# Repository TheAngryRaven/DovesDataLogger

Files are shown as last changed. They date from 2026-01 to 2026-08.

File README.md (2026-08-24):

# BirdsEye - GPS Lap Timer & Data Logger







A high-precision GPS-based lap timer and data logger designed for motorsports and track day enthusiasts. Features 25Hz logging, sector timing, RPM monitoring via tachometer, and multiple customizable display pages.

<p align="center">
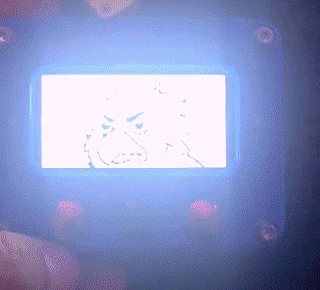
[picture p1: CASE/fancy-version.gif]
  
</p>
<p align="center">
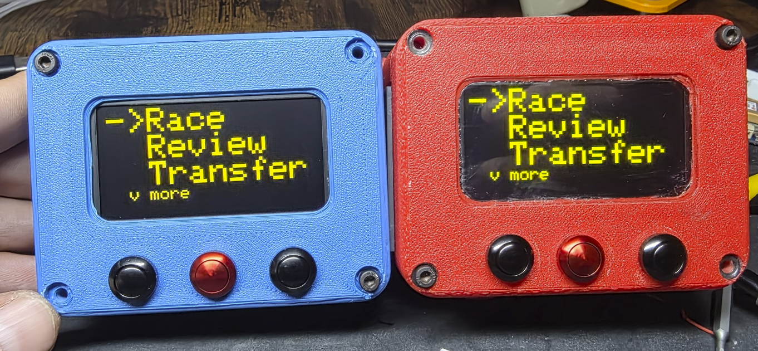
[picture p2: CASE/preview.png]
  
</p>
<p align="center">
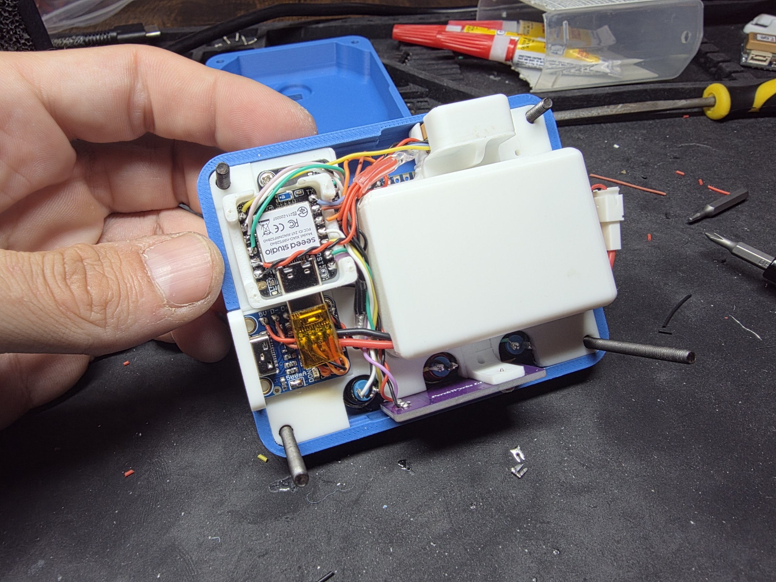
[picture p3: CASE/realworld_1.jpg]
  
</p>

## Features

### Core Functionality
- **25Hz GPS Logging** - High-frequency data capture straight to SD card
- **Accelerometer** - On-board 6-axis IMU when using Seeed XIAO nRF52840 Sense, +/-16g
- **RPM Monitoring** - Tachometer input with noise filtering for ignition systems
- **"Just Drive" Mode** - Automatic track detection, course detection, and lap timing — no manual selection needed
- **Sector Timing** - Optional 2 and 3-sector support for detailed performance analysis
- **Lap Anything** - Automatic waypoint-based lap timing when no track files match or no sectors configured
- **Lap Timing** - Current lap, best lap, last lap, and optimal lap calculation
- **Pace Comparison** - Real-time pace difference vs. best lap
- **Lap History** - Session-based lap history (up to 1000 laps)
- **Speed Display** - Large, easy-to-read speed display
- **Auto Power-Off** - Full shutdown (nRF52 System OFF, ~µA) instead of sleep — wakes on button press, engine start (tach pulse), or USB plug-in; no power switch needed
- **GPS Status Page** - Every boot shows a MyChron-style satellite view (sat count, HDOP, per-satellite signal bars) until GPS locks; any button skips it
- **DOVEX Format** - Crash-safe logging with reserved header for instant replay
- **Review Data** - Instant replay of DOVEX session headers on-device
- **Insta360 cameras pairing** - Automatically turn on, start recording, and sync GPS data directly to your camera once a session starts

#### WebApp Features (no login)
- **Bluetooth Downloads** - Can now download files directly to [LapWingData.com](https://LapWingData.com)
- **Bluetooth Firmware updates** - update from the latest stable or the experimental beta branch releases
- **Configure settings** - none of us want to fill in text with three buttons
- **Track Sync** - Update on-device track library via the webapp

#### To-Do
- **External Sensors** - Add thermocouple sensor / m8 circle connector
- **Pin Lock** - require pin to pull logs from device

### Display Pages
- GPS Status (boot page: satellites, HDOP, lock state, per-satellite signal bars)
- GPS Statistics (battery, satellites, HDOP, logging status)
- Speed (with current lap number)
- Tachometer (RPM with max RPM tracking)
- Current Lap Time
- Pace Off Best Lap (visual indicators when beating best)
- Best Lap Time
- Optimal Lap (combined best sectors with lap numbers)
- Lap History (paginated list)
- GPS Debug (distance to line, crossing status, etc.)

### Track Configuration
- Loads track layouts from JSON files on SD card
- Support for forward/reverse direction selection
- Optional sector timing lines (2 and 3 sectors)
- Easy to add new tracks - just add a JSON file

## Hardware Requirements

### Core Components
- **MCU**: Seeed XIAO nRF52840 Sense (64MHz ARM Cortex-M4 with FPU + BLE 5.0 + 6-axis IMU)
  - ~120 mA active draw with 2.45" screen; System OFF when powered down (µA-class + GPS backup draw)
  - Built-in battery charging circuit (BQ25101)
- **GPS**: u-blox SAM-M10Q (Matek SAM-M10Q recommended, found from most RC hobby shops)
  - Configured for 25Hz UBX binary (PVT) update rate
  - GPS-only constellation for maximum nav rate
  - **TODO** Update GPS tray to use bare $15 GPS module, battery backup is optional
- **Display**: 2.45" 128x64 OLED (SH110X or SSD1306 compatible)
  - I2C interface (address: 0x3C)
  - Software sleep/wake via I2C commands (~10uA when off)
- **SD Card**: Standard SD card module
  - FAT16/FAT32 formatted
  - 1 MHz SPI for EMI resistance
- **Battery**: 1500mAh 103050 LiPo
  - ~12.5 hours active; weeks-to-months powered down (System OFF)
- **Buttons**: 3x momentary pushbuttons for navigation
  - Left, Select/Enter, Right
  - RC low-pass filters recommended (10K + 100nF) for EMI rejection

### Optional Components
- **Tachometer Circuit**: Inductive pickup for RPM sensing
  - Input on pin D0
  - Noise filtering for ignition systems
  - *Circuit diagram: `tachometer-circuit.jpg` (README coming soon)*
  - diagram is missing required optocoupler and isolated dc-dc power supply

### Power Usage
- Active draw: ~120 mA with 2.45" OLED display
- Active battery life: ~12.5 hours continuous on 1500 mAh
- Powered down: nRF52 System OFF (µA-class MCU draw; GPS backup mode + board
  quiescent draw dominate) — expected weeks-to-months on 1500 mAh (bench
  measurement pending)
- Battery percentage and voltage displayed on stats page and charging screen

## Track Loading System

### How It Works

The system loads track configurations from JSON files stored on the SD card. Each track file can contain multiple layouts (e.g., "Full Course", "Short Course", "Chicane Bypass").

### SD Card Structure

```
SDCARD/
└── TRACKS/
    ├── OKC.json
    ├── BMP.json
    ├── PIQUET.json
    └── [your-track].json
```

### Track JSON Format

Two formats are supported. The device auto-detects which format is used.

**New format** (recommended, can use [LapWingData.com](https://LapWingData.com) to update tracks on the device):

```json
{
  "longName": "Orlando Kart Center",
  "shortName": "OKC",
  "defaultCourse": "Normal",
  "courses": [
    {
      "name": "Normal",
      "lengthFt": 3383,
      "start_a_lat": 28.4127081705638,
      "start_a_lng": -81.3797326641803,
      "start_b_lat": 28.4127303867932,
      "start_b_lng": -81.3795704875378,
      "sector_2_a_lat": 28.4119049886871,
      "sector_2_a_lng": -81.3790708193926,
      "sector_2_b_lat": 28.4118316342961,
      "sector_2_b_lng": -81.3791856652217,
      "sector_3_a_lat": 28.4115010664104,
      "sector_3_a_lng": -81.3799856475317,
      "sector_3_b_lat": 28.4115084390461,
      "sector_3_b_lng": -81.3798064021136
    }
  ]
}
```

**Older format** (still parsed, but the device falls back to Lap Anything because there's no `lengthFt` for course detection to rank by):

```json
[
  {
    "name": "Full Course",
    "start_a_lat": 28.41270817,
    "start_a_lng": -81.37973266,
    "start_b_lat": 28.41273039,
    "start_b_lng": -81.37957049,
    "sector_2_a_lat": 28.41190499,
    "sector_2_a_lng": -81.37907082,
    "sector_2_b_lat": 28.41183163,
    "sector_2_b_lng": -81.37918567
  }
]
```

**New format fields:**
- `longName` / `shortName`: track display names
- `defaultCourse`: which course to prefer (used by CourseDetector)
- `courses[].lengthFt`: track length in feet (enables automatic course detection ranking)

**Coordinate Requirements:**
- **Start/Finish Line**: `start_a_lat`, `start_a_lng`, `start_b_lat`, `start_b_lng` (required)
- **Sector 2 Line**: `sector_2_a_lat`, `sector_2_a_lng`, `sector_2_b_lat`, `sector_2_b_lng` (optional)
- **Sector 3 Line**: `sector_3_a_lat`, `sector_3_a_lng`, `sector_3_b_lat`, `sector_3_b_lng` (optional)

Each line is defined by two GPS coordinate points (A and B). The system detects crossing when you pass through the line segment between these points.

**Getting Coordinates:**
Use [Google Maps](https://maps.google.com) or your preferred mapping tool:
1. Right-click on a point → Copy coordinates
2. Paste into JSON (format: latitude, longitude)
3. Precision: 8 decimal places recommended for racing accuracy

### Adding a New Track

1. Create a new `.json` file in `SDCARD/TRACKS/` directory
2. Use the format shown above
3. Filename should be short (max 8 characters for FAT16 compatibility)
4. Example: `LAGUNA.json`, `COTA.json`, `BRANDS.json`

The track will automatically appear in the track selection menu on next boot.

## Device Settings

Settings are stored in `/SETTINGS.json` on the SD card. The file is created automatically on first boot with random default values. Missing keys are auto-populated on boot when firmware is updated.

```json
{
  "bluetooth_name": "DovesDataLogger-042",
  "bluetooth_pin": "7391",
  "driver_name": "Driver",
  "lap_detection_distance": "7",
  "waypoint_detection_distance": "30",
  "waypoint_speed": "30",
  "spark_mode": "wasted",
  "cylinder_count": "1",
  "display_invert": "normal"
}
```

| Setting | Description | Default |
|---|---|---|
| `bluetooth_name` | BLE device name visible during pairing | Random (e.g. `DovesDataLogger-042`) |
| `bluetooth_pin` | PIN displayed on device for webapp pairing | Random 4-digit |
| `race_mode` | Circuit-vs-sprint tiebreak when both track kinds are within detection range (`sprint` always prefers the sprint track; `circuit` yields only on an event day) | `circuit` |
| `driver_name` | Driver name logged in DOVEX session header | `Driver` |
| `lap_detection_distance` | Crossing detection threshold in meters | `7` |
| `waypoint_detection_distance` | Waypoint proximity zone in meters (Lap Anything) | `30` |
| `waypoint_speed` | Minimum speed in mph to activate lap timing | `30` |
| `spark_mode` | How often the plug on the clamped wire fires — the **only** setting that scales RPM: `wasted` = once per revolution (2-stroke, or 4-stroke wasted spark), `single` = once per two revolutions (4-stroke single-fire, i.e. a traditional distributor or magneto) | `wasted` |
| `display_invert` | Screen colours: `normal` is the white-on-black it has always been, `inverted` swaps them (black text on a lit screen) for glare | `normal` |
| `cylinder_count` | The engine's **actual** cylinder count — enter 8 for a V8. It does **not** scale RPM: the pickup is one clamp on one plug wire, so it sees one cylinder's ignition and `spark_mode` alone sets the math. ⚠️ Above 1 cylinder, crank RPM is **inferred from that one cylinder's ignition pulses** — between firings the reading is an assumption, and a cylinder that drops out reads as a stopped engine. This is normal, expected behaviour for every clamp-on inductive tach | `1` |

## Data Format

DOVEX files (`.dovex`) use a reserved **1 KB** header for session metadata, with GPS data streaming after byte 1024. This enables crash-safe logging and instant on-device replay.

**Structure:**
```
Bytes 0-1023:    Session header (written when session ends)
  Line 1:        datetime,driver,course,short_name,best_lap_ms,optimal_ms,device_name,race_mode
  Line 2:        2025-03-11 14:30:00,Driver,Normal,OKC,62345,61890,ApexTurbo,CIRCUIT
  Line 3:        laps_ms                                                     (column label)
  Line 4:        65432,63210,62345,64567,...                                 (all lap times in ms)
  Remaining:     \n padding to byte 1024

Bytes 1024+:     GPS data
  Header row:    timestamp,sats,hdop,lat,lng,speed_mph,altitude_m,heading_deg,h_acc_m,rpm,accel_x,accel_y,accel_z,Temp1,Junction1,Temp2
  Data rows:     1741128001234,12,0.8,28.41270817,-81.37973266,87.32,125.45,182.34,1.25,8450,0.123,-0.945,0.032,650.0,33.3,23.4
```

The 1 KB header fits about 100 lap times at ~8 characters per entry. If the device loses power mid-session the header is left blank but all GPS data after byte 1024 is still valid and recoverable — the metadata write is the LAST thing a clean session does, so file integrity is independent of it.

**File naming:** `20YYMMDD_HHMM.dovex` (e.g. `20240115_1430.dovex`)

### Column Reference

- **timestamp**: Unix timestamp in milliseconds (since Jan 1, 1970)
- **sats**: Number of GPS satellites
- **hdop**: Horizontal Dilution of Precision (GPS accuracy indicator)
- **lat/lng**: GPS coordinates (8 decimal places)
- **speed_mph**: Speed in miles per hour (2 decimal places)
- **altitude_m**: Altitude in meters (2 decimal places)
- **heading_deg**: Heading of motion in degrees (0-360, 2 decimal places, from UBX headMot)
- **h_acc_m**: Horizontal accuracy estimate in meters (2 decimal places, from UBX hAcc)
- **rpm**: Engine RPM from tachometer input
- **accel_x/y/z**: Accelerometer g-force from onboard LSM6DS3 IMU (3 decimal places, logs `0.000` if IMU not available)
- **Temp1/Junction1**: SensorEgg wireless EGT + cold junction in °C (1 decimal place; literal `nan` when the egg link is stale, invalid, or the POC is compiled out)
- **Temp2**: SensorEgg aux intake-air thermistor in °C (v2 eggs; `nan` on v1 eggs and everything above)

## File Structure

```
DovesDataLogger/                  # repo root
├── BirdsEye/                     # sketch (folder name must match BirdsEye.ino)
│   ├── BirdsEye.ino              # Entry point: globals, setup(), loop(), state machine
│   ├── project.h                 # Shared types, debug macros, constants
│   ├── display_config.h          # Display driver abstraction (SH110X/SSD1306)
│   ├── gps_config.h              # GPS configuration constants (baud, nav rate)
│   ├── images.h                  # PROGMEM bitmap data (splash, animations)
│   ├── accelerometer.{h,ino}     # LSM6DS3 IMU init and g-force reads
│   ├── bluetooth.{h,ino}         # BLE service (file transfer, settings, track sync)
│   ├── display_pages.{h,ino}     # All page rendering functions (displayPage_*())
│   ├── display_ui.{h,ino}        # Display init, button handling, menu navigation
│   ├── gps_functions.{h,ino}     # GPS init, PVT callback, time conversion, logging
│   ├── replay.{h,ino}            # Instant DOVEX header replay + haversine helper
│   ├── sd_functions.{h,ino}      # SD init, track JSON parsing, track manifest
│   ├── settings.{h,ino}          # Persistent JSON settings (/SETTINGS.json)
│   └── tachometer.{h,ino}        # Falling-edge ISR, Kalman-filtered RPM
│
├── .github/workflows/            # CI: compile-sketch + arduino-lint
├── CASE/                         # 3D printable enclosure files (STL + STEP)
├── SDCARD/TRACKS/                # Example track JSON files
├── TACHOMETER/                   # Tachometer circuit documentation
├── README.md                     # This file
├── CLAUDE.md                     # AI-assistant project guide
└── LICENSE                       # GPL v3
```

## Required Libraries

| Library | Purpose |
|---|---|
| Adafruit GFX | Graphics primitives |
| Adafruit SSD1306 | SSD1306 OLED driver (if using SSD1306) |
| Adafruit SH110X | SH110X OLED driver (if using SH1106) |
| SparkFun u-blox GNSS v3 | UBX binary PVT GPS interface |
| ArduinoJson 6.x | Track file and settings JSON parsing |
| SdFat | SD card (FAT16/FAT32) |
| [DovesLapTimer](https://github.com/TheAngryRaven/DovesLapTimer) | Lap/sector timing |
| [CourseManager](https://github.com/TheAngryRaven/DovesLapTimer) | Auto course detection + Lap Anything (part of DovesLapTimer) |
| Seeed Arduino LSM6DS3 | Onboard IMU accelerometer/gyro (Sense variant) |
| Bluefruit nRF52 | BLE (built into Seeed nRF52 board package) |

**Board package:** Use "Seeed nRF52 Boards" (non-mbed). The mbed variant uses ArduinoBLE instead of Bluefruit and is incompatible.

## Setup & Usage

### Initial Setup

1. **Format SD Card**
   - Format as FAT32 (or FAT16 for maximum compatibility)
   - Create folder structure: `TRACKS/` in root

2. **Add Track Files**
   - Copy or create `.json` track files in `SDCARD/TRACKS/`
   - See "Track Loading System" section above

3. **Flash Firmware**

   **Option A — prebuilt release (no toolchain needed):**
   - Download the latest `BirdsEye.uf2` from the [Releases page](https://github.com/TheAngryRaven/DovesDataLogger/releases)
   - Double-tap the XIAO's reset button to mount the `XIAO-SENSE` bootloader drive
   - Drag `BirdsEye.uf2` onto that drive — the board reboots into the new firmware automatically

   **Option B — build from source:**
   - Install "Seeed nRF52 Boards" board package (non-mbed)
   - Install required libraries (see table above)
   - Select board: "Seeed XIAO nRF52840 Sense"
   - Compile and upload `BirdsEye/BirdsEye.ino`

4. **Hardware Assembly**
   - *3D printed case assembly instructions coming soon*
   - *Tachometer circuit README coming soon*
   - STL files available in `CASE/` directory
   - Note: Requires some glue, measuring, and jeweler's screws

### Usage

**Button Controls:**
- **Left/Right Buttons**: Navigate between pages
- **Middle Button**: Select/Enter (in menus), Quick-jump to Pace/Best Lap (while racing)
- **Hold Left + Right (5s)**: Power off (from main menu)
- **Hold Select + Side (5s)**: Reboot device (from any page)

**Startup Sequence ("Just Drive" mode):**
1. Wake (button / engine start / USB) → Boot screen → **GPS Status page**
   (satellite count, HDOP, signal bars). Any button skips to the main menu;
   3 seconds after a stable GPS time lock it advances automatically —
   straight into race mode if the engine woke the device or is running
2. Start driving — device auto-enters race mode at 10+ mph or 500+ RPM
3. GPS fix acquired → DOVEX logging starts immediately
4. Track auto-detected via GPS proximity → course detection begins
5. Lap timing activates automatically (sector timing if configured, "Lap Anything" otherwise)

**Ending Session:**
- **Auto-idle**: stops automatically after 60 seconds below 2 mph
- **Manual**: navigate to "END RACE" page (only accessible when speed < 2 mph), confirm to stop
- Returns to main menu

**Power Off (System OFF):**
- Activates via 5-second left+right hold on the main menu, or automatically
  after 5 minutes idle on the main menu (or 5 minutes on the GPS status page
  with no lock and no engine)
- Everything powers down — display, GPS (µA backup mode, config/ephemeris
  retained), IMU, and the MCU itself (nRF52 System OFF) — no power switch needed
- Wakes on any button press, a tachometer pulse (engine start boots straight
  toward race mode via the GPS status page), or plugging in USB
- Waking is a fresh boot (~1-2 s); the GPS warm-starts from backup RAM in
  seconds
- **Charging**: plugging in USB wakes the device into a charging screen
  (10 s, then dark); any button fully wakes it — replay/transfer work while
  plugged in, and it returns to charging after 60 s of no buttons. Unplugging
  powers it off

## Technical Details

### GPS Configuration
- **Protocol**: UBX binary (PVT messages via SparkFun callback)
- **Update Rate**: 25Hz racing (40ms between fixes); 5Hz + NAV-SAT during the boot GPS status page
- **Mode**: Automotive dynamic model
- **Constellations**: GPS-only (max nav rate, no multi-constellation overhead)
- **Baud Rate**: 57600 (auto-configured from 9600 default on first boot; boot
  probes 57600 first and sends the backup-mode wake byte, so warm boots
  reconnect near-instantly and a misbehaving module is auto-recovered)

### SD Card Logging
- **Write Frequency**: Every PVT update (~25Hz)
- **Flush Interval**: Every 10 seconds (prevents data loss)
- **SPI Speed**: 1 MHz (reduced for EMI resistance)
- **Access Arbitration**: Mutex prevents concurrent access from logging, replay, BLE, and track parsing

### Tachometer Input
- **Input Pin**: D0
- **Detection**: Falling-edge interrupt
- **Filtering**: 3ms minimum pulse gap (supports up to ~20,000 RPM)
- **Dead Time**: Volatile flag gating prevents interrupt storms from noisy ignition pickups
- **Update Rate**: 3Hz with EMA filter (alpha 0.20)
- **Timeout**: 500ms with no pulse = engine stopped (RPM 0)
- **Configuration**: `spark_mode` sets the pulses per revolution on the clamped wire — 1 for a 2-stroke or wasted-spark plug, 0.5 for a 4-stroke single-fire (distributor/magneto) plug. The engine's cylinder count does **not** enter it: one clamp reads one cylinder, and its firing rate is the crank speed

### Display Update Rate
- **Refresh**: 3Hz (reduces power consumption)
- **Exception**: Instant refresh on button press

### Battery Monitoring
- **Update Interval**: 5 seconds
- **Voltage Divider**: 1510Ω / 510Ω ratio
- **Display**: Percentage (3.3V = 0%, 4.2V = 100%) with voltage readout

## Adding Custom Data Pages

The page system is straightforward to extend. Each page needs:

1. **Page Constant** in `BirdsEye.ino` (in the running page section):
   ```cpp
   const int MY_NEW_PAGE = 13;
   ```

2. **Display Function** in `display_pages.ino`:
   ```cpp
   void displayPage_my_new_page() {
     resetDisplay();
     display.println(F("My Custom Page"));
     // Your display code here
     safeDisplayUpdate();
   }
   ```

3. **Page Routing** in `displayLoop()` in `display_ui.ino`:
   ```cpp
   else if (currentPage == MY_NEW_PAGE) {
     displayPage_my_new_page();
   }
   ```

4. **Update Page Range** in `BirdsEye.ino`:
   ```cpp
   int runningPageEnd = MY_NEW_PAGE; // Update to new last page
   ```

Look at existing pages like `displayPage_gps_speed()` or `displayPage_tachometer()` in `display_pages.ino` as examples.

## Related Projects

- **Data Viewer**: [DovesDataViewer](https://github.com/TheAngryRaven/DovesDataViewer)
  - Web-based viewer for logged data
  - Preview at [LapWingData.com](https://LapWingData.com)

- **Core GPS Timing Library**: [DovesLapTimer](https://github.com/TheAngryRaven/DovesLapTimer)
  - Line-crossing detection
  - Sector timing
  - Optimal lap calculation

## Future Enhancements

- **Browser-based simulator (in progress)**: the old Wokwi simulator files
  (`diagram.json`, `libraries.txt`) have been removed — they described a dead
  Arduino-Mega/SSD1306 target. They're being replaced by a WASM build of the
  real firmware (behind the `SIM` compile flag, sources under `BirdsEye/sim/`)
  that runs in the browser and replays real `.dovex` sessions, embedded in
  [DovesDataViewer](https://github.com/TheAngryRaven/DovesDataViewer)
- Pin lock - require PIN to pull logs from device
- Additional sensor inputs (exhaust temp, water temp)
- WiFi automatic data transfer
- Real-time telemetry to pit crew

## Notes

- Crossing detection threshold: configurable via `lap_detection_distance` setting (default 7m)
- Maximum track locations: 1000
- Maximum layouts per track: 10
- Maximum lap history: 1000 laps per session
- GPS coordinates stored with 8 decimal places (~1.1mm precision)
- BLE disconnect triggers automatic device reboot (ensures settings changes take effect)

## Contributing

Contributions are welcome! See [CONTRIBUTING.md](CONTRIBUTING.md) for how
to build the firmware, run the host tests, and the PR workflow.
[ARCHITECTURE.md](ARCHITECTURE.md) explains how the system fits together.
Found a security issue? Please follow [SECURITY.md](SECURITY.md) and report
it privately. All participants are expected to follow our
[Code of Conduct](CODE_OF_CONDUCT.md).

## License

GPL v3 — see [LICENSE](LICENSE) for details.

## Support

For issues and questions, please use [GitHub Issues](https://github.com/TheAngryRaven/DovesDataLogger/issues)
(search existing ones first). For security reports, see [SECURITY.md](SECURITY.md).

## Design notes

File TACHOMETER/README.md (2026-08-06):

# Tachometer Circuits

### Paid Circuits

Spent well over a year on this, and well I gave up, I want to build a much better datalogger, and this damn circuit is holding me up.

This was designed by a professional RF engineer, and work drastically better than the ones I managed to hobble together.

<p align="center">
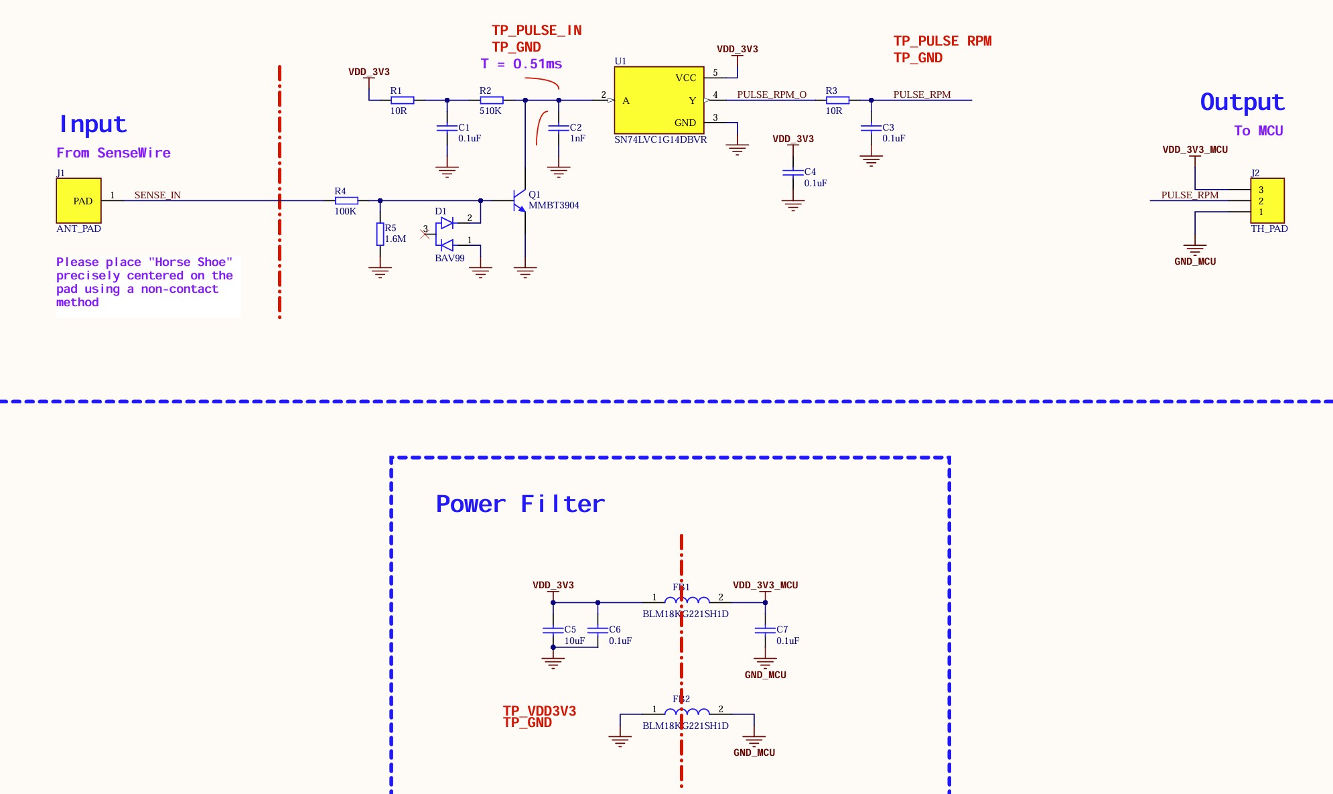
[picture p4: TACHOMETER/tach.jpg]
  
</p>

I've built and tested them and they are now available for purchase here
https://www.paypal.com/ncp/payment/D5QVSKE7W4CFQ

### My Circuits

These circuits are semi buildable at home, but really wouldnt reccoment.
If you decide to build EITHER circuit, if you do not connect an isolated dc-dc converter, you will suffer from serious issues as the powerline swings -+10v+ from the magneto driven ignition

* the first circuit, has a ~9800 RPM (4t wasted spark or 2t) limit due to it generating 5mS pulses each spark.
* the second circuit would work at drastically higher RPMs but I need to make sure the coil ringing isn't causing higher than should-be reads

This is the dc-dc converter I used, it can "convert" 3v to 3v. 

Actual Part Number: MIE1W0505BGLVH

Prototyping part: [https://www.pololu.com/product/5384](https://www.pololu.com/product/5384)

And then a schmidt trigger+optocoupler to send the signal out.
The Schmitt Trigger I used is a HEX inverter... you only need one... but the only ICS with one trigger, are super duper small. Both of these are standard cheap parts nothing fancy.

---

Example of the mess I am currently dealing with, I even had a board made for the first version and managed to get it successfully working to prove the proof of concept

<p align="center">
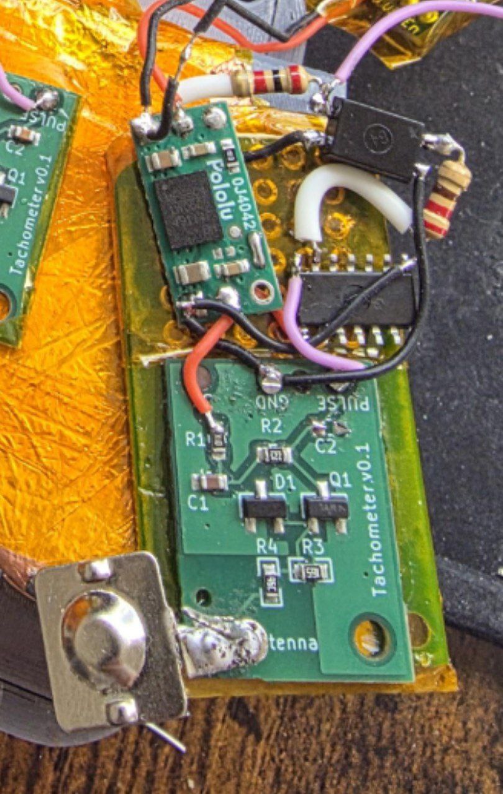
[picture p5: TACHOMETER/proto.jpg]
  
</p>

---
<p align="center">
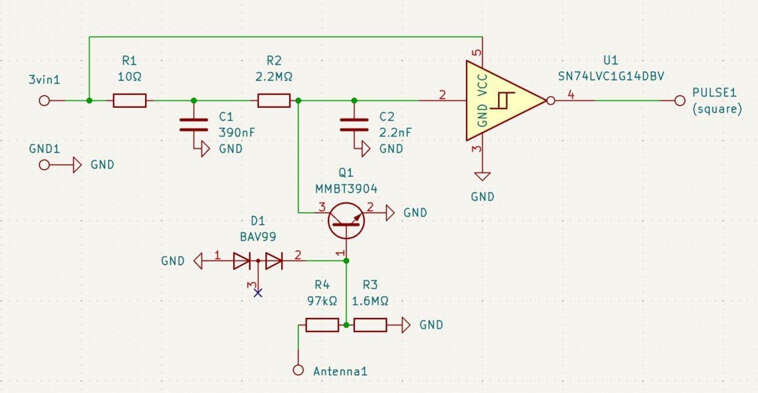
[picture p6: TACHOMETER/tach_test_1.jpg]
  
</p>
---
<p align="center">
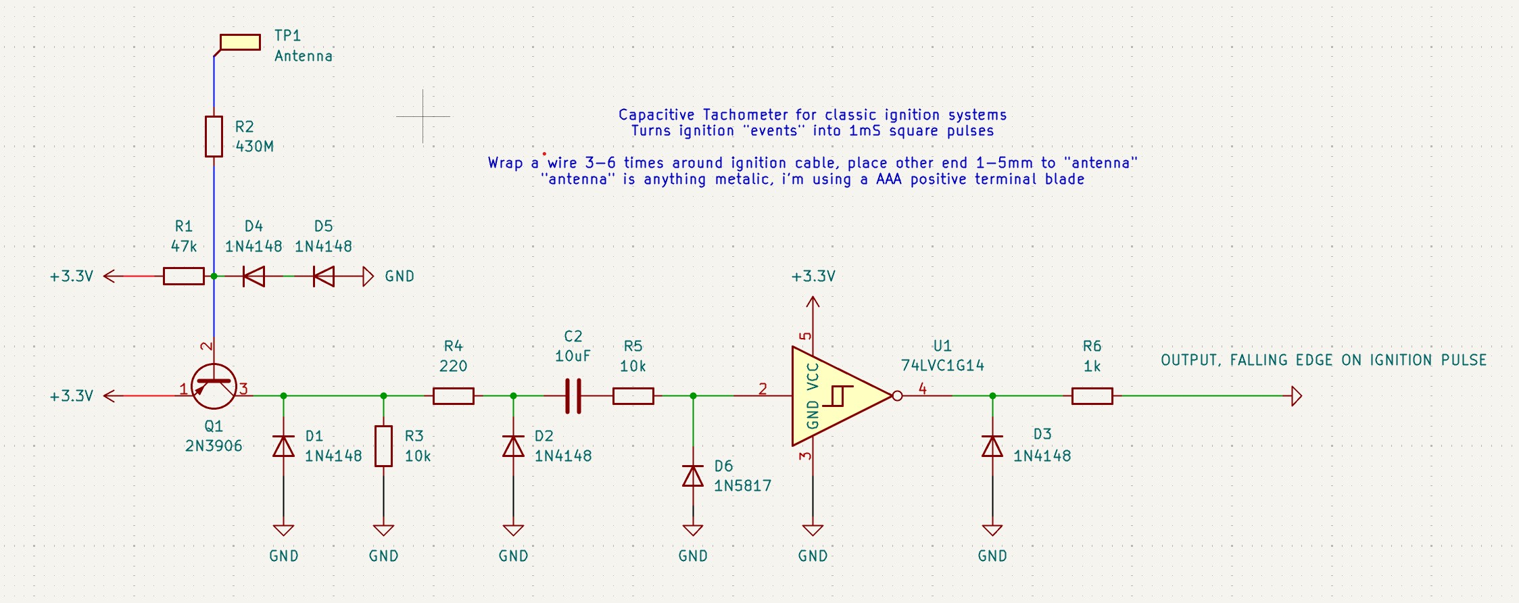
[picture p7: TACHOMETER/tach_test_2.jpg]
  
</p>

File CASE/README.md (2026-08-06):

# Datalogger case "build guide"
This is an advance level build, in a very tight case, that I designed on a computer screen where things look much bigger.
I built this, you can too, stay strong.

The build guide is still a to-do... but with a couple of pictures and a pin guide, I think yall got it.... maybe do a dry run on a bench to make sure its wired right :^)

## Preview
<p align="center">
  
</p>
<p align="center">
  
</p>
<p align="center">
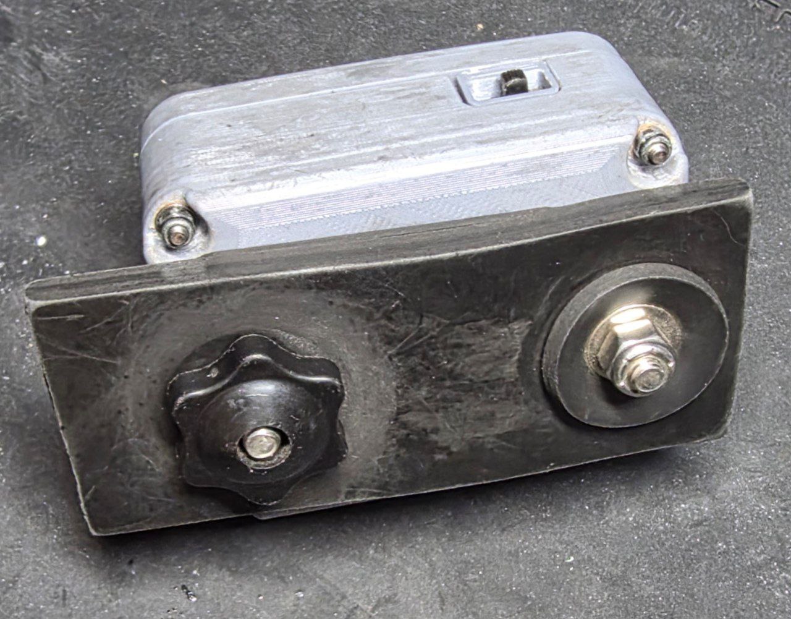
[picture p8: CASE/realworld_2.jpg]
  
</p>

## Materials List
Use these parts as a reference, you can buy most of the parts from digikey in a single order

 - Seeed XIAO NRF52840 (sense version optional)
	- https://www.amazon.com/dp/B09T9VVQG7
 - SPI Flash Module
	- https://www.adafruit.com/product/6039
 - USBC Charger Module 
	- https://www.adafruit.com/product/4410
 - MATEK SAM-m10Q GPS, super easy to solder
 	- CAN SUBSTITUTE BARE GPS MODULE
 	- https://www.digikey.com/en/products/detail/u-blox/SAM-M10Q-00B/16672678
 - 2.45" 128x64 OLED LCD (SH110X or SSD1306 compatible)
	- MODIFIED for i2c mode
	- https://www.amazon.com/dp/B0CFF1XC2T
 - 1500mAh 103050 LiPo (or smaller)
	 - https://www.amazon.com/dp/B09DPNCLQZ
 - 3X 8mm panel mount buttons
	- https://www.amazon.com/dp/B0FSZ446QM
 - JST-PH 2.0 Pigtails
	- https://www.amazon.com/dp/B07NWNPB77
 - little USBC-4 pin breakout plug
	- https://www.amazon.com/dp/B0B9N4DHTW
 - tachometer (us shipping only)
 	- https://www.paypal.com/ncp/payment/D5QVSKE7W4CFQ
 - 1mm Acrylic sheet
 - 4x m3 30mm + nylock nuts
 - 8x m3 washers
 - 10x 2mm x 4mm screws
 - 4x 1mm x 4mm screws
 - bunch of 30AWG silicone wires

## Mounting Hardware  (/case-back.3MF)
#### Parts
 - 2x 1/4 carriage bolt 1in long
 - 1x 1/4 nylon nut
 - 1x 1/8 thick 1/4 ID rubber washer
 - 1x 1/4 ID metal washer
 - 1/16th thick rubber sheet 2in wide
 - 1/4in thick rubber 2in wide

#### Assembly
 - cut thin rubber strip same width as device
 - cut thick strinp a thumbs width longer than the device to allow for easier grip
 - punch holes in straps to match the two outer bolt holes
 - bolt one cariage bolt tight with nylon nut and rubber/metal washers
 - use chunky hand turn nut on other side to allow to quick release/attachment

## Mounting Hardware  (/case-back-single.3MF)
#### Parts
 - 1x 5/16 carriage bolt 1-1/4in long
 - 1x 5/16 ID 1/8th thick nylon washer
 - 1x 5/16 nylon nut
 - 1x 5/16 metal washer
 - 1-3x 1/8th rubber washer

#### Assembly
 - nylon washer against datalogger body so it sits off a bit from the wheel
 - rubber washer between datalogger and wheel for vibration dampning
 - metal washer and nut from backside of wheel

---
### Build guide (very much todo)

- print all the parts
- line them up with the cutout
- the MCU tray should overhang towards the USBC charger
- good luck until i cut and upload the build video

#### Tips
 - DONT LET THE BATTERY WIGGLE AROUND, IT WILL CAUSE FAILURE EVENTUALLY
 - DONT LET THE GPS WIGGLE AROUND EITHER
 - bit of paper works great for both
---
#### Wiring guide

The Seeed XIAO nRF52840 (Sense) has limited pins — almost every one is used. Reference the [official XIAO nRF52840 pinout](https://wiki.seeedstudio.com/XIAO_BLE/) for the physical board layout.

| XIAO Pin | Arduino ID | Function | Connects To |
|---|---|---|---|
| D0 / A0 | 0 | Tachometer input | Tach pickup signal wire (via 1K + 100nF RC filter to GND, optional TVS diode). INPUT_PULLUP, falling-edge ISR. |
| D1 / A1 | 1 | Button 1 (Left) | Panel mount button, other leg to GND (via 10K + 100nF RC filter to GND). INPUT_PULLUP. |
| D2 / A2 | 2 | Button 2 (Select) | Panel mount button, other leg to GND (via 10K + 100nF RC filter to GND). INPUT_PULLUP. |
| D3 / A3 | 3 | Button 3 (Right) | Panel mount button, other leg to GND (via 10K + 100nF RC filter to GND). INPUT_PULLUP. |
| D4 / A4 / SDA | 4 | I2C SDA | OLED display SDA (address 0x3C). Directly wired, no external pullup needed (internal pullups). |
| D5 / A5 / SCL | 5 | I2C SCL | OLED display SCL. Directly wired, no external pullup needed. |
| D6 / TX | -- | GPS UART TX | MATEK SAM-M10Q RX pin (Serial1 TX). |
| D7 / RX | -- | GPS UART RX | MATEK SAM-M10Q TX pin (Serial1 RX). 57600 baud. |
| D8 / SCK | -- | SPI Clock | SD card slot CLK. |
| D9 / MISO | -- | SPI MISO | SD card slot DO (data out). |
| D10 / MOSI | -- | SPI MOSI | SD card slot DI (data in). |
| -- | PIN_SPI_CS | SPI Chip Select | SD card slot CS — **hardwired to GND on the PCB** (always selected, pass -1 to SdFat). |
| -- | PIN_VBAT | Battery ADC | LiPo positive via onboard 1510/510 ohm voltage divider. Only safe `analogRead()` pin. |
| -- | VBAT_ENABLE | Battery ADC enable | Directly controlled — set LOW to enable battery reads. |
| -- | PIN_CHARGING_CURRENT | Charge rate | Set HIGH for fast charging (~100mA). Directly controlled. |
| (internal) | -- | LSM6DS3 IMU | Onboard I2C on Wire1 (Sense variant only), address 0x6A. No external wiring needed. |
| BAT pads | -- | Battery | 103050 1500mAh LiPo. Use the JST connector or solder to the BAT+/BAT- pads. |
| USB-C | -- | Power / Debug | USB-C port for charging, programming, and serial debug. |

**Power wiring:**
- LiPo connects to the adafruit battery charger
- adafruit power wiring:
  - wire dead simple usb-c breakout to 5v, ground, data+/- and plug it into the xiao
  - battery and ground pads, to xiao battery pads
  - desolder JST socket on adafruit board, solder pigtail directly to adafruit board

**Signal wiring tips:**
- Keep tach wire (D0) physically separated from button wires to reduce EMI coupling
- Use shielded cable for tach if possible, ground shield at MCU end only
- RC filters on buttons and tach are strongly recommended for track/racing environments — ignition noise will cause phantom inputs without them

---

## Pricing estimates

Pricing calculations were done on 8/6/2026.
Sadly this cannot also account for shipping from various vendors, or being forced to bulk order items like screws

Since I have also needed to buy some bulk I am willing to sell a bundled parts kit + print service
https://www.paypal.com/ncp/payment/5GT3CFJCLHMTE

| Datalogger | 111.21 | Mount A | 4.82 | Mount B | 4.05 |
|---|---|---|---|---|---|
| MCU | 15.9 | carriage bolts | 0.9 | Mounting type B | 4.05 |
| GPS | 13.36 | plastic knob | 1.5 | carriage bolt | 0.98 |
| Memory | 12.5 | rubber strap | 1.69 | nylon washer | 0.9 |
| Power board | 5.95 | rubber guard | 0.2 | rubber washer x3 | 1.89 |
| usbc breakout | 1.75 | lock nut | 0.12 | lock nut | 0.26 |
| Screen | 15 | metal washer | 0.05 | metal washer | 0.02 |
| power pigtail | 0.8 | rubber washer | 0.36 | -- | -- |
| buttons | 15.2 | -- | -- | -- | -- |
| battery | 8 | -- | -- | -- | -- |
| tachometer  | 20 | -- | -- | -- | -- |
| screws | 1.5 | -- | -- | -- | -- |
| wire and such  | 1 | -- | -- | -- | -- |
| acrylic  | 0.25 | -- | -- | -- | -- |
| 3d print | 10 | -- | -- | -- | -- |
| tach wire + print | 3 | -- | -- | -- | -- |

Message support@perchwerks.com if you have any questions, or need help acquiring supplies

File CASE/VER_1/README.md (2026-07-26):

# Datalogger case "build guide"
This is an advance level build, in a very tight case, that i designed on a computer screen where things look much bigger.
I built this, you can too, stay strong.

The build guide is still a to-do... but with a couple of pictures and a pin guide, I think yall got it.... maybe do a dry run on a bench to make sure its wired right :^)

<p align="center">
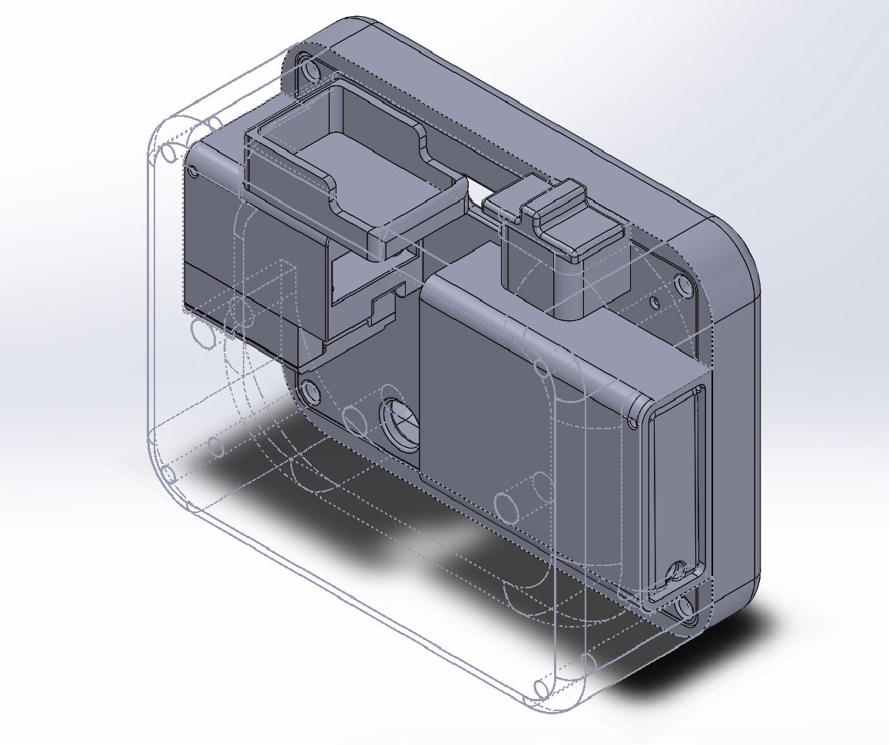
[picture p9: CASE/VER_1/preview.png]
  
</p>
<p align="center">
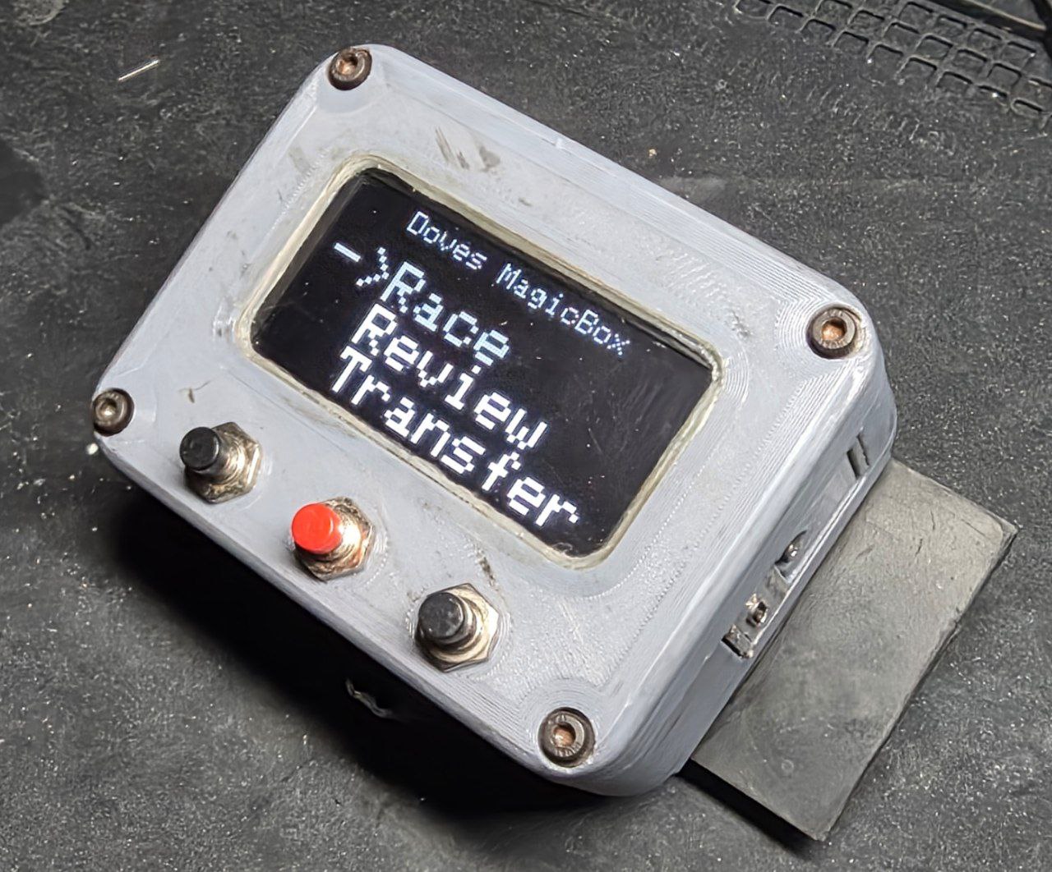
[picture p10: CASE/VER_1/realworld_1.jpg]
  
</p>
<p align="center">
  
</p>

## Materials List
 - bunch of wires
 - Seeed XIAO NRF52840 (sense optional but cooler if you did)
 - sd card slot
 - MATEK SAM-m10Q GPS, super easy to solder up and has a backup battery
 - 2.45" 128x64 OLED LCD (SH110X or SSD1306 compatible)
 - 1500mAh 103050 LiPo
 - 3X 7mm panel mount buttons
 - 1mm Acrylic sheet
 - 4x m3 40mm + nylock nuts
 - 2mm heat inserts, 4mm long
 - metal rod or such for pins on battery and sd card doors

## Mounting Options
option one
 - 1x 5/8ths carriage bolt
 - bolt to kart with washers and such

option two
 - 2x 1/4 carriage bolt
 - 1/16th thick rubber sheet 2in wide
 - 1/4in thick rubber 2in wide
 - cut thin rubber strip same width as device
 - cut thick spray a thumbs width longer
 - >punch holes in straps to match the two outer bolt holes
 - bolt one cariage bolt tight with nylon nut
 - use chunky hand turn nut on other side to allow to quick release/attachment

### Build guide (very much todo)

- print all the parts
- The GPS/SDCard/MCU trays should all be superglued together
- melt heat insert for sd card tray
- line up front/back case with the baseplate between them, mark case holes on baseplate
- glue mcu tower to baseplate with the SD door facing outwards
  - the panel to cover the MCU is screwed on with 4 tiny jewelers screws, don't glue it on unless you hate yourself
- repeat process for power switch
- SOLDER WIRES FOR SD CARD BEFORE GLUING BATTERY TRAY
- add heat insert to battery box
- setup and glue battery to baseplate
  - battery tray might stick out a smidge, sorry
- screw on/solder display
- finish soldering everything else
- be fuckin careful with the wiring 
- [tachometer coming soon, need to hand solder SMD components]

**Note:** Battery ground goes to battery ground on the XIAO, the battery positive goes to the switch, the switch then goes to the battery positive pad on the XIAO

#### Tips
 - add hot glue to GPS so it does not wiggle and ruin the sticker antenna, maybe add a piece of tissue paper to prevent this
 - DONT LET THE BATTERY WIGGLE AROUND, IT WILL CAUSE FAILURE EVENTUALLY
 - stay calm, trust me i know its rough

#### Pin guide

The Seeed XIAO nRF52840 (Sense) has limited pins — almost every one is used. Reference the [official XIAO nRF52840 pinout](https://wiki.seeedstudio.com/XIAO_BLE/) for the physical board layout.

| XIAO Pin | Arduino ID | Function | Connects To |
|---|---|---|---|
| D0 / A0 | 0 | Tachometer input | Tach pickup signal wire (via 1K + 100nF RC filter to GND, optional TVS diode). INPUT_PULLUP, falling-edge ISR. |
| D1 / A1 | 1 | Button 1 (Left) | Panel mount button, other leg to GND (via 10K + 100nF RC filter to GND). INPUT_PULLUP. |
| D2 / A2 | 2 | Button 2 (Select) | Panel mount button, other leg to GND (via 10K + 100nF RC filter to GND). INPUT_PULLUP. |
| D3 / A3 | 3 | Button 3 (Right) | Panel mount button, other leg to GND (via 10K + 100nF RC filter to GND). INPUT_PULLUP. |
| D4 / A4 / SDA | 4 | I2C SDA | OLED display SDA (address 0x3C). Directly wired, no external pullup needed (internal pullups). |
| D5 / A5 / SCL | 5 | I2C SCL | OLED display SCL. Directly wired, no external pullup needed. |
| D6 / TX | -- | GPS UART TX | MATEK SAM-M10Q RX pin (Serial1 TX). |
| D7 / RX | -- | GPS UART RX | MATEK SAM-M10Q TX pin (Serial1 RX). 57600 baud. |
| D8 / SCK | -- | SPI Clock | SD card slot CLK. |
| D9 / MISO | -- | SPI MISO | SD card slot DO (data out). |
| D10 / MOSI | -- | SPI MOSI | SD card slot DI (data in). |
| -- | PIN_SPI_CS | SPI Chip Select | SD card slot CS — **hardwired to GND on the PCB** (always selected, pass -1 to SdFat). |
| -- | PIN_VBAT | Battery ADC | LiPo positive via onboard 1510/510 ohm voltage divider. Only safe `analogRead()` pin. |
| -- | VBAT_ENABLE | Battery ADC enable | Directly controlled — set LOW to enable battery reads. |
| -- | PIN_CHARGING_CURRENT | Charge rate | Set HIGH for fast charging (~100mA). Directly controlled. |
| (internal) | -- | LSM6DS3 IMU | Onboard I2C on Wire1 (Sense variant only), address 0x6A. No external wiring needed. |
| BAT pads | -- | Battery | 103050 1500mAh LiPo. Use the JST connector or solder to the BAT+/BAT- pads. |
| USB-C | -- | Power / Debug | USB-C port for charging, programming, and serial debug. |

**CRITICAL: Do NOT call `analogRead()` on pins D0-D5 (A0-A5).** On the nRF52840, `analogRead()` permanently disables the digital input buffer on that pin for the rest of the session. Every analog-capable pin is dual-purpose (tach, buttons, I2C), so calling `analogRead()` on any of them will silently break that function. PIN_VBAT (pin 32) is the only safe analog pin — it's a dedicated battery ADC with no digital function.

**Power wiring:**
- LiPo connects to the XIAO's battery pads/JST connector (onboard BQ25100 charge IC handles charging via USB-C)
- No external voltage regulator needed — the XIAO regulates 3.3V internally

**Signal wiring tips:**
- Keep tach wire (D0) physically separated from button wires to reduce EMI coupling
- Use shielded cable for tach if possible, ground shield at MCU end only
- RC filters on buttons and tach are strongly recommended for track/racing environments — ignition noise will cause phantom inputs without them

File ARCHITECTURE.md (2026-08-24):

# Architecture

This document explains how BirdsEye is put together and the reasoning
behind the parts that aren't obvious from reading the code. For the
exhaustive file-by-file map and the full constant tables, see
[`CLAUDE.md`](CLAUDE.md); this doc is the narrative version for humans.

## Overview

BirdsEye is a GPS lap timer and data logger built on the **Seeed XIAO
nRF52840 Sense** — an ARM Cortex-M4F with 256 KB RAM, 1 MB flash, BLE 5.0,
and an onboard LSM6DS3 IMU. It runs the Adafruit-based Bluefruit nRF52
core (not mbed), which means a SoftDevice handles the BLE stack and a UF2
bootloader handles flashing.

The device drives at 25 Hz off the GPS, logs to an SD card, shows live
timing on a 128×64 OLED, reads RPM from an inductive tachometer, and
serves logged files over BLE.

## Source layout

```
BirdsEye/
  BirdsEye.ino          entry point: globals, setup(), loop(), state machine
  <subsystem>.ino + .h  one module per subsystem (see below)
  <unit>.cpp + .h       pure, Arduino-free logic (host-testable)
  sim/                  browser/WASM simulator host build (SIM flag; see below)
tests/                  doctest + CMake harness for the pure units
.github/workflows/      CI: compile, lint, unit tests, clang-tidy, release
```

Arduino concatenates the `.ino` files into one translation unit, so
cross-module globals declared in `BirdsEye.ino` are visible everywhere.
Each module's `.h` documents its public surface; the `.ino` includes its
own header first so declaration/definition drift is caught at compile
time.

The **pure units** (`haversine`, `gps_time`, `gps_validation`,
`dovex_header`, `filename_validator`, `course_creator`, `track_json`,
`local_time`, …) deliberately avoid Arduino headers.
The *same* `.cpp` is compiled into both the firmware (Arduino picks up
`.cpp` files in the sketch folder) and the host test binary (CMake). There
is no copy-paste — the tests exercise the exact code that ships.

## Main loop

`loop()` runs at roughly 250 Hz and is a flat dispatch with a few
early-return short-circuits:

```
loop()
 ├─ wdtPet()                     feed the 4 s hardware watchdog
 ├─ if BLE active -> BLUETOOTH_LOOP(); minimal UI; return
 ├─ GPS_LOOP()                   drain buffer, fire PVT callback, feed timer, log
 ├─ TACH_LOOP()                  drain pulse ring buffer, Kalman-filter RPM
 ├─ ACCEL_LOOP()                 read g-force (rate-limited to 50 Hz)
 ├─ BLUETOOTH_LOOP()             service deferred BLE work
 ├─ SENSOREGG_LOOP()             drain SensorEgg scan buffer, parse payload
 ├─ trackDetectionLoop()         haversine match -> create CourseManager
 ├─ checkForNewLapData()         append completed laps to history
 ├─ checkAutoIdle()              60 s < 2 mph -> end session
 ├─ autoRaceModeCheck()          RPM/speed on menu -> enter race
 ├─ CAMERA_LOOP()                step the Insta360 auto-record FSM
 ├─ NEOPIXEL_LOOP()              LED strip frame (30 Hz, self-throttled)
 ├─ button hold combos           shutdown / reboot; menu idle -> shutdown
 ├─ readButtons() / gpsStatusPageLoop() / displayLoop() / resetButtons()
```

On the beta channel each of those calls is bracketed by the loop
profiler (see *Subsystems* below); off beta the brackets are macros that
expand to the bare call, so the dispatch above is literally unchanged.

Each subsystem exposes `*_SETUP()` (called once from `setup()`) and
`*_LOOP()` (called each iteration). ISRs stay trivially short and hand off
to the matching `*_LOOP()`.

## Subsystems

- **GPS** (`gps_functions`) — SparkFun u-blox GNSS v3, UBX-PVT binary at
  25 Hz. A registered callback fills a cached `gpsData` struct. Validated
  rows stream to the DOVEX log.
- **Tachometer** (`tachometer`) — falling-edge ISR timestamps pulses into a
  ring buffer; the loop computes mean inter-pulse period and runs it
  through a 1-D Kalman filter (`tach_filter`). The filter sees one number
  per pulse, so its defining feature is an **outlier gate**: a single
  ignition ring or missed spark is a several-thousand-RPM measurement and
  must be coasted past, not averaged in. Three consecutive rejections
  mean the estimate is the wrong one and the measurement is adopted. Both
  noise models scale with engine speed, because RPM = K/period makes a
  fixed timing error worth quadratically more RPM the faster the engine
  turns. The `tach_filter` setting switches between this, the pre-0009
  filter, and no filter at all, so the pickup can be characterised at the
  track (plan 0009).
- **Accelerometer** (`accelerometer`) — onboard LSM6DS3, ±16 g, raw
  g-force. Degrades gracefully if absent (non-Sense board).
- **SD + tracks** (`sd_functions`) — SdFat (FAT16/32), track JSON parsing
  (two formats, auto-detected), and an in-RAM track manifest for proximity
  detection. Built for a soldered-in module: a missing `/TRACKS` folder is
  created automatically, and a card that responds without a mountable FAT
  volume boots into a hold-to-confirm on-device format page
  (`sd_format_page` pure unit) rather than a dead-end fault screen.
- **Display/UI** (`display_ui`, `display_pages`) — OLED driver abstraction,
  multi-sample debounced buttons, page routing.
- **Bluetooth** (`bluetooth` + the `ble_stream` pure unit) — BLE service for
  file transfer, settings, and track sync, plus buttonless Secure DFU
  (`BLEDfu`) for OTA firmware updates and a Device Information Service
  (`BLEDis`) that reports `FIRMWARE_VERSION` for the update check.
  Download throughput is treated as something to *verify*, not request:
  the connect callback asks for MTU 247, 2M PHY and Data Length Extension,
  and `bleTuneLink()` then reads back what actually negotiated and corrects
  it — re-asking for DLE if the request was lost to a busy link-layer, and
  making a second Apple-compliant connection-interval request only when the
  link is slower than 15 ms. Chunks stream from a compacting 4 KB read-ahead
  so an SD read never sits in the radio's critical path. Plan 0008 has the
  reasoning; the transfer page reports live KB/s so the next regression is
  visible on the device.
- **Camera** (`camera_ble` + the `camera_fsm` / `insta360_protocol` pure
  units) — hands-free Insta360 X4 auto-record: the device emulates the
  Insta360 GPS Remote as a pure BLE peripheral, wakes the paired camera on
  engine start, and starts/stops/powers it off automatically via ce82
  remote-button notifications.
- **SensorEgg** (`sensoregg` + the `sensoregg_protocol` pure unit) —
  wireless EGT proof of concept: a passive BLE observer receives the
  DovesSensorEgg pod's `PW-ADV` advertising broadcasts, v1 (14-byte:
  EGT + cold junction as int16 deci-degC, fault flags, sequence counter)
  and v2 (16-byte: + aux intake-air thermistor, real battery percent),
  and feeds the `Temp1`/`Junction1`/`Temp2` DOVEX columns and the
  Temp1/Temp2 race pages. Observer + peripheral coexist natively on
  S140; passive scanning never transmits, so the camera link is
  untouched. Readings older than 1 s go NaN — never held across a
  dropout. Gated on the `BIRDSEYE_ENABLE_SENSOREGG` build flag: on in
  the beta channel, off in master/release, where the scanner and temp
  pages are compiled out, BLE returns to lazy init, and the DOVEX
  `Temp1`/`Junction1`/`Temp2` columns are written as `nan` so the log
  format stays identical across channels.
- **NeoPixel strip** (`neopixel` + the `led_frame` / `led_modes` /
  `led_status` / `led_animations` / `sector_purple` pure units) — 11
  WS2812 pixels on the NFC pads (converted to GPIO by a one-time,
  one-way UICR write on first flag-on boot): two status LEDs flanking a
  9-px strip. The strip shows a scale until pace is meaningful and then
  a pace pip (slower = left of center in red, faster = right in green);
  the scale is RPM on a session with a tachometer and target *speed* on
  one without, because an RPM bar on a tach-less car is nine dark
  pixels until the first lap lands. The two status LEDs are **assigned
  by the user** from the companion app — target RPM, target speed, GPS
  lock, camera sync, last lap, last sector, EGT, or off — with the GPS
  and camera modes staying lit on the main menu, since "am I ready to
  drive" is a paddock question. The lap and sector indicators compare
  against the *previous* lap or sector rather than the session best; a
  best-based one only ever answers purple or red. There is also a boot
  animation, and a two-stage purple celebration for a session-best
  sector or lap (both detected race-free against the lap timer's
  lap-line best-update by snapshotting bests at sector and lap open).
  One rule everything obeys: a
  global brightness cap applied at a single choke point — no LED channel
  ever exceeds it. Which cap is in force is a local-time decision:
  `led_brightness` by day, `led_brightness_night` after dark (see
  *Local time* below). The strip's 5 V boost
  converter has its EN pin driven low in sleep, so System OFF really
  powers the LEDs down. `BIRDSEYE_ENABLE_NEOPIXEL` is on in **every**
  channel as of 4.1.0, which is what makes the strip a core feature — at
  the price of a one-way, fleet-wide UICR NFC→GPIO conversion on the
  first boot after updating.
- **Course creator** (`course_creator` + `track_json` pure units, glued
  into the menu/pages/SD modules) — authors a track course on the device
  by walking to each cone and holding for a 3 s GPS average. Autocross
  venues re-lay their course every event, so the alternative was a laptop
  in a paddock. No text is ever entered on-device: names come from the GPS
  clock and are renamed later in the web app. This is also the firmware's
  only track-JSON *writer* — everywhere else the format is read-only.
- **Local time** (`local_time` pure unit) — UTC plus a fixed signed
  minute offset (`utc_offset_min`), giving the device a local wall clock.
  Its only consumer is the LED day/night brightness swap, which needs
  "7am" to mean the driver's 7am. No DST, and **nothing logged goes
  through it** — see *Local time is presentation-only* below.
- **Loop profiling** (`profiling` + the `loop_profile` pure unit,
  beta channel only) — times every subsystem call in `loop()`, rolls the
  result up once a second onto a LOOP PROFILE race page, and drives
  pin 30 as a scope-readable profiling output. Built to answer two board
  questions with measurement instead of argument: nRF52840 or nRF5340,
  and is the Arduino core costing enough to be worth leaving. It takes
  pin 30 from the NeoPixel boost EN line to do it — see *Profiling costs
  the 5 V rail* below.
- **Replay** (`replay`) — instant DOVEX header replay.
- **Settings** (`settings`) — JSON key/value store on the SD card.
- **CourseManager** (external library) — owns course detection, sector
  timing, and the Lap Anything fallback once a track is matched.

## Design decisions worth knowing

These are the parts that look over-engineered until you've watched them
fail the simple way.

### GPS serial ring buffer (TIMER3 ISR) — two buffers, two failure modes
At 25 Hz PVT the GPS emits ~2.5 KB/s. An SD-card garbage-collection pause
can block the main loop for 100 ms – 2 s — long enough to overflow the
UART buffering and lose fixes. A TIMER3 ISR drains Serial1 into a 4 KB
RAM ring buffer every 5 ms, independent of the main loop, and the GPS
library reads from that buffer. This is why **TIMER3 is reserved**
project-wide.

That ring only covers *downstream* stalls. Upstream of it sits the
core's Serial1 RX ring, and the TIMER3 handler runs at NVIC priority 3 —
below the SoftDevice's radio interrupts (priority 0–2, unmaskable by the
app). Radio airtime (the SensorEgg scan window, camera connection
events) defers the drain, and only the core ring absorbs bytes in the
meantime; its stock 64 bytes gave ~1 ms of slack at 57600 baud, which is
exactly where a ~0.9% 25 Hz PVT drop rate came from once BLE was always
on. The core ring is therefore grown to 256 bytes via a required
`-DSERIAL_BUFFER_SIZE=256` build flag (asserted in `project.h`), and the
pipeline carries permanent counters — dropped PVT frames, worst TIMER3
deferral (hardware timer capture), drain-burst high-water, and overflow
events for both rings — surfaced on the GPS debug page so radio-induced
loss, SD-stall loss, and checksum corruption can be told apart on
hardware. The window math lives in the host-tested `gps_stats` unit.

### SD access arbitration
The BLE callbacks run in a **separate FreeRTOS task** from `loop()`, and
SdFat is not thread-safe. Every SD user (logging, replay, BLE transfer,
track parsing) must take a single mutex via `acquireSDAccess(mode)` /
`releaseSDAccess(mode)`. Two layers make this sound:

1. **Atomic transitions.** `acquireSDAccess()` evaluates the grant rules
   and commits the new owner inside a FreeRTOS critical section
   (`taskENTER_CRITICAL`, BASEPRI-masked so the SoftDevice's radio
   interrupts are untouched) — a plain check-then-set on the shared flag
   would be a TOCTOU between the two tasks. The grant/deny decision table
   itself (same-mode re-acquire is idempotent; the brief `TRACK_PARSE`
   mode is preemptible as leak recovery) is the host-tested
   `sd_access_policy` pure unit.
2. **Single-task SdFat.** *Every* BLE command that touches the card —
   `LIST`/`GET`/`DELETE`, `TLIST`/`TGET`/`TPUT`/`TDEL`, settings, firmware
   OTA — is parsed in the callback (filenames validated there, RAM only)
   and executed by `BLUETOOTH_LOOP()` on the main loop. Nothing calls
   SdFat from the Bluefruit callback task, so the filesystem only ever
   has one task in it; directory listings hold the lock for the whole
   walk, and `DELETE` refuses while a transfer is streaming.

### DOVEX crash safety
A `.dovex` file reserves the first 1 KB for session metadata (driver,
course, lap times) but the device **writes that header last**, when the
session ends cleanly. On creation the region is pre-filled with newline
padding and the GPS rows stream in after byte 1024. If the device loses
power mid-session the header is blank but every logged GPS row is still
intact and recoverable. Header layout/parsing lives in the tested
`dovex_header` unit.

### EMI hardening
The device lives next to an ignition system. Defenses: multi-sample
button reads with a refire lockout, a Kalman-filtered tach that absorbs
ISR jitter, a reduced 2 MHz SD SPI clock, an I2C bus-recovery routine that
bit-bangs the display bus free if it hangs, and a 4 s hardware watchdog as
the last resort.

### Shutdown is System OFF, wake is a reboot
There is no power switch (deliberately — the next hardware revision drops
it), so "off" is nRF52 **System OFF** at ~µA with GPIO SENSE armed on the
tach pin and the three buttons, plus VBUS. The tach's SENSE polarity is
not hardcoded: the pickup circuit's output stage idles high or low
depending on the build, so shutdown samples the parked line and arms
SENSE for the opposite level (majority vote in the host-tested
`wake_cause` unit) — arming toward the idle level satisfied DETECT
immediately and battery sleep reboot-looped. Waking is a full chip reset:
`setup()` runs fresh, and the very first thing it does is read (then
clear) the sticky `RESETREAS` + GPIO `LATCH` registers to decode *why* it
booted (the host-tested `wake_cause` unit). An engine-start (tach) wake
routes the GPS status page's exit straight into race mode with logging —
the old software sleep loop's RPM wake, rebuilt on hardware. GPREGRET is
never touched; register 0 belongs to the OTA/bootloader handoff. The one
soft exception is VBUS: while a cable is present the device parks in a
live charging loop instead of System OFF, wakes fully on any button, and
powers off when unplugged. Two reasons — the fast-charge (HICHG) pin is
software-held when onboard charging is compiled in, and, regardless of
that, VBUS is an always-armed System OFF wake source, so powering down
with the cable in risks an immediate wake-reset loop.

Onboard charging itself is a build flag,
`BIRDSEYE_ENABLE_ONBOARD_CHARGING`, **off in every shipped build** since
3.0.1: the hardware now carries an external charging circuit (the XIAO's
BQ25100 tops out around 100 mA even with HICHG held). With the flag off
the firmware never drives HICHG, and USB is treated as a host connection
rather than a charge session — a VBUS wake boots normally instead of
shortcutting to the charge screen, and the main menu is no longer pulled
down after `USB_MENU_CHARGE_IDLE_MS` just because a cable is plugged in.
Setting the flag to 1 restores the pre-3.0.1 behavior wholesale.

### GPS boot recovery
The SAM-M10Q keeps its config in volatile RAM (backed by V_BCKP), and
with shutdown being a real power-down the module can be in **any** state
at boot: software backup mode holding a 57600 config (the normal wake),
already configured and running (an MCU-only reset), or factory 9600 NMEA
(true cold power / brownout). Boot therefore sends the u-blox backup-wake
byte first (harmless if awake), probes 57600 before 9600 so warm boots
connect near-instantly, and pays a cold-boot delay only when nothing
answers. A `begin()` ping proves the module answers — not that data
flows — so boot also arms a 5 s PVT-arrival watchdog; if no fix data
arrives, `GPS_BAUD_RECOVERY()` renegotiates the baud rate and
reconfigures. A GPS that never appears is re-probed a bounded number of
times from the status page and surfaced as "CHECK WIRING".

### GPS status boot page
Every boot lands on a MyChron-style satellite status page: sat counts,
HDOP, lock state, and per-satellite CNO signal bars (UBX-NAV-SAT). The
GPS runs a 5 Hz status config while the page is up and switches to the
25 Hz PVT-only race config on exit. The page holds until a stable lock
(fix + fully-resolved time held 3 s) then auto-advances; any button skips
it immediately; a tach-wake boot or a running engine turns the exit into
race-mode entry. Its hold/auto-close/destination logic is the host-tested
`gps_status_page` unit, and the bar selection/geometry is `sat_bars`.

### OTA firmware updates
The board has no internet radio — only BLE — so it cannot pull a release
itself. OTA is a two-hop flow: the companion (DovesDataViewer, over Web
Bluetooth) downloads the firmware `.zip` from a GitHub release, writes the
buttonless-DFU command to reboot the board into the Adafruit/Nordic Secure
DFU bootloader, then force-feeds the image over GATT. The bootloader is a
passive receiver: it validates the package's signed init packet (device
type, SoftDevice requirement, CRC) before writing, so a corrupt or wrong
image is rejected rather than bricking the board. The companion picks
*which* image (version, Sense vs non-Sense) by reading the installed
`FIRMWARE_VERSION` and DIS model (`BirdsEye-sense` / `BirdsEye-nonsense`)
over the Device Information Service and comparing against a `manifest.json`
the release workflow publishes to the `gh-pages` branch (GitHub Pages
serves it with permissive CORS, so the browser can fetch both the manifest
and the `.zip` — raw release-asset URLs can't be relied on for that). Sense
and non-Sense are the same MCU + SoftDevice, so a mismatched image still
boots — it just skips IMU init.

### Insta360 camera auto-record
An Insta360 X4 has no wired trigger, but it *does* trust its own BLE
accessory: the "GPS Remote". So the device **is** the remote — a pure BLE
**peripheral**. It hosts the remote's GATT (service `0xCE80`: `ce81`
write camera→us, `ce82` notify us→camera, `ce83` read), advertises the
remote's manufacturer-data payload (carrying the camera's serial) to wake
a powered-off camera, and the camera connects back to *us* as central and
subscribes to `ce82`. **All** control is a `ce82` button notification,
byte-for-byte the physical remote's frames: recording toggles with the
shutter button, and power-off streams the remote's 3-second power-hold.
We never act as central — no scanning, no connecting to the camera's own
`0xBE80` service. (That central path was an earlier design; it let us
send explicit start/stop-video and a 1 Hz GPS-overlay frame, but power-off
only exists as a remote `ce82` hold, and one BLE link can hold only one
role — you cannot be central to the camera and have the camera be central
to you at once. The role conflict is what made power-off impossible, so
the device commits fully to the remote role. The in-camera GPS overlay
rides that same remote channel: a capture of the genuine link showed the
remote streams GPS on `ce82` at 10 Hz as a non-standard NMEA-RMC frame,
which the firmware now emits continuously while connected — doubling as
the remote's liveness heartbeat. GPS still logs to SD independently.)

The single peripheral slot is shared with the file-transfer service via
an explicit `bleOwner` (NONE/TRANSFER/CAMERA); the owner model keeps a
camera link from ever triggering the transfer path's
auto-reboot-on-disconnect, and opening the transfer page force-releases
the camera first. The link is Just-Works bonded (the genuine remote link
is encrypted), and BLE comes up lazily on the first camera action, so an
unpaired device pays nothing.

The lifecycle is a **pure FSM** (`camera_fsm`), deliberately RPM-driven and
simple: wake on engine start, connect+subscribe, record once RPM has held a
few seconds, stop after the engine has been off a while, then WATCH. It
consumes a telemetry snapshot each loop tick and returns at most one action
for the glue to execute. **Recording starts** from the WATCHING hub once RPM
has held above the ON threshold for ~5 s — there is **no GPS-lock gate**
(GPS still streams to the camera continuously). Because the shutter is a
*toggle*, a wrong record belief flips the camera the wrong way — so the FSM
does not merely believe: it **confirms** record state from the camera's own
`0x10` status frame (a live `.HH:MM:SS` timer while recording; the `0x02`
word is unreliable) and reconciles `recordingActive` against it. On a
mid-session BLE drop it preserves the belief and on reconnect adopts the
camera's real state instead of blind-toggling; if the camera reports idle
while we think we're recording, it re-asserts the shutter once. **Recording
stops** after ~30 s of engine-off (RPM only — a stationary but running grid
idle keeps recording), returning to WATCHING. WATCHING keeps the camera on
and connected so a brief on-track stall recovers straight back into
recording when RPM returns; the camera powers off **only** when the device
shuts down (there is no post-record cooldown/power-off timeout). All temporal
behavior lives inside the FSM, host-tested with a fake clock, and it is the
board-portable core intended to move unchanged to the nRF54 ("Falcon")
target.

One deliberate coupling bounds the feature: the camera's 30 s-engine-off
auto-stop also **ends the race log session** (the glue latches it and the
main sketch calls `endRaceSession()` + returns to the menu), and while the
camera is recording `checkAutoIdle()` yields so the speed-based log idle
can't cut the log out from under it. So with a camera paired+recording the
log ends on engine-off, not on 60 s-stationary; without a camera, logging is
unchanged (a tach-less setup reads RPM≈0, which is why the RPM-idle can't be
made universal). The protocol bytes live in the host-tested
`insta360_protocol` unit with golden-byte tests: the wake advert + scan
response, the ce82 button frames, the ce82 GPS/RMC frame, and the `0x10`
record-timer parse are all captured from a genuine remote (the wake advert
was even replayed to wake a sleeping X4).

### Local time is presentation-only

The GPS delivers UTC and that is what the device *logs*. DOVEX row
timestamps are Unix epoch milliseconds, and the header `datetime`, the log
filenames and the generated course names are all UTC too. The
`utc_offset_min` setting (a fixed signed minute offset — `local_time`) buys
the device a local wall clock for exactly one purpose: deciding when to
swap the LED strip to its night brightness, where "7am" has to mean the
driver's 7am. A US Central driver at 07:30 local is at 12:30 UTC, which a
naive UTC gate calls the middle of the night.

Nothing in the logging pipeline may call into `local_time`. A log is
routinely *viewed* somewhere other than where it was recorded, so timezone
presentation belongs to the app doing the viewing, which knows the reader's
preference; baking a recording-side offset into the data would just move
the guess earlier and make it unrecoverable.

There is deliberately **no DST**. A fixed offset walks the boundary an hour
twice a year, which is beneath the resolution of a dim-after-dark gate,
whereas rule tables are a standing correctness liability (legislatures keep
moving the dates) and tzdata is ~100 KB shipped to a sealed device.
`local_time` is where rules would go if that ever changes — which is why its
`DateTime` carries a 4-digit year even though the sketch's `gpsData.year`
is 2-digit.

### The settings file has a hard size ceiling

Every settings read path caps at `sizeof(settingsFileBuffer) - 1`. A file
larger than that parses as `IncompleteInput`, so *every* key read fails —
which `SETTINGS_SETUP()` correctly interprets as corruption, quarantines to
`SETTINGS.json.bad`, and regenerates (losing the BLE name, PIN and
pairing), whereupon `ensureDefaultSettings()` grows the file back over the
cap and it happens again on the next boot. A settings key is therefore not
free: an innocuous four-key addition in plan 0010 took an 18-key, 436-byte
file to 543 bytes and would have shipped that loop.

Both the file buffer and the `StaticJsonDocument` are 1024 bytes (raised
from 512) and **must stay equal** — the invariant is that the buffer can
always hold what the document serializes. `setSettingInner()` also refuses
any write whose document `overflowed()` or whose `measureJson()` exceeds
the buffer, so the failure mode is one loudly refused write with the
previous file intact, rather than a silent unreadable one.

### Profiling costs the 5 V rail

A profiling build (`BIRDSEYE_ENABLE_PROFILING`, beta only) drives pin 30
HIGH for the span being profiled and LOW outside it, so a scope reads the
loop period off the rising edges with no software in the measurement
path. Pin 30 is also the NeoPixel boost converter's EN line, and it
cannot be both.

The profiler takes it. A profiling build therefore never drives EN — not
at setup, not at sleep, not on the charging-loop resume — and the
regulator sits at its hardware default (EN pulled up = rail on). That is
what makes the trade work at all: the rail does not need firmware
control, it needs to be *switchable*, and switching it is a requirement
of **use**, not of **testing**.

Two consequences, both deliberate:

- The rail stays up through System OFF. GPIO levels are retained there
  and the driven LOW was the only thing holding it down (same retention
  as the "blue conn LED stays on after sleep" report above). A profiling
  unit left asleep on a battery with a strip wired to it goes flat.
- If the EN jumper is still physically connected on the rig, the
  toggling chops the rail at loop rate. Pull it or tie EN high before
  profiling.

Master and release are untouched: the flag defaults to 0, the section
brackets are macros that expand to the bare call, and pin 30 goes on
being EN.

### The profiler reports the shape of an iteration — and measures idle rather than assuming it

`loop()` runs back to back with nothing rate-limiting it, so the first
version of this subsystem asserted there was no idle time and that a
duty cycle would be meaningless. That was an assumption, it was baked
into the measurement, and it produced a wrong first reading — see *Two
clocks* below. The profiler now **measures** how much wall time the CPU
spends executing `loop()` and reports the balance as `SLP` (scheduler
dispatch, other FreeRTOS tasks, sleep). If that number is large, the
loop rate is not what limits this firmware.

Alongside it, the **shape of an iteration**: how long one takes (mean
*and* worst case — an SD garbage-collection stall of 100 ms–2 s is
invisible in a mean), how that time divides between subsystems, and how
much of it no subsystem accounts for. `OTH` — loop time no section
bracketed — is reported rather than hidden, because it is the honesty
check on the instrumentation. Every slot is a share of the same
wall-clock second, so all fourteen sum to ~100%.

### Two clocks, and why mixing them was a real bug

Durations are measured with the Cortex-M4 DWT cycle counter (64 ticks/µs):
most sections are well under a microsecond and `micros()` would quantise
half of them to zero. DWT is *verified* to be counting at setup rather
than assumed — a debug probe can hold TRCENA off — and the page marks
the `micros()` fallback with a leading `*`.

But DWT counts **cycles, not time**. It stops whenever the core halts.
The first implementation also used it to close the one-second rollup
window, which meant the window was one second of *CPU-awake* time: the
loop rate came out multiplied by the sleep factor, and every share was a
fraction of awake time wearing a wall-time label. The window is now
closed on `millis()` and all shares are computed against wall time. The
pure unit still accumulates ticks and is handed `ticksPerUs` at rollup,
so per-call resolution is preserved; its accumulators saturate rather
than wrap, since a uint32 of DWT ticks is only ~67 s and a pegged window
reads as pegged where a wrapped one would read as near-idle.

## Data formats

- **`.dovex`** — 1 KB reserved header (metadata + lap times) then streaming
  CSV GPS rows after byte 1024. Default and only logging format. Every
  timestamp in it is UTC and stays that way (see *Local time* above).
- **Track JSON** (`/TRACKS/*.json`) — new object format with `courses[]`
  and `lengthFt`, or an older bare-array format (parsed, but falls back to
  Lap Anything since it has no length to rank courses by).
- **Settings JSON** (`/SETTINGS.json`) — string key/value store.

See [`CLAUDE.md`](CLAUDE.md) and the README for field-level detail.

## Simulator (`BirdsEye/sim/`)

A demo tool, not an emulator: the REAL firmware sources — the same
unmodified `.ino` files that ship — compiled for a desktop (and, later,
WASM/browser) target under the `SIM` flag. `sim_main.cpp` replicates
Arduino's concatenation into one translation unit (`sim_prototypes.h`
stands in for the IDE's auto-generated prototypes), against:

- `arduino_shim/` — Arduino core + nRF52 register surface. Time is a
  **virtual clock** the host advances (`delay()` consumes virtual time;
  no wall clock anywhere, which is what makes runs deterministic).
- `sdfat_shim/` — an in-memory VFS preloaded with fixed
  `assets/SETTINGS.json` (deterministic boot) and an example track.
  Logs written during a run evaporate with it; persistence is out of
  scope.
- `stubs/` — no-op implementations of the deliberately-excluded modules
  (`bluetooth`, `camera_ble`, `usb_msc`, `firmware_ota`) and of the
  SparkFun GNSS driver (real header for the UBX types; PVT is injected
  by the host straight into `onPVTReceived()`, never parsed from bytes).
- Real **DovesLapTimer/CourseManager** sources — lap timing fidelity is
  the point.
- The REAL **Adafruit display stack** (GFX → GrayOLED → SH1106G, pinned
  versions): the hardware boundary is two BusIO device pointers, shimmed
  in `busio_shim/` to succeed-and-discard, so every framebuffer pixel
  comes from the real `drawPixel()` — pixel-perfect by construction. The
  1024-byte buffer is exposed zero-copy plus an FNV-1a frame hash.

Inputs are injected at the same boundaries the hardware uses: GPS as a
real `UBX_NAV_PVT_data_t` handed straight to `onPVTReceived()` (the
SparkFun parser is never involved), the tach as synthesized pulses
through the real falling-edge ISR at exact virtual microseconds (the
debounce/ring-buffer/Kalman path is all real firmware), buttons as pin
levels through the real multi-sample debounce, and accel via the IMU
shim. A **lap-timing oracle** test drives a synthetic constant-speed
lap trace around the OKC start line — whose lap period is exact by
construction — through the whole pipeline (boot page → auto race entry
→ haversine track detection → CourseDetector → DovesLapTimer) and
requires every recorded lap to match within one GPS frame (40 ms); the
same driver's `--dovex` mode replays a hardware-recorded log against
the lap list in its own header.

The `sim-build` workflow builds it and runs a 60 s boot soak, a
two-runs-byte-identical determinism check, **golden display
fixtures** — a scripted walk of the real menus capturing the frame hash
(and expected page id) at fixed virtual times for 8 pages, committed in
`sim/golden/` — and the lap oracles, on every PR. The sim compiling is
itself a CI gate, which is what keeps `SIM` from rotting the way the
old `WOKWI` flag did.

The same sources also build to a **browser module** (Emscripten;
`sim/wasm/`): `birdseye-sim.mjs` wraps the emitted core and exposes the
contract in `sim/API.md` (framebuffer + frame hash, JSON PVT injection,
RPM, state/version JSON, VFS reads; `reset()` re-instantiates the
module for a true fresh boot). CI builds it, smoke-tests it under node
(including cross-instance determinism), and uploads the dist folder;
the artifacts are vendored into `DovesDataViewer/public/sim/` so the
viewer only ever runs a deliberately-committed build. The wasm module
renders byte-identically to the native golden fixtures.

## Testing & CI

The pure units are unit-tested with doctest on a host toolchain; the
firmware itself is compile-checked for the XIAO in CI, linted with
arduino-lint, statically analyzed with clang-tidy, and gated on flash
size. The `sim-build` workflow additionally compiles the whole firmware
TU natively under `SIM` and boots it (see *Simulator* above). Releases
are built and published (`.hex` + `.uf2`) by the `release` workflow on a
version tag. Hardware behavior still needs manual verification on a real
device — CI proves it builds and that the logic units are correct, not
that a lap was timed right on track.

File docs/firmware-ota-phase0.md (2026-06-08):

# Firmware SD-staged OTA — Phase 0 findings & apply-strategy decision

This document records the Phase 0 investigation that gates the self-flash
("apply") mechanism for the SD-staged firmware OTA feature, and the design
decisions that flow from it. The protocol, SD staging, and CRC verification
are implemented and host-tested independently of these findings (see
`BirdsEye/firmware_ota.{h,ino}`, `BirdsEye/crc32.{h,cpp}`, and
`tests/crc32_test.cpp`).

> **Status of these findings.** The spikes below require the physical sealed
> hardware (XIAO nRF52840, Adafruit bootloader, S140 7.3.0) and a BLE host.
> They could not be run in the CI/build environment. Each item states the
> best-evidence answer from the platform documentation and core source, and
> exactly what must be confirmed on a bench unit before the **apply** path is
> enabled in a field release. The receive/verify pipeline (everything up to,
> but not including, the destructive app-region swap) is safe to ship and
> exercise on its own — nothing it does can brick a unit.

## Why we self-flash at all (settled, do not re-litigate)

- Chrome's Web Bluetooth blocklist bans the Nordic **legacy** DFU service
  (`00001530-…-785feabcd123`) that Adafruit `BLEDfu` exposes, so the
  buttonless BLE-DFU path is unreachable from a browser.
- A web-allowed Secure-DFU bootloader needs SWD pins to install; our units
  are sealed (no button, no pins). We therefore do **not** change the
  bootloader for the field flow.
- Instead the app streams the image to SD over the existing custom `0x1820`
  service (not blocklisted), CRC-verifies it, and installs it itself.

## Memory map assumed by the implementation

| Region | Address | Notes |
|---|---|---|
| MBR + SoftDevice S140 7.3.0 | `0x00000000`–`0x00026FFF` | |
| **Application** (`FW_APP_BASE`) | `0x00027000` | `CODE_REGION_1_START` |
| … running app … | | current image ≪ 512 KB |
| **Staging region** (`FW_STAGE_BASE`) | `0x000A4000` | 320 KB, `= 0xF4000 − 320 KB` |
| **Bootloader** (`FW_BOOTLOADER_ADDR`) | `0x000F4000` | Adafruit nRF52840 |
| MBR param page | `0x000FE000` | |
| Bootloader settings | `0x000FF000` | |

The split leaves `[0x27000, 0xA4000)` = **512 KB** for the running app and
`[0xA4000, 0xF4000)` = **320 KB** for the staged image. `FWBEGIN`/`FWPUT`
reject any image larger than `FW_MAX_IMAGE_SIZE` (320 KB) with `FWERR:SIZE`.

## Phase 0 spikes

### 1. Recovery net — invalid app ⇒ re-flashable over BLE with no pins
**Why it matters:** this is what makes self-flashing acceptable on sealed
units. If the swap is interrupted, the unit must still be recoverable.

**Best-evidence answer:** the Adafruit nRF52 bootloader enters DFU mode when
the application is invalid (bad/missing vector table at `FW_APP_BASE`), and it
advertises BLE DFU in that state. nRF Connect (a *native* app, not subject to
the web blocklist) can then push a fresh image. The implementation also writes
`GPREGRET = DFU_MAGIC_OTA_RESET (0xA8)` *before* the destructive swap so DFU is
forced even if a half-written vector table looks plausibly valid.

**Confirm on hardware:** corrupt the app's first page on a bench unit (e.g.
erase one page at `0x27000`), power-cycle, and verify the bootloader
advertises and is re-flashable over BLE via nRF Connect with **no** button /
USB / SWD interaction. This is the make-or-break safety gate.

### 2. App can erase+write the upper free-flash region (SoftDevice flash API)
**Best-evidence answer:** with the SoftDevice enabled, page erase / word write
go through `sd_flash_page_erase` / `sd_flash_write`, which complete
asynchronously via a SoftDevice flash event. The implementation uses the
Adafruit core's `flash_nrf5x_{erase,write,flush}` HAL (the same one
`InternalFileSystem` uses), which wraps that handshake — so we don't hand-roll
event handling. Page size is 4096 B; writes must be word-aligned (the staging
copy pads the final block to a word with `0xFF`).

**Confirm on hardware:** erase + write a known pattern across
`[0xA4000, 0xF4000)` while BLE is connected, read it back, and confirm timing
(≈85 ms/page erase) doesn't starve the BLE connection. Confirm the
`flash/flash_nrf5x.h` include path resolves for a sketch build on the pinned
core version.

### 3. RAM flasher — erase app region + copy staged image, then boot it
**Best-evidence answer:** the app-region swap erases the very flash the app
runs from, so it must execute from RAM with the SoftDevice disabled and IRQs
off, touching only the raw NVMC. `fwRamFlasher()` is marked
`__attribute__((section(".data")))` (startup copies `.data` to RAM, and RAM is
executable on Cortex-M with no MPU configured) and is fully self-contained
(`NVIC_SystemReset` is an inlined CMSIS intrinsic; no libc/SoftDevice calls).

**Confirm on hardware (highest risk):** inspect the `.map` to confirm
`fwRamFlasher` is linked into RAM (`0x20000000…`); single-step or scope the
NVMC `READY` waits; verify a full erase+copy+reset cycle boots the new image.
This is the spike that decides whether to ship the RAM flasher or fall back to
the dual-bank alternative (#4).

### 4. Fallback — dual-bank Adafruit bootloader via nRF Connect (no pins)
**If the RAM flasher proves shaky:** a one-time, over-the-air move to a
dual-bank Adafruit bootloader makes the swap bootloader-managed. The
bootloader update itself is pushed via nRF Connect (native app → buttonless
trigger works) with no pins. Evaluate only if #3 fails validation.

### 5. GPREGRET behavior across soft-reset vs power-loss
**Best-evidence answer:** `GPREGRET` is a RETAINED register in the always-on
power domain; it survives a soft reset (`NVIC_SystemReset`) but **not** a full
power loss / brownout. So GPREGRET is the recovery path for the *soft-reset*
case (our normal flow), while the *power-loss* case relies on spike #1
(invalid-app ⇒ DFU). Both paths must hold for the net to be complete.

**Confirm on hardware:** set GPREGRET, soft-reset, confirm the bootloader sees
it; then repeat with a power-cycle and confirm it's cleared (forcing reliance
on the invalid-app fallback).

## Decision

**Leading plan adopted:** SD → upper-flash staging via `flash_nrf5x`, in-flash
CRC re-verify, GPREGRET recovery flag, then a RAM-resident flasher for the
app-region swap (spikes #1–#3, #5). The dual-bank migration (#4) is the
documented fallback if spike #3 fails on hardware.

**Safety invariants enforced in code:**
- The app region is **never** erased until the staged copy is CRC-verified
  *in flash* (`fwStageToFlash()` returns false on mismatch → `FWERR:FLASH`,
  app untouched).
- `FWAPPLY` is refused below `FW_MIN_APPLY_VOLTAGE` (3.6 V) → `FWERR:BATTERY`.
- A variant mismatch is refused at the `FWBEGIN` handshake, before any upload
  → `FWERR:VARIANT` (the web app declares the target variant, derived from the
  device's DIS Model Number, and the firmware compares it to its compile-time
  `FIRMWARE_VARIANT`). Every image still embeds `kFwImageDescriptor` for
  forensics.
- The GPREGRET recovery flag is armed *before* the destructive swap.
- Every step before the RAM flasher is abortable; the running firmware stays
  intact until the flasher actually runs.

## Fleet migration

The first firmware carrying this `FW*` protocol is pushed to already-sealed
units **once** via nRF Connect (native app, buttonless trigger works on the
existing single-bank bootloader — no bootloader swap). After that single push,
all future updates go through the web app. New production ships this firmware
from the factory.

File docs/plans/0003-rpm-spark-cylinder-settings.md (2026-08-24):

# RPM Accuracy — Spark Type & Cylinder Count Settings

> **SUPERSEDED IN PART by [0014](0014-tach-rpm-single-pickup.md).**
> The `pulses_per_rev = cylinder_count × sparkFactor` geometry below is
> WRONG for this hardware: there is one sense wire and one clamp, on one
> plug wire, so the pickup never sees more than one cylinder and the
> cylinder term divided RPM (a V8 read an eighth of its crank speed).
> `spark_mode` and everything else here still stand; `cylinder_count`
> remains a setting but no longer reaches the math.

> Status: **SHIPPED.** Split out of plan 0002 (sprint mode); independent of
> it. Prompted by the same autocross-kart user group: unknown engine, "kart
> kart or some wacky 2cyl monster", so the logger can no longer assume one
> ignition pulse per revolution.
>
> Settings key is **`cylinder_count`** as drafted. The webapp's `enum` control
> landed alongside it (DovesDataViewer), so `spark_mode` is a real dropdown
> rather than the free-text stopgap this plan allowed for.

## Goal / problem

The tachometer counts **ignition pulses** from the inductive pickup and
currently treats one pulse as one revolution. That's only true for a 1-cyl
2-stroke or a 1-cyl wasted-spark 4-stroke — the common kart cases, which is
why it's been fine so far. Other engines skew RPM by a fixed factor:

| Engine | Pulses per revolution |
|---|---|
| 2-stroke, per cylinder | 1 × cylinders |
| 4-stroke wasted spark, per cylinder | 1 × cylinders |
| 4-stroke single-fire (no wasted spark), per cylinder | 0.5 × cylinders |

The logger should reflect **true RPM** in both the display and the DOVEX
`rpm` column, based on two new device settings.

## New settings (2)

| Key | Default | Meaning |
|---|---|---|
| `spark_mode` | `wasted` | `wasted` = one spark per rev (2T, or 4T wasted spark); `single` = one spark per two revs (4T single-fire) |
| `cylinder_count` | `1` | Cylinders visible to the pickup |

`pulses_per_rev = cylinder_count × (spark_mode == wasted ? 1.0 : 0.5)`
`true RPM = pulse RPM ÷ pulses_per_rev`

**Defaults exactly reproduce today's behavior** (divisor 1.0), so existing
devices are unaffected by `ensureDefaultSettings()` auto-populating the keys.

## Approach

- Settings rows in `ensureDefaultSettings()` (`settings.ino:102-108`),
  loaded into globals in the settings block (`BirdsEye.ino:765-795`),
  applied on boot like every other setting (webapp `SSET` + auto-reboot).
- **Single source of truth (decided)**: true RPM is computed **once** — at
  the period→RPM conversion in `TACH_LOOP()`, *before* the Kalman filter —
  and published as the one canonical value (`tachLastReported`). **No
  consumer ever re-applies or re-derives the correction**: display (3 Hz),
  DOVEX rows (25 Hz), camera FSM inputs, and the auto-race check all read
  the same already-corrected number. Any future consumer must read it too,
  never the raw pulse rate. While implementing, audit that nothing else
  computes RPM from pulse periods independently.
- **Kalman note**: the correction must sit *before* the filter because the
  filter's tuning is in true-RPM units — Q = 800 RPM² models kart engine
  inertia and R_BASE = 2500 RPM² models measurement noise
  (`tach_filter.h`). Feeding pulse-RPM and dividing afterward would make a
  2-cyl engine's process/measurement noise effectively half-scale, i.e.
  differently-filtered behavior per engine type. Correct-then-filter keeps
  one tuning valid for everyone.
- The divisor math itself belongs in the host-tested `tach_filter` pure unit
  (or a tiny sibling) with tests per the repo convention.

## Ripple effects (mostly good)

- **RPM thresholds become engine-independent**: auto-race entry (>500),
  camera wake/record/stop (500 / 1500 / 300) currently assume 1 pulse/rev;
  on a 2-cyl they'd fire at half the true RPM. With correction, thresholds
  mean what they say on every engine.
- **Pulse-rate ceiling** (resolved): the min gap now derives from
  `pulses_per_rev` — 3 ms ÷ ppr — in `tach_filter::minPulseGapUs()`.
  **The floor is 750 µs, not the 1.5 ms sketched here**: 1.5 ms still put a
  3-cylinder at ~13 300 true RPM, below the old ceiling. 750 µs holds the
  full ~20 000 through four cylinders; past that the floor binds (10 000 at
  eight), which is far clear of anything this logger targets.
  ISR headroom was never the constraint — the body is <1 µs, so the floor's
  worst case (~1300 int/s) is negligible. Ringing was, and the margin holds
  from both ends: the tach input is RC-filtered (~100 µs) and the documented
  pickup circuits emit pulses **milliseconds** wide — `TACHOMETER/README.md`
  records circuit 1's 5 ms pulse as itself the ~9800 RPM limit on that
  hardware, i.e. the pulse width, not the debounce, is what binds there.
- **Pickup placement nuance (document for users)**: `cylinder_count` is
  "cylinders the pickup *sees*". A pickup clamped around ONE plug wire of a
  2-cyl sees one cylinder → leave `cylinder_count = 1`. Only a pickup on a
  shared coil/all-cylinder harness sees them all.

## Touch points

`settings.ino` (defaults), `BirdsEye.ino` (globals + load), `tachometer.ino`
+ `tach_filter.{h,cpp}` + `tests/tach_filter_test.cpp` (divisor + tests),
README.md + CLAUDE.md settings tables. Webapp: keys auto-appear via the
generic settings list; a proper `enum` control type in
`deviceSettingsSchema.ts` is wanted for `spark_mode` (shared need with
nothing else right now — plain string works until then).

## Status

**Shipped.** No dependency on plan 0002. Landed before any camera/auto-race
tuning for multi-cylinder engines, as intended — those thresholds now mean
what they say on every engine.

### What actually landed

- `tach_filter::revsPerPulse()` / `minPulseGapUs()` — the geometry, in the
  host-tested pure unit, sharing one private `pulsesPerRev()` so the RPM
  scale and the debounce can never disagree.
- `tachRevsPerPulse` / `tachMinPulseGapUs` became boot-set globals; the
  correction point in `TACH_LOOP()` was already there and already ahead of
  the Kalman filter, so no restructuring was needed.
- Settings default in `ensureDefaultSettings()`; loaded in `setup()`.
  Anything other than an explicit `"single"` degrades to `wasted`, so a
  blank or future value reads as today rather than doubling every RPM.
- The audit the plan asked for came back clean: nothing else derives RPM
  from pulse periods. The only other `60e6` in the tree is the simulator's
  pulse *generator*, which is the inverse and matches the default.

### Verified

Unit tests cover the geometry, the clamps (a corrupt `cylinder_count` can
never divide by zero) and the ceiling property. End-to-end in the simulator:
6000 pulses/min reports 6000 RPM at the defaults and 3000 with
`revsPerPulse` forced to a twin — so the wiring is proven, not just the
math. Golden fixtures and the lap oracle are unchanged, which is the
evidence that existing devices are unaffected.

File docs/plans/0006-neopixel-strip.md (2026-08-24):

# 0006 — NeoPixel strip subsystem (2 status LEDs + 9-px strip)

## The hardware

An 11-pixel WS2812 (NeoPixel) strip was added to the device, powered by an
Adafruit 5 V boost converter with an ENABLE pin. The two nRF52840 NFC pads
are converted to plain GPIO to drive it:

| Pin | P-number | Role |
|---|---|---|
| Arduino 30 (`PIN_NFC1`) | P0.09 | Boost converter EN — HIGH = 5 V rail on, LOW = off |
| Arduino 31 (`PIN_NFC2`) | P0.10 | NeoPixel data (GRB, 800 kHz) |

Both pads are mapped in the Seeed XIAO variant (`g_ADigitalPinMap[30] = 9`,
`[31] = 10`), so `pinMode`/`digitalWrite`/Adafruit_NeoPixel work on them
directly once NFC protection is off. The assignment between the two pads is
arbitrary — `neopixel.h` holds both as single-point `#define`s so they can be
swapped to match the actual wiring.

Pixel layout: **pixel 0 and pixel 10 are status indicators**; **pixels 1–9
are the strip**, with pixel 5 the centerline. The chain is wired with
data-in on the physical RIGHT end (chain pixel 0 = rightmost LED), so
the whole chain is mirrored relative to how the driver reads it:
renderers author in logical left-to-right space and
`led_frame::physicalIndex()` (`kChainReversed = true`) maps
logical→wire once, at push time.

## NFC → GPIO: runtime UICR write, not a core build flag

The nRF52840 ships with the NFC pads dedicated to NFCT; converting them to
GPIO means programming `UICR->NFCPINS` bit 0 to 0, which latches only at
reset. **This is one-way in practice** (undoing it needs a full chip erase =
bootloader reflash) — accepted for this project; NFC is never used.

Two ways to do it, and we deliberately chose the second:

1. `-DCONFIG_NFCT_PINS_AS_GPIOS`: consumed by the *core's*
   `system_nrf52840.c` — a `.c` file, which the repo's established
   `compiler.cpp.extra_flags` mechanism does not reach. It would need a
   second `compiler.c.extra_flags` build property in every workflow AND
   local IDE configuration nobody will remember.
2. **Runtime write in `NEOPIXEL_SETUP()`** (what we do): if
   `NRF_UICR->NFCPINS` bit 0 is still set, unlock NVMC, write
   `0xFFFFFFFE` (a 1→0-only word write — no erase needed), relock, and
   `NVIC_SystemReset()`. One reset per device lifetime; every later boot
   skips the branch entirely. Works identically for CI, IDE, and OTA
   builds.

Constraints that dictate the placement of `NEOPIXEL_SETUP()` in `setup()`:

- **Before the SoftDevice comes up.** Direct NVMC access is illegal once the
  SoftDevice is enabled; on the beta channel `SENSOREGG_SETUP()` calls
  `bleCoreEnsureInit()` at boot, so the neopixel setup must run earlier.
  It sits right after the settings block, before `CAMERA_SETUP()`.
- **Before `wdtSetup()`** (armed last in `setup()`), so the one-time reset
  can't race the watchdog.
- After `SETTINGS_SETUP()`, so `led_brightness` is readable (brightness 0 =
  LEDs disabled entirely — the boost is never even enabled).

The reset lands in `captureBootWakeCause()` as a plain soft reset — a normal
boot, no special handling.

**The flag-off build must never touch UICR or drive pins 30/31.** The entire
module body is inside `#if BIRDSEYE_ENABLE_NEOPIXEL`; the `#else` stubs do
nothing (sensoregg.ino pattern).

## The global brightness cap — the core requirement

One rule: **once set, no LED may ever exceed the cap.** Enforced in one
place — `led_frame::applyCap()`, called exactly once per frame in the push
path. Every mode and animation authors colors in full 0–255 and never
worries about brightness; the cap is a post-condition tested by sweeping
caps × saturated frames in the host tests. We deliberately do NOT use
`Adafruit_NeoPixel::setBrightness()` (it rewrites the pixel buffer lossily
and would spread the invariant across call sites).

Default `led_brightness` = 64 (~25 %). 11 px full-white at 255 is ~660 mA
on the 5 V rail; at 64 it's ~165 mA — inside the boost's budget and sane on
battery, still clearly visible in daylight peripheral vision.

## Architecture

Pure logic (host-tested, Arduino-free) does everything except talk to pins:

| Unit | Owns |
|---|---|
| `led_frame.{h,cpp}` | Pixel layout constants, `Rgb`/`Frame` PODs, integer color scaling, **`applyCap()`** |
| `led_modes.{h,cpp}` | Pace pip math, generic `ScaleSpec` fill (RPM now, temps later), the `StatusAction` table + `evalStatus()` hysteresis/flash |
| `led_animations.{h,cpp}` | Boot + purple-sector animations as pure functions of `(tMs, seed)` |
| `sector_purple.{h,cpp}` | Session-best ("purple") sector detection, poll-and-diff |

The glue (`neopixel.{h,ino}`) snapshots inputs each frame, composes by
priority, applies the cap, and pushes to the strip:

```
NEOPIXEL_LOOP()  (30 Hz self-throttle)
 ├─ inputs: tachLastReported, activeTimerPaceDifference() + validity,
 │          sensoreggEgtC() (isNanF-guarded), raceActive, parked flags
 ├─ sector_purple::update() → nonzero: restart purple animation
 ├─ compose (first match wins):
 │    1. boot animation running
 │    2. purple animation running
 │    3. parked (BLE/USB) ‖ !raceActive ‖ brightness==0 → all off
 │    4. strip: pace valid ? pace pip : RPM scale
 │       status px0/px10: evalStatus(action table)
 ├─ led_frame::applyCap(frame, settingLedBrightness)
 └─ strip.setPixelColor()×11, strip.show()
```

### Strip mode policy

Off outside a race session — the strip is a driving aid, menu glow burns
battery. In race: **RPM scale** until pace is valid, then the **pace pip**.
Pace validity mirrors the OLED pace page:
`activeTimerRaceStarted() && activeTimerLaps() >= 1` and not
sprint-between-runs. Sprint between runs falls back to the RPM scale.

### Pace pip

`activeTimerPaceDifference()` is **ms per meter**, positive = slower than
best. Full deflection at ±1.0 ms/m (`kPaceFullScaleMsPerM`) — on a ~1.2 km
kart lap that's ~1.2 s/lap, a pin-the-needle delta; 0.25 ms/m per pixel
step. Deadband ±0.125 (half a step) shows the dim-white center pixel =
"on pace". Slower = pip LEFT of center in red, faster = RIGHT in green.

### Scale mode (RPM, later temps)

Generic `ScaleSpec {min, max, redFrac, lowColor, highColor}` — fill from
the left, lit pixels at/past `redFrac` of the fill render the high color.
RPM uses `{0, rev_limit, 0.5, green, red}` — red past halfway, per spec.
The same renderer will serve EGT/temp scales when phase 2 makes the mode
selectable.

### Status LED actions — the phase-2 assignability hook

Each status LED is driven by a `StatusAction` POD:
`{source, threshold, clearBelow, color, flashHalfPeriodMs}` evaluated
against per-frame values with a hysteresis latch. Hardcoded defaults now:

- **px 0**: rev-limit flasher — red, fires ≥ `rev_limit`, clears < 97 %,
  100 ms half-period.
- **px 10**: EGT flasher — orange, fires ≥ 650 °C (`kEgtAlertC`), clears
  < 630 °C, 250 ms half-period. NaN/stale EGT (isNanF!) → LED off AND
  latch released — never latch stale data (house rule).

Phase 2 ("user controls these settings") parses settings into the same
POD table — the evaluation code doesn't change, only where the table comes
from. `Source` is an enum (`kNone/kRpm/kEgtC`) that grows entries as new
sources appear.

### Animations — deterministic by construction

No `rand()`, no `millis()` inside the units: a frame is a pure function of
`(tMs since start, seed)`. Sparkle positions come from an xorshift-style
hash of `(seed, timeSlot, pixel)`, so host tests golden-lock exact frames.
The glue supplies `millis()` deltas and a `micros()`-derived seed (house
entropy rule — never `analogRead`).

- **Boot** (2600 ms): hue comet circling all 11 px as a ring (2
  revolutions with trailing fade, 0–1500 ms), global fade-out
  (1500–2200 ms), white sparkle glints overlapping (900–2600 ms).
  Non-blocking — plays over the GPS status page.
- **Purple sector** (1600 ms): purple wave expanding from the center px
  outward across strip + status (0–400 ms), solid purple with sparkles
  (400–1200 ms), fade out (1200–1600 ms). Overrides strip AND status;
  normal mode resumes automatically; a new purple mid-animation restarts
  it.

### Purple detection — and the sector-3 / lap-line race

The library (DovesLapTimer / SprintTimer) exposes `getCurrentSector()`,
`getCurrentLapSector{1,2,3}Time()`, `getBestSector{1,2,3}Time()` — but
`updateBestSectors()` runs **at the start/finish crossing**, not at each
sector line. So at the exact moment sector 3 closes, the library may have
already folded this lap into the "best" values and rolled the current-lap
times to the new lap. `sector_purple` defeats this by never comparing
against live state at a close edge:

- **Best times are snapshotted when each sector OPENS** (`bestAtOpen[3]`).
- S1/S2 close on `getCurrentSector()` transitions (1→2, 2→3): compare the
  just-closed `getCurrentLapSectorNTime()` against `bestAtOpen[n]`, then
  snapshot the next sector's best.
- **S3 closes on the lap edge** (`laps` increment), and its time is
  *derived*: `s3 = lastLapTime − s1 − s2` (guarded on both being present
  and the difference positive) — both inputs immune to the library's
  lap-line side effects. Compare vs `bestAtOpen[2]`, re-arm for the new
  lap.
- Purple fires only when the beaten best was **nonzero** — no purple
  anywhere on lap 1 (flashing every first-lap sector is noise).
- `sectorsConfigured == false` (Lap Anything / WaypointLapTimer has no
  sectors) or race not started → full reset, never fires.

Three new sprint-first wrappers join the `activeTimer*()` family:
`activeTimerCurrentSector()`, `activeTimerLapSectorTime(n)`,
`activeTimerBestSectorTime(n)` (WLT/null → 0).

## Sleep / wake

GPIO state is **retained in System OFF** (the "blue LED stays on after
sleep" field report). `NEOPIXEL_SLEEP()` — slotted in `enterShutdown()`
with the IMU rail-off, before the charging branch so the strip is dark
while charging too — therefore unconditionally:

1. blanks the strip and `show()`s while 5 V is still up,
2. drives the data pin LOW (never leave data high into an unpowered strip
   — it back-powers the pixels through the data diode),
3. drives boost EN LOW — the 5 V rail is truly off, retained through
   System OFF.

`NEOPIXEL_WAKE()` (charging-loop soft resume, beside `SENSOREGG_WAKE()`):
EN HIGH, ~5 ms boost settle, blank frame; composition resumes next loop.

## Parked loop branches

The BLE-transfer and USB-MSC branches early-return before the main frame.
`NEOPIXEL_LOOP()` is called inside both so composition sees "parked" and
blanks the strip — a frozen mid-pattern strip would look crashed.

## Settings

| Key | Default | Meaning |
|---|---|---|
| `led_brightness` | `"64"` | Global cap 0–255; 0 = LEDs disabled (boost never enabled) |
| `rev_limit` | `"15000"` | True RPM for the scale ceiling + rev flasher; clamp 1000–20000 |

Both rows added unconditionally to `ensureDefaultSettings()` (uniform
SETTINGS.json across channels — the SensorEgg DOVEX-column precedent).
Phase 2 adds mode/action assignment keys.

## Feature flag / channels

`BIRDSEYE_ENABLE_NEOPIXEL` (`project.h`, `#ifndef` default 0, tested with
`#if`): **on** in beta (`beta.yml` + `compile-sketch.yml` for
BETA-targeted PRs), **off** in master/release. The `Adafruit NeoPixel`
library is installed in all three workflows either way (harmless when
unused; keeps the lists uniform).

## Radio / timing safety

Adafruit_NeoPixel's nRF52 backend claims a *free* PWM instance
(`ENABLE == 0`) per `show()`, drives it via EasyDMA and busy-waits SEQEND
with **interrupts on** (~0.4 ms for 11 px ≈ 1 % CPU at 30 Hz). This sketch
uses no `tone()`/`analogWrite()`/HwPWM, so PWM0–2 are always free; TIMER3's
GPS drain and the tach ISR are unaffected. Two things future maintainers
must not "fix":

- If ever all PWMs are occupied, the library falls back to a
  cycle-counted bit-bang **with interrupts disabled** for ~0.4 ms. Still
  inside the 256 B serial ring's ~44 ms slack, but don't create that path.
- `show()` mallocs/frees a ~560 B PWM pattern buffer every call. Same-size
  alloc/free is fragmentation-benign on this allocator — it is not a leak.

## Sim

`neopixel.ino` is excluded from the sim TU (BLE-module precedent) and its
surface no-op'd in `module_stubs.cpp`. The four pure units join
`SIM_CORE_SOURCES`. The three sector wrappers get sim_prototypes entries.

## Hardware-only verification (open items)

- One-time UICR write + single self-reset on first flag-on boot.
- Boost EN polarity (assumed HIGH = on, Adafruit precedent) + settle time.
- GRB color order and strip orientation (`kChainReversed` if mounted
  data-end-right).
- Real current draw at cap 64; sleep current with EN low.
- 3.3 V data into 5 V pixels — user bench-proven on another nRF board.
- Cold power-on EN float: before `setup()` the EN pin floats; if the boost
  board pulls EN up, the strip powers briefly with idle data — harmless
  (pixels stay dark), noted for completeness.

## Phase 2 (deliberately out of scope here)

Settings-driven assignment: strip mode selection, per-status-LED action
source/threshold/color, temp scales via `ScaleSpec`, C/F preference,
brightness UI. The POD tables above are the interface that phase fills in.

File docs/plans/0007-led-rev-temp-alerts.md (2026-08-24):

# 0007 — LED rev/overrev + temp alerts, GPS-search pip, engine-stopped gate

First track-shakedown follow-up to the NeoPixel subsystem (plan 0006). Four
changes, all driven by real use on a kart with a 7600 RPM hard limiter.

## Two rev thresholds, two meanings

- **`rev_limit`** (existing setting, semantics sharpened): the WARNING
  limit — where the driver wants to know the engine is at the ceiling
  (7550 on the reference engine, just under its 7600 limiter — a carb
  tuning indicator). Drives the left status LED's red flasher and the
  RPM-scale ceiling, exactly as before — and nothing else: the warning
  deliberately does NOT touch the OLED.
- **`overrev_limit`** (new, default `0` = disabled): the PROBLEM limit —
  if the engine ever spins here (8500 reference), something is
  mechanically wrong. While latched, the **whole 11-px chain flashes
  red**, overriding everything except the boot animation (an engine
  problem outranks the purple celebration), and the OLED tach page
  shows `*OVER REV*` — that header is tied to this SAME limit, only
  when enabled (>0) and tripped, never at the warning limit (it had
  been hardcoded at a meaningless `> 9999`). The latch releases below
  `rev_limit × 0.97` — the same clear fraction the warning flasher uses,
  so a brief spike leaves an unambiguous flash rather than a flicker.
  Implemented with the existing `StatusAction`/`evalStatus` machinery
  (its `StatusState.active` latch drives a whole-frame fill in the
  glue) — no new evaluation code, and phase 2 can expose it like any
  other action.

## Temp alert on the right status LED — tri-state

New setting **`temp1_alert_c`** (default `650` °C ≈ 1200 °F, the value
that was previously a constexpr). The right LED becomes:

- **flashing red** at/above the threshold (was orange; red per driver
  preference), clearing 20 °C below it (the existing 650/630 hysteresis
  generalized);
- **off** when the reading is good and below the limit;
- **solid blue** when there is *no probe signal* — Temp1 is NaN/stale
  (egg dropout, hung egg, no egg). `StatusAction` grew an
  `invalidColor` field for this; the rev flasher sets it to off, so
  nothing else changes. A logger with no egg paired shows blue all
  race — accepted for now; phase 2's assignability makes it
  configurable.

## GPS-search pip

Race mode with no GPS lock used to show the RPM scale — nothing told
the driver why laps weren't timing. Now the strip shows a single green
pixel bouncing end-to-end (triangle wave, 1.6 s round trip,
`led_modes::renderSearchPip` — a pure function of elapsed time, host
tested) until `gpsData.fix && gpsData.timeValid` — the same condition
that allows log-file creation and releases the WAITING-GPS-LOCK page
pin. Then RPM scale, then pace once the first lap is in (unchanged).

## Engine-stopped gate

If a session's engine has proven itself (`raceEntryCause ==
RACE_ENTRY_TACH` — which manual/speed sessions promote to at >500 RPM,
so no-tach devices are untouched) and the tach reads 0, the session is
in a stall/DNF posture, not a lap:

- the 9-px bar goes dark (a pace pip counting away next to a dead
  engine reads as a glitch);
- the **status LEDs stay live** — the temp alert while a hot engine
  cools is exactly when it matters;
- the OLED pace page shows **STOPPED** instead of a still-counting pace
  number (and suppresses the notably-faster flash animation).

A restart clears it automatically — the tach reports nonzero within one
loop of the first pulse burst.

Shared condition: `raceEngineStopped()` in the sketch, used by both the
LED glue and the pace page.

## Strip composition after this plan

```
boot animation
 > overrev whole-chain red flash          (race only, latched)
  > purple sector celebration
   > parked / not racing / brightness 0 -> off
    > race strip:
        engine stopped        -> bar off (status LEDs live)
        no fix+timeValid      -> green search pip bouncing
        pace valid            -> pace pip
        else                  -> RPM scale
      status px0: rev-limit flasher (red, >= rev_limit, clear 97%)
      status px10: temp tri-state (blue = no signal / off / red flash)
```

## Settings summary

| Key | Default | Notes |
|---|---|---|
| `rev_limit` | `15000` | unchanged — LED warning flasher + scale ceiling only |
| `overrev_limit` | `0` | 0 = disabled; clamp 1000–20000; whole-chain red flash |
| `temp1_alert_c` | `650` | °C; clamp 50–1200; clear = alert − 20 °C |

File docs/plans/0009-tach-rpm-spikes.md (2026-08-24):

# RPM Spikes — Outlier Gate, RPM-Aware Noise, and a Track-Side A/B Switch

> Status: **IMPLEMENTED**, awaiting track validation. Prompted by a field
> report: a single-cylinder kart with a digital-chip magneto, whose plotted
> DOVEX `rpm` column is full of spikes that the engine plainly did not do.
>
> The reporter's hypothesis was that the filter was *over*-compensating.
> It was the opposite — see below. The `tach_filter` setting exists so that
> question gets answered with a session at the track rather than an argument
> about a graph.

## The complaint

> "I understand it's a small single cyl engine, but our magnetos do have
> digital chips in them, RPM in my opinion should appear more stable than it
> is. Are we compensating too much with the interpolation?"

## What was actually happening

There is no interpolation in the RPM path — there never was. The pipeline is:
ISR timestamps each falling edge → `TACH_LOOP()` computes the mean of the
inter-pulse periods that arrived since the last call → that mean becomes one
RPM number → a 1-D Kalman filter folds it in. The 25 Hz DOVEX row is a point
sample of whatever the filter last published.

Three defects in that chain, none of them "too much smoothing":

### 1. One bad edge went straight to the output

The estimator's steady-state gain was ~0.43 (Q = 800, R = 2500), so **43% of
every single measurement landed in the published value** — and a measurement
is one period. At 3000 RPM (a 20 ms period), an ignition ring that clears the
3 ms debounce by arriving 4 ms after a real edge reads as 15 000 RPM. The
filter had no way to tell that from the engine, so it moved ~5000 RPM. One
bad microsecond reading, one spike on the graph. A *missed* spark is the
mirror image: the period doubles, the measurement halves, the trace dives.

The 3 ms debounce is a fixed ceiling guard (~20 000 pulses/min), not a
running-speed guard. At 3000 RPM it leaves 17 ms of every period wide open to
a spurious edge.

### 2. The noise model was RPM-blind, and RPM error is quadratic in RPM

RPM = K / period, so `dRPM/dT = RPM² / K`: a **fixed** timing error is worth
**quadratically more RPM** the faster the engine turns. 80 µs of ISR latency
(the tach handler is deferred by SoftDevice radio ISRs like everything else
at app priority) costs 6 RPM at 3000 and 143 RPM at 14 000. A flat
R = 2500 RPM² (50 RPM σ) was about right at 4000 RPM and far too confident
above 8000 — so the filter trusted its noisiest measurements the most,
which is why the trace got worse the harder the engine was working.

### 3. Process noise was charged per update, not per second

Updates arrive at the *pulse* rate. A fixed Q = 800 per update means the
filter's time constant is constant in pulses and therefore **four times
looser at 12 000 RPM than at 3000** — and looser again whenever an SD GC
stall batched several pulses into one update. The amount of smoothing
silently depended on engine speed and on SD card mood.

## The fix (all in the `tach_filter` pure unit)

1. **Outlier gate.** A measurement more than `kGateSigmas` (5) from the
   estimate, measured against the combined estimate + process + measurement
   uncertainty, is not folded in — the estimate coasts. 5σ is deliberately
   loose: the gate is there for the half-period and double-period signatures
   of a spurious/missed spark, which are tens of sigma out, not to trim
   honest noise. A 5500 RPM/s pull moves the crank ~25 RPM between pulses,
   so real acceleration cannot trip it (asserted in the tests).
2. **Escape hatch.** Three *consecutive* rejections is not three coincident
   bad edges — it is a real step change (clutch dump, spin, a batch lost to
   a stall) and the estimate is the thing that is wrong. The third
   measurement is **adopted outright** rather than filtered toward, which is
   what makes an instant 11 000 → 4000 drop settle in 80 ms (faster than the
   old filter's 120 ms). Rejections must be consecutive, or a pickup emitting
   one bad edge every few seconds would eventually adopt one of them.
3. **`measurementNoise()` knows the RPM** — the quadratic timing-jitter term
   plus a linear term for genuine crank speed variation between firings
   (a single-cylinder engine really does speed up and slow down within a
   revolution; that is not measurement error, but nobody wants it plotted).
   It also knows `revsPerPulse`, so a twin's shorter periods are correctly
   treated as noisier at the same RPM.
4. **`processNoise()` is a rate** (RPM²/s) times the engine time the batch
   spans. `TACH_LOOP()` passes the sum of the periods it just consumed, not
   wall clock — at 1500 RPM those differ by 40x, and charging process noise
   for time the crank did not turn is the same mistake in a new place.
   The rate is set so the filter behaves exactly like the old one at
   6000 RPM, and unlike it, keeps behaving that way everywhere else.
5. **First measurement after a reset is adopted.** With no prior, filtering
   toward it through an RPM-aware R takes several pulses to arrive anywhere
   true — and the gate would arm partway up that climb and start rejecting
   the engine's real speed.

## Modelled result

Whole-pipeline simulation (ISR debounce → ring batching with 30 ms loop
stalls → filter → 25 Hz sampling), constant engine speed, 1% crank
variation, 150 µs ISR latency jitter, 0.5% spurious edges and 0.5% missed
sparks. Error against the true RPM, in RPM:

| Engine | legacy σ | legacy worst | **smooth σ** | **smooth worst** | raw σ |
|---|---|---|---|---|---|
| 1 500  | 501 | 6 352 | **16** | **163** | 943 |
| 3 000  | 292 | 5 657 | **19** | **286** | 446 |
| 6 000  | 420 | 5 031 | **22** |  **80** | 677 |
| 10 000 | 220 | 2 809 | **22** |  **75** | 448 |
| 14 000 | 254 | 2 977 | **22** |  **73** | 482 |

Cost, on a clean signal: a 5500 RPM/s pull lags 489 RPM instead of 267
(~90 ms). An instant 11 000 → 4000 step settles *faster*, 80 ms vs 120 ms.

Note the `raw` column. It is worse than legacy at every engine speed —
because it is the pickup, unfiltered. That is the number that answers the
original question: the filter was not manufacturing the spikes, it was
passing them through.

## The `tach_filter` setting

| Value | Behaviour |
|---|---|
| `smooth` (default) | Everything above. |
| `legacy` | The pre-0009 filter, bit for bit — fixed Q/R, no gate. Comparable against existing logs. |
| `raw` | No estimator at all: the DOVEX `rpm` column is exactly what the periods say. |

Anything unrecognised reads as `smooth`, the house idiom. The mode is read
once at boot and applied before the filter, so it affects display, DOVEX
rows, the camera FSM and the LEDs identically — there is still exactly one
RPM number in the firmware (plan 0003's rule).

**Why a setting and not just the fix.** The spikes are either the pickup or
the estimator, and no amount of reading the code settles which. `raw` for one
session shows the signal with nothing in the way; `legacy` reproduces the
logs already collected; `smooth` is what ships. Three sessions at one track
day and the question is closed.

**Deliberately not a DOVEX column.** Logging raw and filtered side by side
would A/B in a single session, but it forks the log format for a debug
feature and needs a viewer change. The setting switches what goes into the
existing `rpm` column, so nothing downstream has to know.

## Pickup-health diagnostic

With `debug_pages` = `show`, the tachometer page's subtext line becomes
`max:NNNNN S rj:NN` — the estimator in force and the number of periods the
gate has thrown away this power-cycle. It is the direct measurement of
signal quality: single digits over a session means a clean pickup; a count
that climbs with RPM is ignition ringing or missed sparks reaching the ISR.
The count deliberately survives the engine-stop reset, or it would zero at
every corner.

## Not done, on purpose

- **Adaptive (RPM-scaled) blanking in the ISR.** Modelled first, and it made
  things *worse*: blanking off the last accepted period means one spurious
  edge blanks the next real one, which manufactures a doubled period and a
  downward spike. It would have to blank off the filtered estimate, which
  puts filter state in the ISR. The gate solves the same case downstream
  with none of that.
- **Re-tuning the debounce floor.** It is a ceiling guard and correct as is
  (plan 0003). Ringing that clears it is the gate's problem now.
- **Time-window averaging of the logged column.** The estimator is now
  quiet enough (σ ≈ 20 RPM) that resampling would only add lag.

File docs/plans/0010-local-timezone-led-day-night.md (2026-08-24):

# Local Timezone (fixed offset) + LED Day/Night Brightness

> Status: **IMPLEMENTED**. Scope was deliberately cut twice during design —
> once to drop DST, once to keep local time out of the logging pipeline
> entirely. Both cuts are load-bearing; read *Non-goals* before widening this.

## The ask

> "I want to toggle the lights between daylight and night time, but sunrise/
> sunset isn't warranted — 7am needs to be local 7am."

The NeoPixel strip (plan 0006) runs at one brightness cap around the clock.
At a night event that cap is either blinding or, if turned down for the dark,
useless in daylight. The fix is a second cap and a clock to switch on.

## Why the device had no clock to switch on

The GPS delivers UTC and nothing in the firmware had ever needed anything
else. `gpsData.hour` is raw UTC out of the PVT callback
(`gps_functions.ino`), and every consumer — filenames, the DOVEX header
`datetime`, generated course names — wants UTC anyway. So there was no
timezone concept to fix; there was one to add.

The failure mode without it is not subtle. A US Central driver at 07:30
local is at 12:30 UTC: a naive UTC gate calls that the middle of the night
and dims the strip in broad daylight. Symmetrically, a 21:00 local session
is 02:00 UTC *the next day*, so the gate gets the right answer for the wrong
reason and the date is off by one.

## What was built

A pure unit, `local_time.{h,cpp}`, and a single consumer.

**`local_time`** — a fixed signed offset in minutes, applied to a 4-digit-year
`DateTime`, with correct date rollover in both directions across month, year
and leap-day boundaries. Plus `isNight()`, which tests membership in the
window `[nightStart, dayStart)` *modulo the day*, so the ordinary wrapped case
(19:00 → 07:00) needs no special casing at the call site. Host-tested
(`tests/local_time_test.cpp`), Arduino-free, builds into the sim.

Three details worth keeping:

- **Minutes, not hours.** India is +5:30, Newfoundland −3:30, the Chatham
  Islands +12:45. An hours-only offset is wrong for real places.
- **Four-digit year.** `GpsData.year` is 2-digit for compatibility with the
  existing filename and header format strings; the unit takes 4 digits and
  callers add 2000. The leap rule (`gps_time::isLeapYear`, reused rather than
  re-derived) genuinely needs the century, and a future feature that wants
  real civil time will need it too.
- **An out-of-band offset is ignored, not clamped.** A corrupt setting must
  not be able to walk the calendar; it falls back to 0, which is exactly the
  pre-0010 behaviour.

**The consumer** is `npxEffectiveBrightness()` in `neopixel.ino`, feeding
`npxPushFrame()`. That function was already the single global-brightness
choke point (`led_frame::applyCap`, plan 0006), so the whole feature is a
change of argument at one call site — the invariant that no channel ever
exceeds the cap is untouched.

## Non-goals — the two cuts

**No DST, on purpose.** A fixed offset means the boundary walks an hour twice
a year. For a "stop blinding the driver after dark" gate that is beneath the
feature's resolution. The alternatives were US/EU rule tables (~40 lines and
a permanent correctness liability as legislatures keep changing the dates) or
tzdata (~100 KB and needs shipping updates to a sealed device). Neither buys
anything a driver would notice. `local_time` is where the rules would go if
that ever changes.

**Local time never touches saved data.** DOVEX row timestamps are Unix epoch
milliseconds — UTC by definition — and the header `datetime`, the log
filenames and the generated course names all stay UTC. This is not laziness:
a log is routinely *viewed* somewhere other than where it was recorded, so
the conversion belongs on the presentation side, where the viewer's own
preference is known. The webapp already does most of this (it does not yet
offer local-timezone picking, which is where that work continues).

The practical consequence: nothing in the logging pipeline may call into
`local_time`. The header comment says so.

## Traps

1. **`led_brightness == 0` means "cut the 5 V rail", and only that setting
   does.** `NEOPIXEL_SETUP()`/`NEOPIXEL_WAKE()` hold the boost EN pin low when
   it is 0. A *night* brightness of 0 must therefore blank the frame and leave
   the rail up — power-cycling a boost converter at 19:00 mid-session is not a
   brightness change. `npxEffectiveBrightness()` keeps the two meanings apart.
2. **No clock means day, not night.** `gpsData.timeValid` requires the module's
   `fullyResolved`, which is up to ~12.5 minutes from a cold start. Rendering
   at night brightness in that window would mean a strip that comes up dark
   and reads as broken hardware. It renders at day brightness until the lock
   lands, then swaps.
3. **Equal hours disable the swap.** `isNight()` returns false for an empty
   window, so `led_day_start_hour == led_night_start_hour` means one cap
   around the clock — no separate enable flag to keep in sync.

## The settings file was one key away from bricking

Adding four keys turned up a latent cliff. `settings.ino` had a 512-byte
file buffer and a `StaticJsonDocument<512>`, and **every read path caps at
`sizeof(settingsFileBuffer) - 1`** — 511 bytes. The existing 18-key file
already serialized to **436 bytes**. The four keys here put it at **543**.

Past the cap the failure is silent and self-inflicting:

1. `settingsFile.read()` truncates at 511 bytes, mid-token.
2. `deserializeJson` returns `IncompleteInput`, so *every* `getSetting()`
   fails — not just the new keys.
3. `SETTINGS_SETUP()` reads that as corruption and quarantines the file to
   `SETTINGS.json.bad`, regenerating fresh defaults (new random BLE name,
   new PIN, new device name — the user's pairing is gone).
4. `ensureDefaultSettings()` then adds the missing keys back, one
   read-modify-write each, until the file crosses 511 again.
5. Loop, every boot, forever.

The document was a second, independent wall: a `<512>` doc returns
`NoMemory` at 22 string pairs (measured against the pinned ArduinoJson
6.21.5, not estimated).

Fixed by raising both to **1024** (keep them equal — the invariant is that
the buffer can always hold what the document serializes) and, because the
next contributor will not have measured, adding a guard in
`setSettingInner()` that refuses a write when the document `overflowed()`
or `measureJson()` exceeds the buffer. That converts a silent permanent
brick into one loudly refused write with the old file left intact.

Worth stating plainly: **adding a settings key is not free.** Check the
serialized size.

## Settings

| Key | Default | Notes |
|---|---|---|
| `utc_offset_min` | `0` | Minutes east of UTC; clamp ±840. US Central standard = `-360` |
| `led_brightness_night` | `16` | Night cap 0-255; 0 blanks the strip, rail stays up |
| `led_day_start_hour` | `7` | Local hour the day cap takes over |
| `led_night_start_hour` | `19` | Local hour the night cap takes over |

Written on every channel (the SensorEgg DOVEX-column precedent: uniform
`SETTINGS.json` shape), read only by a `BIRDSEYE_ENABLE_NEOPIXEL` build.
Settable over BLE via the existing `SSET` — no protocol work, and no
on-device entry UI, consistent with the no-text-entry rule.

## Follow-ups, not done here

- The webapp learning to pick a viewing timezone for logs.
- Local time on the OLED, if a page ever wants to show a clock.
- A day/night *look* (different colors/modes), rather than just a different
  cap. The cap was chosen for v1 precisely because it is one argument.

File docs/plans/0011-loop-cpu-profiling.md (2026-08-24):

# 0011 — Main-loop CPU profiling (beta channel)

**Status:** implemented (beta channel only)
**Flag:** `BIRDSEYE_ENABLE_PROFILING` (`project.h`, default 0; `beta.yml`
and `compile-sketch.yml` pass `=1` on the BETA branch)
**Touches:** `loop_profile.{h,cpp}` (new pure unit), `profiling.{h,ino}`
(new glue module), `BirdsEye.ino` (loop instrumentation, page constant),
`display_pages.{h,ino}` (LOOP PROFILE page), `display_ui.ino` (routing),
`neopixel.ino` (yields the boost EN pin), `beta.yml`,
`compile-sketch.yml`, `clang-tidy.yml`, `tests/`

## Why

The commercial board has to be specified, and two open questions gate it:

1. **nRF52840 or nRF5340?** The 5340 is the reliability upgrade for BLE
   (dedicated network core, so the radio stack stops sharing a CPU with
   the superloop), and it is more silicon than the product may need.
2. **Arduino core or Nordic SDK?** Leaving the Arduino core is a large,
   one-way piece of work. It is worth doing only if the core is where a
   meaningful fraction of the time goes.

Both are answerable with measurement rather than argument, and neither
is answerable today: the firmware carries no timing instrumentation
beyond a `HAS_DEBUG` "SLOW LOOP" print with millisecond resolution — too
coarse to see a subsystem that costs 400 µs, and compiled out of every
shipped build.

So: measure a real iteration, on the real hardware, under a real 25 Hz
GPS + logging + LED + BLE workload, and see where it goes.

## What "CPU usage" means here

> **Superseded, and the correction is the interesting part.** This
> section originally argued that a duty cycle was meaningless because
> `loop()` runs back to back and therefore the CPU is busy 100% of the
> time by construction. That was an *assumption*, it was baked into the
> measurement (see *Two clocks* below), and it made the first hardware
> reading wrong. The profiler now measures how much wall time is
> actually spent executing `loop()` and reports the balance as `SLP`.
> Everything below about the shape of an iteration still holds; it is
> just no longer the only thing worth reporting.

The number that carries information is the **shape of an iteration**:

- how long one takes (mean **and** worst case — an SD garbage-collection
  stall of 100 ms–2 s is invisible in a mean),
- how that time divides between subsystems,
- how much of it no subsystem accounts for.

That is what decides both questions above. If the loop is 4 ms and
`readButtons()`'s multi-sample debounce is 1.5 ms of pure blocking
`delayMicroseconds`, the answer is "fix the firmware", not "buy a bigger
chip". If it is spread evenly across genuine work, the chip is the
conversation.

## Two instruments

**The pin.** Pin 30 is driven HIGH for the span being profiled and LOW
outside it. A scope or logic analyser reads the loop period off the
rising edges and the span's cost off the high time, with no software in
the measurement path — which is exactly what makes it worth having
alongside the software numbers: it is the thing that says the software
is telling the truth. `PROFILING_PIN_SECTION` picks the span (the whole
loop body by default; `-DPROFILING_PIN_SECTION=PROF_SEC_GPS` and friends
re-point it).

**The rollup.** Every section is also timed in software and rolled up
once a second onto the LOOP PROFILE race page — first page of the race
rotation on a profiling build, three Lefts from the speed page the
session lands on. That is the instrument you can read while driving, and
the one that survives not having a scope at the track.
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

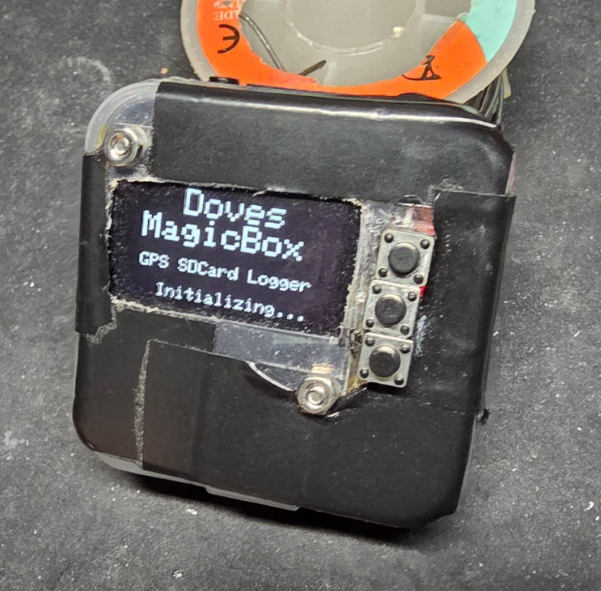
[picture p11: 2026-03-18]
CASE/projectbox.jpg

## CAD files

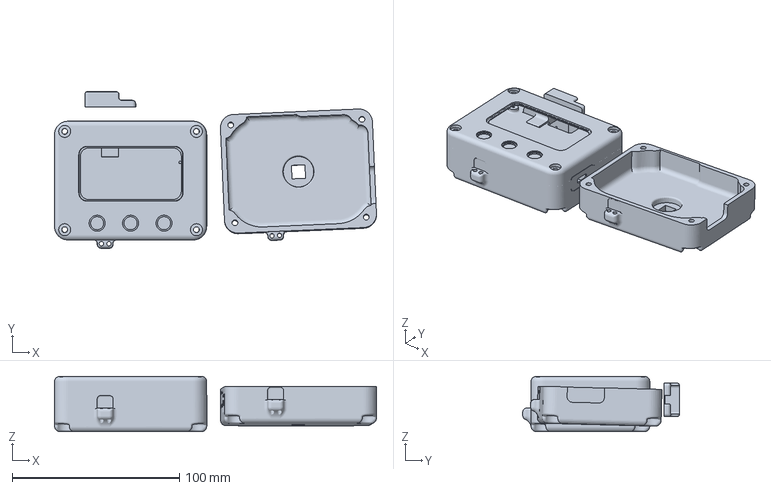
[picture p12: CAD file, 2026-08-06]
CASE/3MF/WHOLE-ASSEMBLY.3MF
192.6 x 93.6 x 33.0 mm

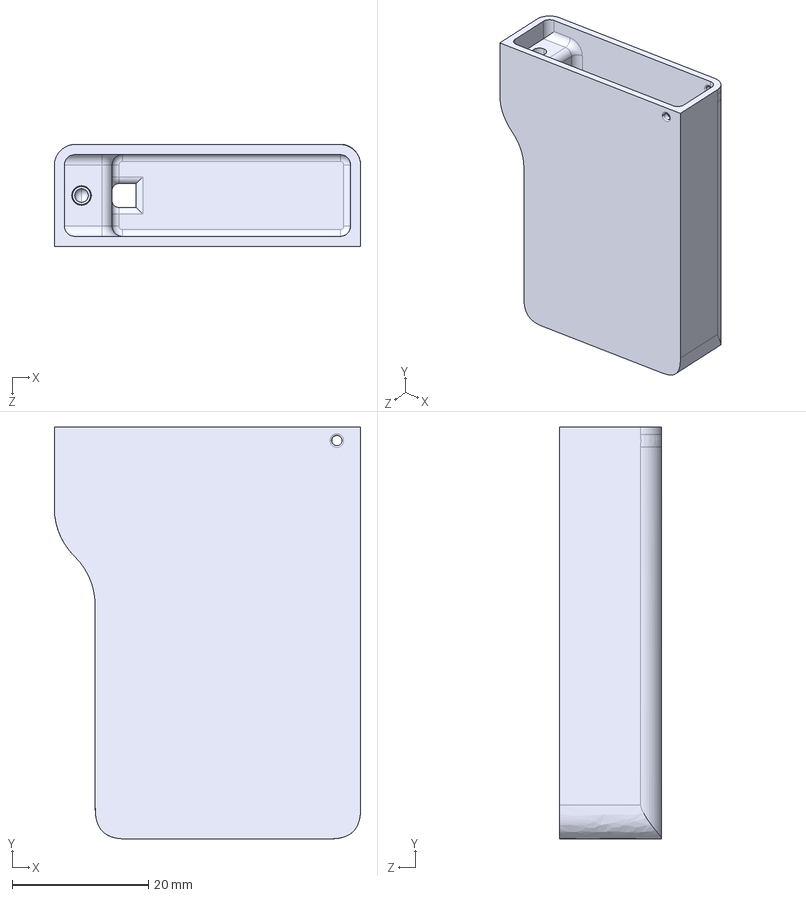
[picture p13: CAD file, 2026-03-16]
CASE/VER_1/STEP/battery.STEP
45.0 x 60.5 x 15.0 mm

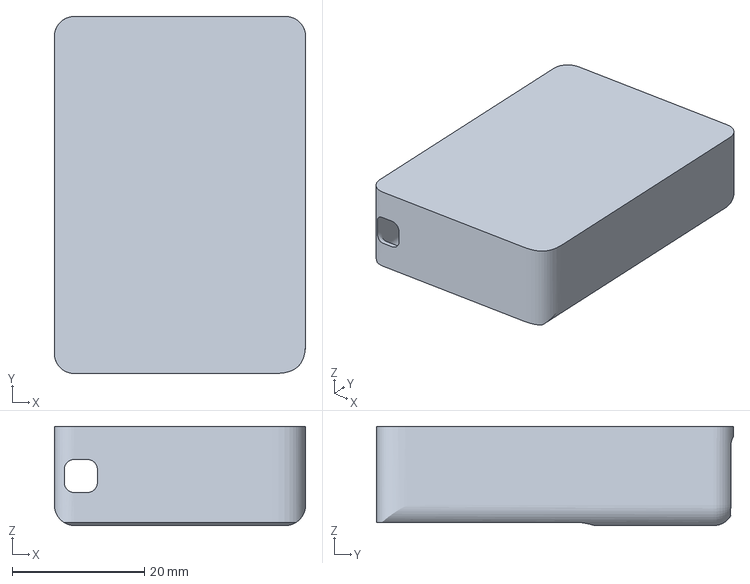
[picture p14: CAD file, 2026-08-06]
CASE/3MF/battery.3MF
38.0 x 54.0 x 15.0 mm

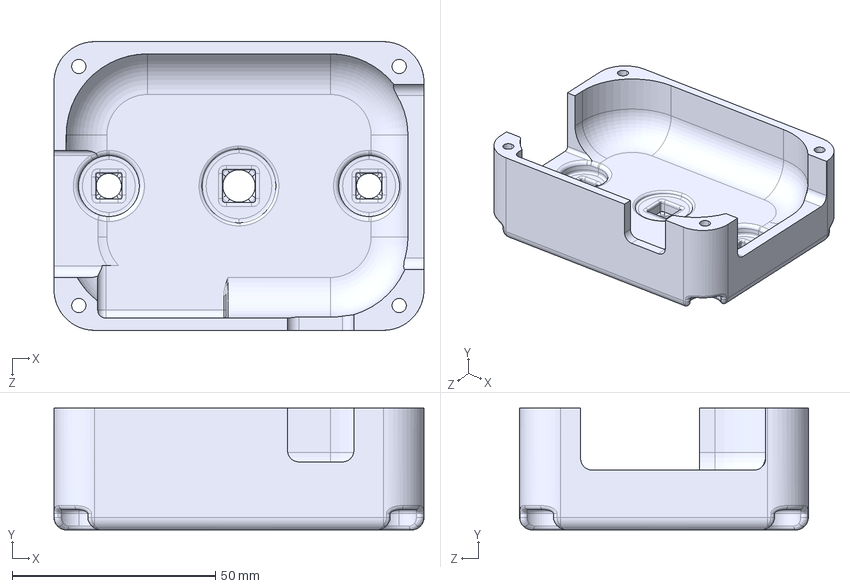
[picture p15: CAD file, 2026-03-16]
CASE/VER_1/STEP/case-back.STEP
91.0 x 30.0 x 71.0 mm

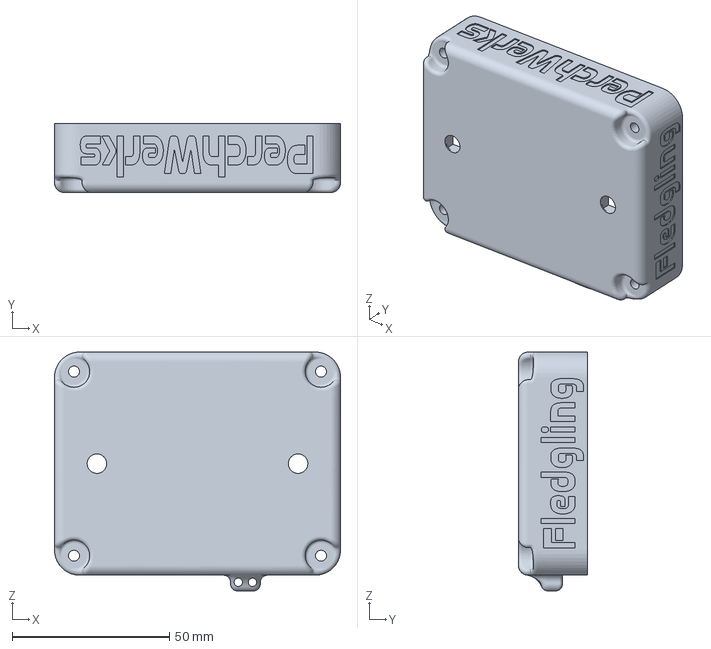
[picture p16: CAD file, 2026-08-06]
CASE/3MF/case-back.3MF
91.0 x 22.0 x 76.0 mm

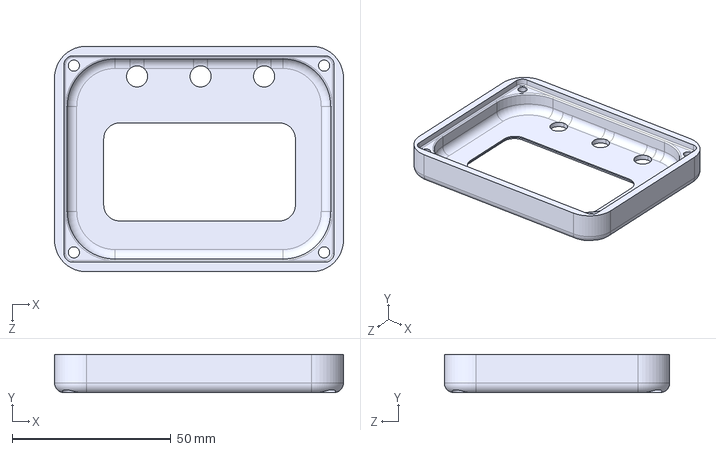
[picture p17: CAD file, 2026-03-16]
CASE/VER_1/STEP/case-front.STEP
91.0 x 12.0 x 71.0 mm

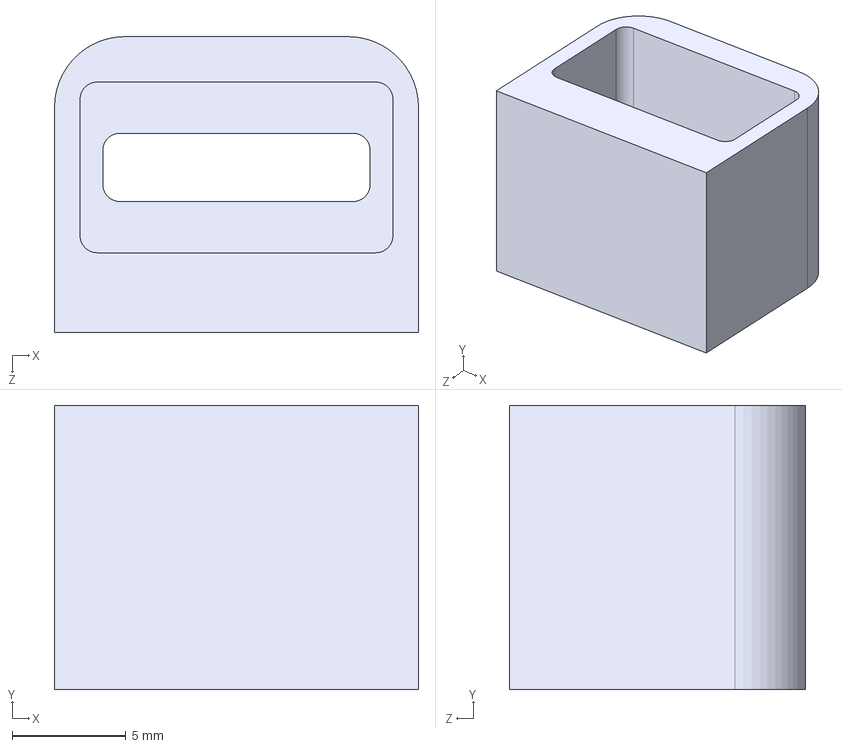
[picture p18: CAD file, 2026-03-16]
CASE/VER_1/STEP/switch-housing.STEP
16.0 x 12.5 x 13.0 mm

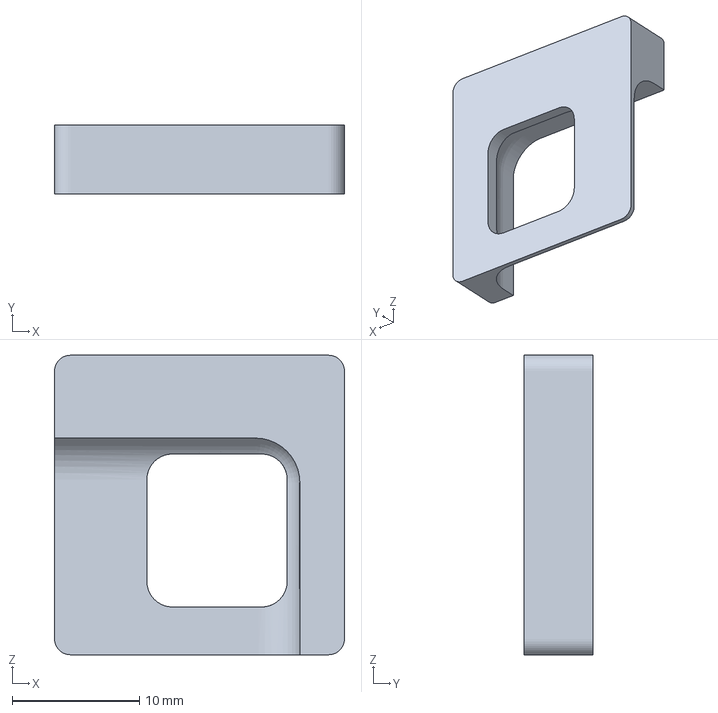
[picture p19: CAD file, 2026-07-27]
CASE/3MF/cpu-tray.3MF
22.8 x 5.40 x 23.5 mm

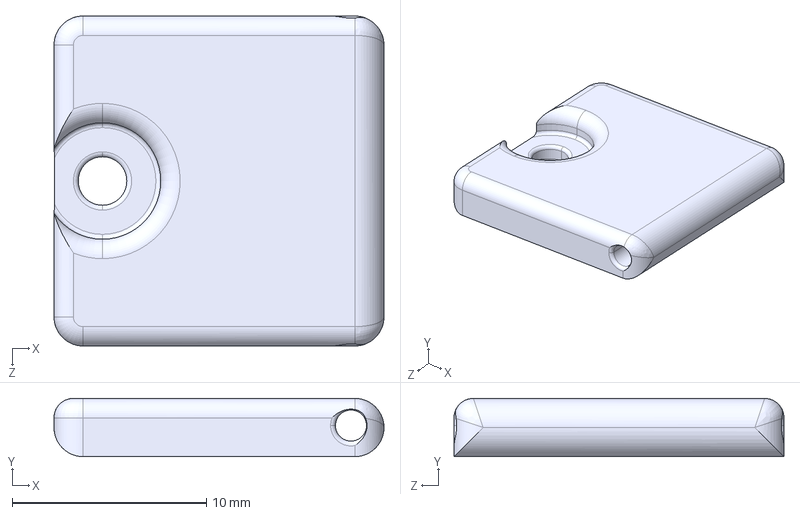
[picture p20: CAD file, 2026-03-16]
CASE/VER_1/STEP/sdcard-lid.STEP
17.0 x 3.00 x 17.0 mm

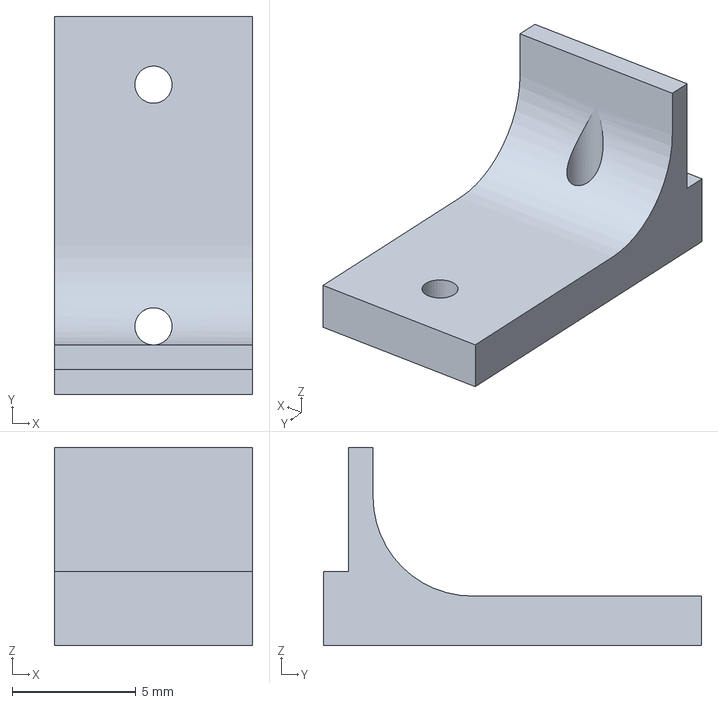
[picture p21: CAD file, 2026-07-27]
CASE/3MF/tach-bracket.3MF
8.00 x 15.2 x 8.00 mm

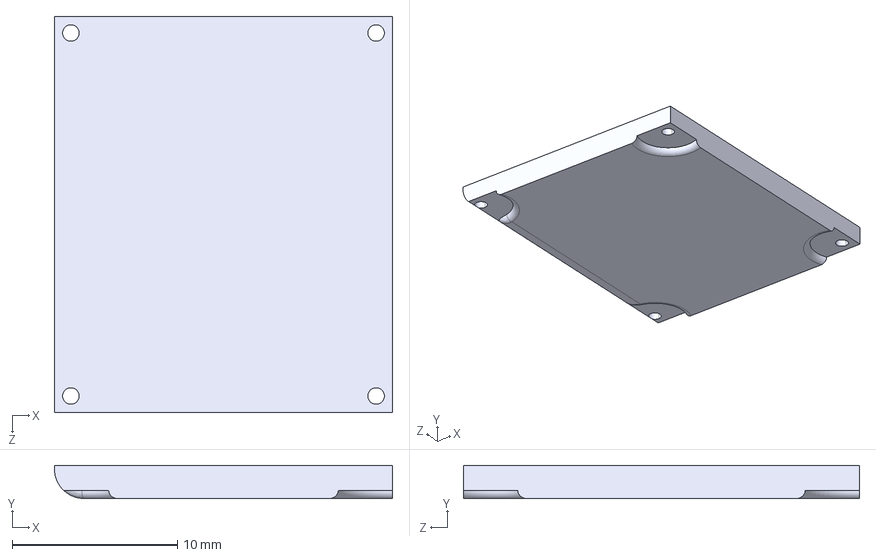
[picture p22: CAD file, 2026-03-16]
CASE/VER_1/STEP/cpu-lid.STEP
20.5 x 2.00 x 24.0 mm

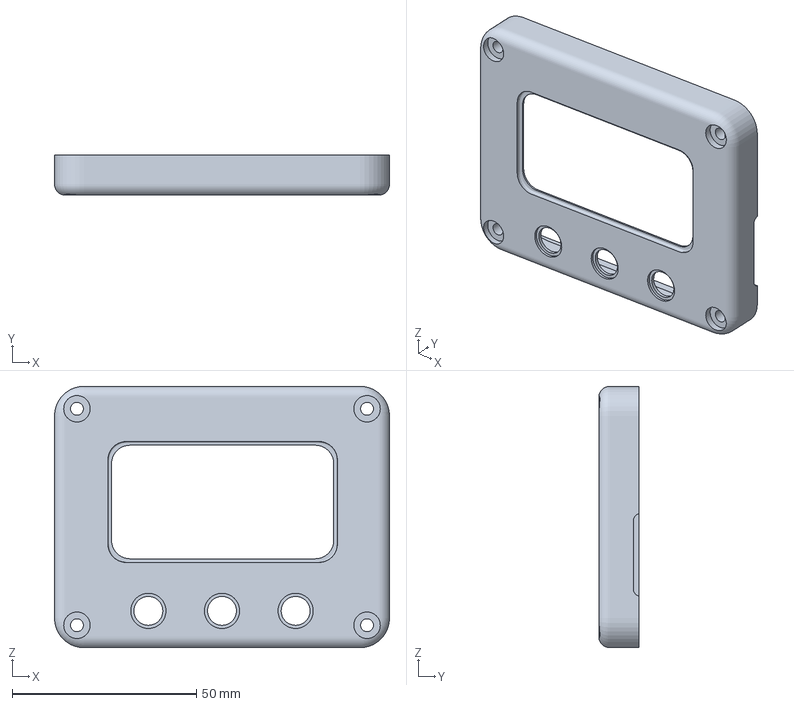
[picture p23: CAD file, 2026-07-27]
CASE/3MF/case-front.3MF
91.0 x 11.0 x 71.0 mm

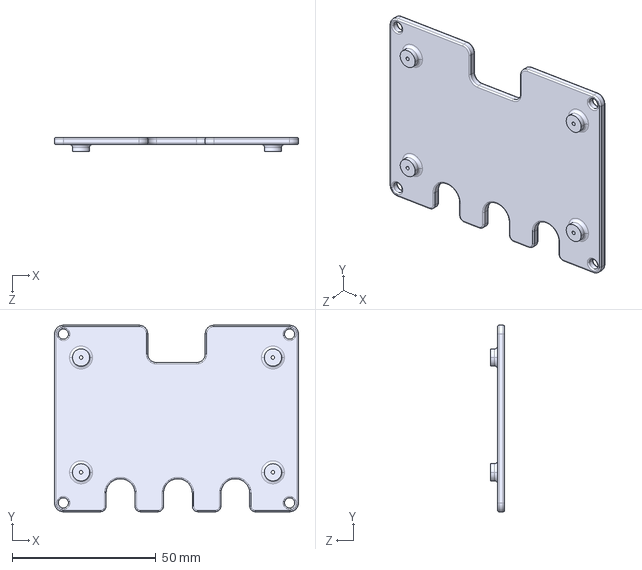
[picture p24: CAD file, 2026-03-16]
CASE/VER_1/STEP/baseplate.STEP
85.0 x 65.0 x 5.00 mm

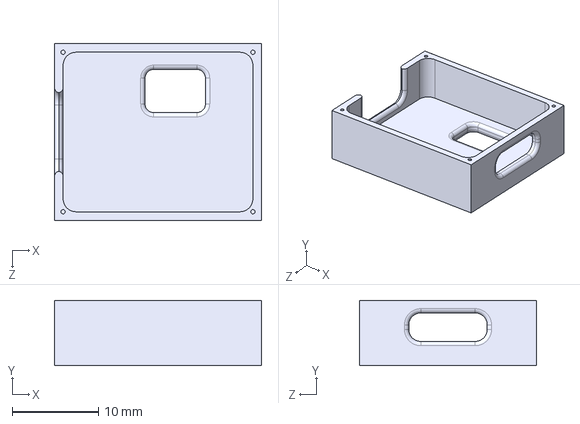
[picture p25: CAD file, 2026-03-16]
CASE/VER_1/STEP/cpu.STEP
24.0 x 7.55 x 20.5 mm

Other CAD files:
CASE/3MF/case-back-single.3MF
CASE/3MF/baseplate.3MF
CASE/VER_1/STEP/screen-cutout-template.STEP
CASE/3MF/GPS-HOLDER.3MF
CASE/3MF/cpu-lid.3MF
CASE/3MF/cpu.3MF
CASE/3MF/diy-gps.3MF
CASE/3MF/old-gps.3MF
CASE/3MF/usbc_charger.3MF
CASE/VER_1/3MF/baseplate.3MF
CASE/VER_1/3MF/battery-lid.3MF
CASE/VER_1/3MF/battery.3MF
CASE/VER_1/3MF/case-back.3MF
CASE/VER_1/3MF/case-front.3MF
CASE/VER_1/3MF/cpu-lid.3MF
CASE/VER_1/3MF/cpu.3MF
CASE/VER_1/3MF/gps.3MF
CASE/VER_1/3MF/screen-cutout-template.3MF
CASE/VER_1/3MF/sdcard-lid.3MF
CASE/VER_1/3MF/sdcard.3MF
CASE/VER_1/3MF/switch-cover.3MF
CASE/VER_1/3MF/switch-housing.3MF
CASE/VER_1/STEP/battery-lid.STEP
CASE/VER_1/STEP/gps.STEP
CASE/VER_1/STEP/sdcard.STEP
CASE/VER_1/STEP/switch-cover.STEP

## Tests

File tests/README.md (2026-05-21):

# Host-side unit tests

Lightweight test harness for the pure-logic units extracted from the
Arduino sketch. Runs on any machine with CMake ≥ 3.14 and a C++17
compiler — no Arduino tooling required.

## Layout

```
tests/
├── CMakeLists.txt          # host build
├── doctest.h               # vendored single-header framework (MIT, v2.4.11)
├── test_main.cpp           # defines doctest's main()
└── <unit>_test.cpp         # one file per unit under test
```

Each unit-under-test lives in `../BirdsEye/<unit>.{h,cpp}`. The same
`.cpp` is compiled by Arduino (firmware build) and by CMake (host test
build); there is no copy-paste.

## Running locally

```sh
cmake -S tests -B tests/build
cmake --build tests/build
ctest --test-dir tests/build --output-on-failure
```

Or run the binary directly to see per-test output:

```sh
./tests/build/birdseye_tests
./tests/build/birdseye_tests --help          # doctest CLI flags
./tests/build/birdseye_tests -tc='haversine*' # run a specific test case
```

## CI

Runs in `.github/workflows/unit-tests.yml` on every push and pull
request. The badge at the top of the project README reflects the
latest `master` run.

## Adding a test

1. Extract the function into `BirdsEye/<unit>.h` (declaration) and
   `BirdsEye/<unit>.cpp` (implementation). The `.cpp` must not pull
   in Arduino headers — use plain C++ / `<math.h>` / `<stdint.h>` /
   `<cstring>`. The corresponding `.ino` that used to define the
   function gets an `#include "<unit>.h"` instead.
2. Create `tests/<unit>_test.cpp`:
   ```cpp
   #include "doctest.h"
   #include "<unit>.h"

   TEST_CASE("…") {
       CHECK(...);
   }
   ```
3. Add the new sources to `tests/CMakeLists.txt`:
   ```cmake
   add_executable(birdseye_tests
     test_main.cpp
     <unit>_test.cpp
     ${BIRDSEYE_DIR}/<unit>.cpp
     ...
   )
   ```

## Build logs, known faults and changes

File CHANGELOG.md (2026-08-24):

# Changelog

All notable changes to this project are documented in this file.

The format is based on [Keep a Changelog](https://keepachangelog.com/en/1.1.0/),
and this project aims to follow [Semantic Versioning](https://semver.org/spec/v2.0.0.html):

- **MAJOR** — a change that breaks existing track files, log file formats,
  the BLE command protocol, or removes a user-visible mode.
- **MINOR** — new features or device behavior that is backwards compatible.
- **PATCH** — bug fixes and internal changes with no user-visible behavior change.

## [Unreleased]

## [4.1.0] - 2026-08-24

MINOR — new settings and device behaviour, backwards compatible with the
caveats below. Track files, the log filenames and the BLE command protocol
are unchanged from 4.0.0, so existing tracks, cards and companion apps
keep working. Two things do change:

- **Stock DOVEX logs drop the three always-`nan` temperature columns** —
  `Temp1`/`Junction1`/`Temp2` are now written only on SensorEgg builds, so
  a stock data row has 13 columns instead of 16. Readers key the data
  section off its own CSV header line, where all three are optional, so
  4.0.0 and 4.1.0 logs both load — but anything that assumed a fixed
  16-column row needs to read the header.
- **RPM changes on any device with `cylinder_count` set above 1** — the
  reading was wrongly divided by the cylinder count and no longer is (see
  Fixed). Devices left at the default of 1 are byte-identical.

> ### Read this before updating
>
> **This release permanently converts the two NFC pads to GPIO, on every
> device, and reboots once while doing it.**
>
> The LED strip stops being a beta-only experiment in 4.1.0 and ships in the
> normal firmware, so a logger lights up the moment someone wires a strip to
> it — no special build. Making those two pads usable as GPIO means writing
> the chip's UICR, and **that write cannot be undone by any later firmware**;
> reversing it needs a full chip erase and a bootloader reflash over USB.
> Your logger does the write the first time it boots after updating, then
> resets itself once so the change takes effect. That single extra reboot
> during the update is expected — nothing is wrong.
>
> This happens whether or not you have LEDs attached, because the firmware
> cannot know. The trade was made deliberately: this hardware does not use
> NFC for anything, the pads are otherwise idle, and requiring a separate
> build to use a headline feature had kept it out of everyone's hands. If you
> have some future use for the NFC pads on your device, **do not install
> 4.1.0.**
>
> With no strip wired, nothing else changes — the pins simply sit there.

The SensorEgg wireless-EGT proof of concept remains beta-only
(`BIRDSEYE_ENABLE_SENSOREGG`, off in the published images), and the new
main-loop CPU profiler is likewise a beta-channel diagnostic
(`BIRDSEYE_ENABLE_PROFILING`, also off in the published images). Everything
else below is live for every user.

### Added
- **NeoPixel LED strip subsystem** (plan 0006) — **now in every build**,
  see the upgrade note above: 11 WS2812 pixels on the NFC
  pads converted to GPIO — 2 status indicators + a 9-px strip with a
  centerline. A global brightness cap (`led_brightness` setting, 0
  disables the LEDs entirely) that no LED can ever exceed; a pace pip
  strip mode (left of center red = slower than best, right green =
  faster) with an RPM scale (green filling to red past halfway toward
  the new `target_rpm` setting) until pace is meaningful; two
  user-assignable status LEDs (see the status-modes entry below); a
  boot animation; and a purple celebration when a session-best sector is
  set. The strip's 5 V boost converter is enabled by its own pin, so
  sleep truly powers the LEDs off. **First boot of a flag-on build
  performs a one-way NFC-pads-to-GPIO conversion (UICR write) and
  resets once.**
- **Assignable LED status modes** — the two status pixels are no longer
  hardcoded. `led_status_left` and `led_status_right` each select one of
  eight modes from the companion app: **Off**, **Target RPM** (the old
  rev flasher), **Target speed**, **GPS** (red no sats / yellow sats but
  no fix / blue fix but no time lock / green locked), **Camera sync**
  (yellow session-running-camera-not-up / flashing blue linked but not
  subscribed / steady blue ready / red recording), **Last lap** and
  **Last sector** (green faster than the previous one, red slower, purple
  a session best), and **EGT** (SensorEgg builds only). The GPS and
  camera modes stay lit on the main menu — they answer "am I ready to
  drive", which is a paddock question. See
  `docs/plans/0013-led-status-modes.md`.
  - The lap and sector indicators compare against the **previous** lap or
    the same sector on the previous lap, deliberately not against the
    session best: a best-based indicator only ever answers purple or red
    and tells you nothing about whether you are improving. Nothing to
    compare against yet renders dark rather than guessing, so lap 1 is
    unlit.
- **A speed bar for sessions with no tachometer.** With the engine
  signal absent the 9-px bar used to sit dark until the first lap
  completed. It now scales against a new **`target_speed_mph`** setting
  (default 60 mph, stored in mph — the app converts for display) until
  pace timing takes over. The speed bar is green all the way up: the RPM
  bar's red band means "approaching the limiter", and there is no
  equivalent hazard in reaching a speed you were aiming for.
- **The purple celebration is now two-stage.** A session-best **sector**
  keeps the 1.6 s animation; a session-best **lap** gets a longer 2.6 s
  version with two wave passes, and outranks a sector celebration when
  both land on the same crossing.
- **LED day/night brightness + a device timezone** (plan 0010): new `utc_offset_min` setting (minutes east of UTC, default 0)
  gives the device a local wall clock, and the LED strip swaps to
  `led_brightness_night` (default 16) between `led_night_start_hour`
  (19) and `led_day_start_hour` (7) — local hours, so 7am is the
  driver's 7am rather than Greenwich's. Setting the two hours equal
  disables the swap. **No DST** — a fixed offset only. **Logged data is
  unchanged and still UTC**: DOVEX timestamps, the header datetime and
  every filename stay exactly as they were, and timezone presentation
  remains the viewing app's job.
- **Overrev alert** (plan 0007): new `overrev_limit` setting (default 0
  = disabled) — past it the whole LED chain flashes red and the tach
  page's `*OVER REV*` header trips, both until RPM falls back below the
  normal `target_rpm`. The target-RPM warning means the engine is at its
  ceiling; the overrev limit says it's broken.
- **Temp1 alert threshold setting** (`temp1_alert_c`, default 650 °C,
  SensorEgg builds only): the `egt` status-LED mode is a tri-state —
  flashing red at/above the limit, off when good, solid blue when there
  is no probe signal.
- **`tach_filter` setting** (default `smooth`, plan 0009): picks the RPM
  estimator, so the tach can be A/B'd against a live engine at the track
  instead of argued about from a plotted log. `smooth` is the new filter
  below; `legacy` is the pre-0009 one, bit for bit, for comparison
  against logs already collected; `raw` turns the estimator off entirely
  so the `rpm` column is exactly what the pickup delivers. Anything
  unrecognised reads as `smooth`.
- **Tach pickup-health line**: with `debug_pages` = `show`, the
  tachometer page's subtext becomes `max:NNNNN S rj:NN` — the estimator
  in force plus the number of inter-pulse periods the outlier gate has
  thrown away this power-cycle. A count that climbs with RPM is ignition
  ringing or missed sparks reaching the ISR, i.e. the pickup rather than
  the filter.
- **GPS-search pip**: in race mode without a full GPS lock the strip shows a green pixel bouncing end-to-end instead of the
  RPM scale, so a not-yet-timing session is visibly "searching".
- **Connection interval + PHY on the Bluetooth transfer page** — a second
  diagnostic line during a transfer (e.g. `15.0ms 2M`) alongside plan 0008's
  rate/SD/PDU/payload line. These are the two throughput levers the central
  decides and the device can only request: an interval of 30 ms instead of
  15 ms is a silent 2x on every download, and a link that ignored the 2M PHY
  request pays double airtime per packet. Live values, so a mid-transfer
  renegotiation shows up.
- **Main-loop CPU profiling (beta channel only)** — a new
  `BIRDSEYE_ENABLE_PROFILING` build flag, off in master and release, on
  in every beta build. It times each subsystem call in `loop()`, rolls
  the result up once a second onto a new **LOOP PROFILE** race page
  (loop rate, mean and worst iteration, and every section's share of the
  last second), and drives **pin 30** as a scope-readable profiling
  output. Groundwork for the nRF52840-vs-nRF5340 board decision and for
  judging what leaving the Arduino core would buy. See
  `docs/plans/0011-loop-cpu-profiling.md`.
  - Timing comes from the Cortex-M4 DWT cycle counter (64 ticks/µs)
    with a `micros()` fallback; the page flags the fallback with a
    leading `*` because at 1 µs resolution the small sections are noise.
  - The stats row shows the mean iteration in microseconds below a
    millisecond. The first hardware run read `999Hz av0.0` — both fields
    had been clamped against the ~250 Hz figure this project's docs had
    long assumed. See `docs/plans/0011-loop-cpu-profiling.md`.
  - **Rollup windows are closed on `millis()`, not on the cycle
    counter.** The DWT counter counts CPU cycles and stops when the core
    halts, so using it to time the window made a "one second" window one
    second of CPU-awake time — inflating the reported loop rate by the
    sleep factor and turning every share into a fraction of awake time
    wearing a wall-time label. All shares are now of real wall time.
  - New **`SLP`** slot on the page: wall time not spent inside `loop()`
    at all — scheduler dispatch, other FreeRTOS tasks and CPU sleep, i.e.
    the actual headroom. Its grid slot came from folding the boot-page
    state machines (`PGE`) into `DSP`. All fourteen slots are shares of
    the same second and sum to ~100%.
  - New host-tested pure unit `loop_profile` holds all the accounting.
  - **A beta image can no longer switch the 5 V LED boost rail.** Pin 30
    is the boost converter's EN line and the profiler takes it, so the
    regulator is left at its hardware default (on) and is never driven
    low — including at sleep, where the level is retained. A beta unit
    left asleep on a battery with a strip wired to it will drain it, and
    if the EN jumper is still connected the profiling toggles will chop
    the rail at loop rate. Bench builds only; prod images are unaffected.
  - On a profiling build the race rotation starts at the profile page,
    which also pulls the two diagnostic pages in regardless of the
    `debug_pages` setting.
- **The browser-sim harness can fake a GPS fix.** A "GPS fix" toggle (plus
  an mph field) streams a deterministic synthetic 25 Hz fix parked on the
  bundled OKC track's start line, so fix-gated flows — most usefully the
  on-device course creator, including its 3 s point-averaging hold — can be
  exercised in the simulator without loading a log file.

### Changed
- **Settings file and JSON document buffers raised 512 -> 1024 bytes**
  (plan 0010), and `setSetting()` now refuses a write it could not read
  back. The settings file was already 436 bytes at 18 keys against a
  511-byte read cap; the four new keys would have pushed it to 543,
  where the file parses as truncated, *every* setting read fails, and
  the boot-time corrupt-file heal quarantines and regenerates it on a
  loop — losing the device's BLE name, PIN and pairing every boot. Costs
  ~1 KB more RAM. **If you add settings keys, check the file size.**
- **RPM spikes are gone from the logged trace** (plan 0009). A plotted
  DOVEX `rpm` column showed spikes of thousands of RPM that the engine
  did not do. The filter was not over-smoothing — it was passing single
  bad edges straight through. Its steady-state gain was ~0.43 and a
  measurement is one inter-pulse period, so an ignition ring clearing the
  3 ms debounce at 3000 RPM reads as 15 000 RPM and moves the output
  ~5000 RPM; a missed spark does the same downward. Three fixes, all in
  the host-tested `tach_filter` unit:
  - An **outlier gate**: a measurement 5 sigma off the estimate is not
    folded in, the estimate coasts. Three *consecutive* rejections is a
    real step change (clutch dump, spin) rather than three coincident bad
    edges, and the third is adopted outright — so an instant
    11 000 → 4000 drop now settles in 80 ms, faster than before.
  - **Measurement noise that knows the RPM.** RPM = K/period, so a fixed
    timing error costs RPM^2/K of RPM error. The old flat noise figure was
    about right at 4000 RPM and far too confident above 8000 — the filter
    trusted its noisiest readings the most, which is why the trace got
    worse the harder the engine worked.
  - **Process noise per second, not per update.** Updates arrive at the
    pulse rate, so the old fixed per-update figure made the filter four
    times looser at 12 000 RPM than at 3000, and looser again whenever an
    SD stall batched several pulses together.
  Modelled over the whole pipeline on a dirty pickup, error against true
  RPM drops from 220–500 RPM standard deviation (worst case 2800–6400) to
  a flat ~20 RPM (worst case under 300) from 1500 to 14 000 RPM. The cost
  is ~90 ms more lag on a 5500 RPM/s pull. Set `tach_filter` to `legacy`
  to get the old behaviour back.
- **Engine dies mid-session** (tach-proven sessions): the pace page shows
  `STOPPED` instead of a still-counting pace, and the LED bar goes dark
  while the status LEDs (temp alert) stay live. Clears on restart.
- **Tach page `*OVER REV*` header** now means actual overrev: it shows
  only when `overrev_limit` is enabled and RPM reaches it (was a
  hardcoded 9999 RPM). The `rev_limit` warning stays on the LED only.
- **Temp status LED flashes red** (was orange), matching the rev
  flasher's alert language.
- **Bluetooth downloads are faster, and now say why when they are not**
  (plan 0008). A 3.3 MB session downloading at 28.8 KB/s on an iPad
  prompted a look at the whole transfer path. Three things were capping
  it, all fixed:
  - The link asks for a bigger link-layer packet (Data Length Extension)
    on connect, but that request can be rejected outright if it collides
    with the 2M PHY request fired a line earlier — and nothing checked or
    retried. An un-extended link splits every notification into ten
    packets. The device now reads back what actually negotiated half a
    second after connecting and re-asks if it did not take.
  - The device asked for a 7.5 ms connection interval, which **iOS is
    required to reject** (Apple's accessory rules set a 15 ms floor),
    leaving the connection on whatever iOS picked — commonly 30 ms, so
    half the transfer opportunities. The device now notices it is slower
    than 15 ms and makes a second request iOS is allowed to accept.
    Centrals already running faster than 15 ms are left alone.
  - Each chunk was read off the SD card immediately before being sent, so
    every packet waited on a disk read and the card was driven in
    244-byte pieces rather than whole sectors. Transfers now read 4 KB
    ahead and send out of memory.
- **The Bluetooth page shows live transfer speed** in KB/s alongside the
  percentage, plus the SD clock, link packet size and payload size in
  force. The old display was a percentage and nothing else, which is why
  a 4x slowdown took a full session to spot. The SD figure is the clock
  actually running, not the one requested — the 8 MHz transfer speed-up
  falls back to 2 MHz if the card refuses it, and that fallback used to
  be silent.
- **`cylinder_count` means the engine's actual cylinder count.** It was
  documented as "cylinders the **pickup sees**", which asked a V8 owner
  to enter `1` in a field labelled Cylinders — a trap that produced wrong
  RPM for anyone who read it literally. It is now descriptive: enter what
  the engine has. Nothing in the RPM path reads it. Above 1 it drives a
  warning, in the settings UI and in the docs, that crank speed is
  **inferred from one cylinder's ignition pulses** — between firings the
  reading is an assumption and a cylinder that drops out reads as a
  stopped engine, which is the known and accepted behaviour of every
  clamp-on inductive tach. No settings-file migration: same keys, same
  defaults, same size.
- **`rev_limit` is now `target_rpm`.** It always was the shift/warning
  point — `overrev_limit` is the real limit — and the old name taught
  the wrong thing to everyone who opened `/SETTINGS.json`. The old key
  only ever shipped on the beta channel during this cycle; a device
  carrying it migrates on first boot — the value is copied into the new
  key, which is confirmed written before the old key is dropped. No user
  action needed, and a tuned value is never lost.
- **The DOVEX `Temp1` / `Junction1` / `Temp2` columns are now written
  only on SensorEgg builds.** Until now they were written on every
  channel, as the literal `nan` on a stock image, so the log shape never
  forked. Stock logs are now 13 data columns and SensorEgg logs 16.
  Readers key the data section off its own CSV header line, where all
  three are optional, so both shapes load — but anything that assumed a
  fixed 16-column row needs to read the header. The `temp1_alert_c`
  setting is likewise SensorEgg-only now.
- The right status LED's default is **EGT** on a SensorEgg build (what it
  did before) and **Last lap** on a stock one.

### Fixed
- **The Bluetooth settings list works again.** Asking the device to
  enumerate its settings (`SLIST` — what the companion app's settings
  screen does) answered a parse error and listed nothing. The nine keys
  added this release took `/SETTINGS.json` from 329 to 538 bytes, and while
  the settings module's own reader was raised to 1024 bytes to suit, a
  *second* copy of that reader inside the Bluetooth code was left at 512 —
  so it read 511 bytes of a 538-byte file and gave up on the truncated
  result. Both are now sized by one shared constant, so they cannot drift
  apart again. Reading and writing individual settings was never affected.
- **A blank or corrupt `led_brightness` no longer looks like dead
  hardware.** Every numeric setting was read with a parser that answers
  "0" for an empty or non-numeric value, and 0 is a real, meaningful
  setting for most of the new keys — for `led_brightness` it means *LEDs
  off, and never even power up the 5 V rail*. A garbled value therefore
  switched the strip off silently instead of falling back to the default,
  as the code always claimed it did. Values are now parsed strictly:
  anything that is not a whole number is rejected and the default stands.
  A deliberate `0` still works exactly as before.
- **The overrev alert no longer strobes when the two RPM limits are set
  close together.** `rev_limit` and `overrev_limit` are validated
  independently, so nothing stopped you setting the overrev limit at or
  below the rev limit. Doing so inverted the alert's release point,
  and the whole LED chain flickered at the frame rate instead of flashing.
- **`STOPPED` on the pace page is no longer cut off.** At the size the page
  draws it, the text needed 144 pixels of a 128-pixel screen, so the final
  letter was clipped on every render.
- **A build with the LED subsystem compiled out now still powers the LED
  rail down.** Such a build does nothing with the LED pins by design — but
  on a board whose pads an earlier LED-enabled build had already converted,
  "nothing" left the boost converter's enable pin undriven, so the 5 V rail
  could stay up through shutdown and drain the battery of a device with no
  power switch. It now holds that pin low, but *only* on a board that has
  already been converted; hardware that never ran an LED-enabled build is
  still never touched. (No shipped 4.1.0 image is built this way — the LED
  subsystem is in all of them — so this protects custom builds and anyone
  rolling one back.)
- **Four menus you could get into but not out of now have a Back/Cancel
  row.** The transfer menu (Bluetooth / USB), the replay session browser,
  and the course creator's first two screens (track prompt, course type)
  offered only forward choices. None of them is the main menu, and the
  idle-shutdown timer only runs there, so none of them timed out either —
  opening one by mistake left the Select + side-button 5 s reboot combo,
  which is not labelled anywhere, as the only way out. Specifically:
  Transfer gains **Back**; the session browser gains a **Back** row after
  the last session (it scrolls into view like any other row); and the
  course creator's track prompt and type picker each gain **Cancel**,
  matching the Cancel/Back every screen deeper in that flow already had.
  The type picker's matters most — entering the creator with no known
  track nearby skips the prompt and lands there, so it was the first
  screen those users saw.
- **Cancelling manual camera-serial entry returns to the camera page.**
  It dropped to the main menu while OK returned to the camera page, so
  backing out of a mistyped character threw you two levels out and made
  the retry a fresh trip through the menu.
- **Exiting USB transfer mode no longer risks a hang + watchdog reset.**
  Leaving the USB drive page (Exit button or cable pull) could wedge the
  device for ~4 seconds and come back via the watchdog instead of the clean
  reboot: the exit path stopped accepting *new* host commands but a
  read/write already in flight kept driving the SD card from the USB task
  while the exit synced the card from the main loop — two tasks on the SPI
  bus at once. The exit now detaches USB first (so host traffic actually
  stops), waits out any callback still running — reads included, which were
  never tracked before — and only then syncs and reboots. The wait is
  watchdog-fed and sized to survive the SD card's own garbage-collection
  stalls.
- **Exiting Bluetooth transfer mode with the button now reboots the device.**
  Only a phone disconnect triggered the auto-reboot; pressing Exit on the
  device dropped back to the menu with any settings changed over Bluetooth
  not yet applied (they only take effect on boot). Both ways out of transfer
  mode — manual exit and peer disconnect — now reboot, matching how USB
  transfer mode has always exited.
- **Browser-sim harness plays 4.0.0 logs again.** The wasm test harness
  filtered DOVEX rows to exactly 13 columns, so logs from 4.0.0 firmware
  (16 columns after the `Temp1`/`Junction1`/`Temp2` additions) injected
  nothing. It now accepts 13+ and reads the stable first 13.
- **RPM on multi-cylinder engines — the cylinder count no longer divides
  it.** Since 4.0.0 the tachometer computed
  `pulses_per_rev = cylinder_count × spark_factor`, which is only correct
  for a pickup clamped on a shared coil or distributor king lead. This
  device has one sense wire and one clamp, and it goes around **one spark
  plug wire** — so it sees one cylinder's ignition however many the engine
  has, and the cylinder term divided RPM by that count. A V8 on a
  traditional magneto, configured honestly as 8 cylinders + single fire,
  read **an eighth** of its real crank speed. RPM is now
  `revs_per_pulse = spark_mode == wasted ? 1.0 : 2.0` — the spark mode
  alone. See `docs/plans/0014-tach-rpm-single-pickup.md`.
  - **BREAKING for anyone who set `cylinder_count` above 1**: their RPM
    changes, because it stops being divided. Logs recorded before this
    release read low by exactly the configured cylinder count. Devices
    left at the default (1 cylinder) are byte-identical.
  - The ISR debounce loses the same term — one wire can't deliver pulses
    faster than the cylinder it wraps fires — so it returns to a flat
    3 ms (6 ms for single-fire) and the ~20 000 RPM ceiling is now
    identical in both spark modes instead of falling with each configured
    cylinder.
- **The right status LED no longer sits solid blue for an entire race on
  a logger without SensorEgg support.** The pixel was hardwired to the
  Temp1 tri-state, whose "no probe signal" state is a solid blue — and on
  a stock build the reading is permanently unavailable, so every shipped
  logger with LEDs fitted showed it from lights-out to chequered flag. A
  build with no probe now renders that mode dark, because there is no
  signal there to be missing.
- **BLE download throughput on SensorEgg (beta) builds** — the SensorEgg
  passive scanner (44% radio duty) ran from boot forever, including through
  every Bluetooth file transfer, where it denied the link's connection-event
  extension and throttled downloads to ~33 KB/s against a 120+ KB/s
  baseline. The scanner is now **race-gated**: it starts when a race session
  begins and stops when the session ends, so the menu, replay, and transfer
  mode never share the radio with a scan window. `BLE_SETUP()` additionally
  quiesces it explicitly so a transfer session carries a guarantee rather
  than an inference. EGT data is unaffected — the Temp pages and the DOVEX
  `Temp1`/`Junction1`/`Temp2` columns are race-only consumers. See
  `docs/plans/0012-download-throughput-regression-deepdive.md`.

## [4.0.0] - 2026-08-10

### Added
- **The camera now works without a tachometer.** Auto-record used to be
  driven entirely by engine RPM, so on a device with no tach pickup a paired
  Insta360 never woke up. Now a race session started from the menu, or by the
  speed trip, drives the camera itself: it wakes at session start and begins
  recording a few seconds after it connects. These sessions end — data
  logging and camera recording together — after **5 minutes below 5 mph**
  (previously the data log ended alone after 60 seconds below 2 mph).
  Tach-equipped devices are unchanged: RPM still runs the whole show,
  including the 30-second engine-off stop — any session on a tach kart
  (menu press, speed trip, push/bump start) is handed to the RPM rules the
  moment real ignition is counted.
- **The diagnostic pages are hidden by default.** The two pages at the front
  of the race rotation (GPS/RF debug counters, and the battery/sats/SD stats
  page) are developer tools, and a new **Debug Pages** setting (editable over
  Bluetooth) now controls them. Out of the box the rotation starts at the
  speed page — a driver only ever sees speed, RPM, and lap pages. Set
  `debug_pages` to `show` to put the diagnostics back. **Note this is a
  behaviour change**: existing devices hide the pages after updating until
  the setting is flipped.
- **A full sprint track can now make room for one more run** (plan 0005).
  A sprint venue re-lays its course every event, so walked courses pile up in
  one track file — and once that file is bigger than the logger can read, the
  track stops being detected at the venue altogether. Until now, walking a
  course onto a full track simply lost it: the screen said `track file full`
  and there was nothing to do about it without a laptop.
  The logger now offers to drop the oldest runs and save. It picks what to drop
  carefully:
  - **Courses you renamed in the app go first**, even if they're the newest —
    a renamed course exists in the app too, so dropping it from the card loses
    nothing. Those are dropped without asking.
  - **A run still carrying the name the logger gave it** (`N260803_1432`) may
    exist nowhere else, so you're asked before it goes.
  - Oldest first within each group.
  Circuit tracks are unaffected: their layouts are all still driven, so there's
  nothing safe to drop and a full one still just says so.
- **The screen can be inverted.** A new **Display Colours** setting, editable
  over Bluetooth, switches the panel between the white-on-black it has always
  used and black-on-lit. Useful in direct sun, where a mostly-dark screen is
  the harder one to read. The default is unchanged, so nothing looks different
  until you ask for it.
- **RPM is now correct on engines that aren't single-cylinder karts**
  (plan 0003). The pickup counts ignition sparks, and the logger treated one
  spark as one revolution — true only for a 2-stroke, or a 4-stroke with
  wasted spark, running one cylinder. On anything else RPM was out by a fixed
  factor: a twin firing every revolution read **double** the real speed.
  Two new settings fix it, editable over Bluetooth:
  - **Spark Mode** — `wasted` (one spark per revolution: 2-stroke, or
    4-stroke wasted spark) or `single` (4-stroke single-fire, one spark per
    two revolutions).
  - **Cylinders** — the cylinders the **pickup can see**, which is not always
    the engine's. A clamp around one plug wire of a twin sees one, so that
    stays at 1; only a shared coil or all-cylinder harness sees them all.
  - The defaults reproduce the old behaviour exactly, so a logger you never
    configure reads identically to before.
  - Knock-on benefit: the RPM thresholds the device acts on — auto-race entry,
    and the camera's wake / start-recording / stop triggers — now mean what
    they say on every engine, instead of firing at half the real RPM on a twin.
  - The ignition-noise debounce follows the setting too, so the higher spark
    rate of a multi-cylinder engine doesn't run into it and read low.

- **Create a course on the device — walk the cones, no laptop** (plan 0002
  §5). New **Create** entry on the main menu: pick the track you're at (or
  start a new one), pick Circuit or Sprint, then capture each timing line by
  standing at the cone and holding for three seconds. Autocross venues
  re-lay their course every event, so this is what makes a sprint course
  authorable at the event instead of the night before on a computer. Circuit
  courses work the same way, with one fewer line to walk.
  - **Points are averaged, not snapshotted.** "Save current pos" collects
    fixes for three seconds — around 75 of them at 25 Hz — and stores the
    mean. You're standing at the cone anyway, so the accuracy is free. Loose
    fixes are dropped, and a hold that can't gather enough usable ones says
    so and asks you to try again rather than quietly writing a bad line.
  - **No typing on the device.** Names are generated from the GPS clock
    (`N260803_1432`, unique to the minute) and are meant to be renamed in
    the web app afterwards — which is also why the whole name fits the
    track browser instead of being cut off.
  - **Save is refused, with the reason, until the course is actually
    usable**: a start line always, a finish line for sprint, and the sector
    rules the web app's editor enforces — so a course written here can
    always be opened and edited there later.
  - **Back is a real undo.** Re-walk one endpoint of a line and change your
    mind, and the stored line is untouched.
  - Adding a course to an existing track rewrites the file through a temp
    copy, so losing power mid-save can't leave a broken track file behind.
  - Needs a GPS fix and time lock, and says so up front rather than at the
    end of a walked course.
- **BLE sprint-track sync — `TSLIST` / `TSGET:` / `TSPUT:` / `TSDEL:`**
  (plan 0002). The four existing track verbs gained `TS`-prefixed twins that
  target `/TRACKS/SPRINT` instead of `/TRACKS`, so sprint courses can be
  pushed and pulled over Bluetooth like circuit tracks — previously the new
  folder was only reachable by USB mass storage. `TSLIST` answers with its
  own `TSFILE:` / `TSEND` tokens so a sprint enumeration can never be mistaken
  for a circuit one; the other three reuse the existing replies. The variants
  share the circuit implementations via a `kind` parameter rather than
  duplicating handlers, and the filename validator stays strict — the target
  folder is chosen by the opcode and never parsed from the wire, so a client
  still cannot path out of the tracks folders.

- **Sprint mode (plan 0002) — point-to-point run timing for autocross /
  hillclimb events** (backwards compatible — MINOR). Sprint tracks live in
  the new `/TRACKS/SPRINT/` SD folder (circuit tracks are untouched); the
  detected track's folder selects the mode automatically. A sprint course
  is a start line + a separate `finish_*` line (+ up to two optional
  sector lines) with a sortable `date_created` stamp — the newest course
  is always loaded (autocross venues re-lay the course every event; the
  host-tested `sprint_select` unit owns the ordering + tiebreak rules).
  Runs are timed by the DovesLapTimer library's new `SprintTimer` (BETA):
  re-crossing the start cancels + restarts a run, finish crossings with no
  active run are ignored, DNF records nothing. Between runs the device
  stays in race mode with every page live — Current Lap and Pace show
  `*waiting*` — and auto-idle becomes engine-aware in sprint (a running
  engine at the start line never ends the session; each completed run
  re-arms the grace period). Run times land in the existing lap history /
  DOVEX laps line ("laps" verbiage is kept everywhere by design).
- **New `race_mode` setting** (`circuit` default / `sprint`): ONLY the
  tiebreak when both a circuit and a sprint track are within detection
  range — `circuit` yields to a sprint track whose newest course was
  created today (event day); `sprint` always prefers the sprint track
  (fixed layouts, e.g. a permanent rally course). Never overrides what is
  actually detected.
- **DOVEX `race_mode` trailing header column** (`CIRCUIT`/`SPRINT`, empty
  = circuit; same backwards-compatible append mechanism as
  `device_name`): a loading helper so the webapp knows to interpret the
  laps line as runs. Also fixed the header parser to preserve empty
  middle fields — the old strtok splitter let a blank column shift every
  later column left.
- **SensorEgg PW-ADV v2 support** (backwards compatible — MINOR). The
  passive observer now accepts the egg's 16-byte v2 payload alongside v1:
  a new aux intake-air thermistor (`Temp2`) and a real battery percent.
  v1 eggs keep working (their `Temp2` parses as `nan`); a v2 frame
  truncated below 16 bytes is rejected as corrupt rather than mis-read
  as v1. The RX path previously truncated captures at 14 bytes — v2
  bytes never reached the parser — and now captures up to the largest
  known layout with per-slot lengths.
- **`Temp2` race page**: second temperature page after Temp1, same
  layout and staleness rules ('---' on stale/v1/invalid), with the egg's
  battery percent as the subtext (`--` when unknown). Beta channel only,
  like the rest of the SensorEgg POC.
- **DOVEX `Temp2` trailing column** (backwards compatible append, same
  mechanism as `device_name` and `Temp1`/`Junction1`): aux intake-air
  temp in °C, literal `nan` on stale link / v1 egg / invalid divider.
  Never causes a GPS row to be skipped; written on every build so the
  format does not fork by channel.

### Changed
- **CI/production builds pass `-DDOVES_DISABLE_DEBUG`** (new DovesLapTimer
  BETA flag): the library's debug strings + print call-sites are dead
  weight on hardware builds (no debug Stream is ever attached) and the
  beta image had crossed 100% of the 320 KB OTA self-flash cap — it was
  already at 98.2% before sprint mode. Dropping the resident debug pipeline
  brings the image back under the cap with headroom instead of moving the
  OTA staging layout. Local IDE debug builds are unaffected (the macro is
  opt-in per build).
- The scan-tuning test's pinned egg advertising interval was stale at
  160 units; the egg de-aliased to 179 units (111.875 ms) — pin updated
  (anti-phase-lock invariants still hold).

### Fixed
- **A corrupted settings file now heals itself instead of poisoning the
  device forever.** A hand-edited `SETTINGS.json` with a typo (or any
  unparseable content) used to make every setting read and write fail
  silently for good — camera pairing gone, names lost — with no on-device
  recovery. The logger now quarantines the bad file to `SETTINGS.json.bad`
  (kept for inspection; an older `.bad` is overwritten) and regenerates a
  fresh default file, at boot and on the first write that hits the
  corruption.
- **A Bluetooth file download can no longer arrive silently corrupted.** If a
  notification stalled for more than a moment (phone screen off, radio
  congestion), the logger dropped that chunk and carried on with the next one
  — the received file ended shorter than promised with no error. The unsent
  chunk is now rewound and resent.
- **Listing a card full of logs no longer crash-reboots the logger
  mid-transfer.** The file listing walked the whole directory in one go and
  a season's worth of logs could outlast the hardware watchdog; it is now
  fed during the walk.
- **The screen now says so when logging dies mid-session.** An SD write
  failure stops logging for the session (the race deliberately continues) —
  but with the diagnostics hidden by default nothing on screen showed it, so
  a bad card could silently cost a whole day's data. The speed page shows a
  `NO LOG` corner flag and the tach page a `** NOT LOGGING **` footer.
- **A dead SD card no longer drains the battery on the fault screen.** The
  FAULT page (card dead at boot, buttons disabled) had no idle timeout, so a
  sealed unit sat there flashing until the pack was flat. It now powers down
  after the same 5-minute idle as the menu.
- **The blue Bluetooth light no longer stays on after the device sleeps.**
  Sleep only tore the radio down when the *file-transfer* page had been used;
  a camera-owned Bluetooth link (or one still mid-disconnect) kept the
  connection LED driven straight into power-off — and the chip keeps pin
  states in that mode, so the light burned all night. Shutdown now quiesces
  the radio unconditionally and forces the LED off as the last step. On beta
  builds the SensorEgg scanner is also stopped at sleep (it previously ran
  through the entire charging park) and restarts on charging resume.
- **A track with many courses no longer disappears from the device.** Track
  files were read and parsed through a 4 KB budget, and a file past it was cut
  mid-JSON: the parse failed, no manifest entry was built, and the track
  silently stopped being detected at the venue — not just losing its extra
  courses, but vanishing entirely. Sprint tracks hit this first, since a sprint
  course carries a finish line plus splits (~528 bytes each) and a venue accrues
  a dated course per event: **eight courses was enough**, below the ten the
  device claims to support. The budget is now 8 KB, which clears ten courses of
  every shape with headroom, and the BLE upload buffer is sized from the same
  constant so the largest track the device can read is also the largest it will
  accept. Costs RAM only (there was 167 KB free), no flash. This raises the
  ceiling rather than removing it — a truncated read now also says so on the
  debug serial instead of failing silently.
- **The crossing animation no longer paints over menus and setup screens.**
  The flag animation shown while the vehicle is inside a timing-line zone was
  gated by a list of pages to *skip*, and that list never grew as pages were
  added — so every screen introduced since got the animation drawn straight
  over it whenever the lap timer said "in the zone". Standing still beside a
  timing line is exactly when you are using those screens, so the camera
  pages, replay browser, transfer menus, the main menu and the course creator
  could all be interrupted by it. It is now shown only on the live racing
  pages, which is the only place it ever meant anything.
- **Leaving a page while moving no longer throws you straight into race
  mode.** Auto-race fires from the main menu above 500 RPM or 10 mph — but it
  was checked the instant the menu appeared, so exiting any page while rolling
  landed on the menu and entered race mode on the very next loop pass, about
  four milliseconds later. The menu was never drawn; from the driver's seat
  the device just did something on its own. Auto-race now waits for the menu
  to have been **settled for three seconds** — nothing arriving, no buttons
  pressed — which also stops it firing while you are actively navigating the
  menu at speed. The ordinary case is untouched: a device parked on the menu
  has been quiet for minutes before you drive off.
- **The GPS status page no longer reads as though a good fix is a bad one.**
  Once a position fix came up, the page said `FIX (time sync)` — which parses
  as a *kind* of fix (a time-only, position-less one) rather than what it
  actually meant: position is good, the clock isn't ready yet. A perfectly
  healthy device looked broken, and the natural response — power-cycling —
  restarts the very countdown being waited on. It now reads `FIX ok  UTC..`,
  and a new line says which milestone is outstanding: `UTC: no date/time`
  while the module has neither, `UTC: resolving <=12m` once it has the date
  and time but not the fully-resolved UTC. That second one is the slow, normal
  case — the receiver has to decode the leap-second parameters out of the GPS
  navigation message, which only repeats every ~12.5 minutes, so a clean fix
  in under a minute followed by several more minutes of waiting is expected,
  not a fault. Weak signal makes it worse: tracking a satellite well enough to
  range off it is a far lower bar than decoding its data bits cleanly.
  - The constellation readout (`Mode:GPS-only`) still occupies that line once
    the clock is locked, so nothing was lost — the diagnostic only takes the
    space while there is something to diagnose.

- **Battery sleep instantly reboot-looped when the tach line idles low.**
  System OFF entry hardcoded the tach wake as `SENSE-LOW` (assuming an
  idle-high line), but the pickup circuit's Schmitt-inverter +
  optocoupler output stage can idle low — DETECT was satisfied the
  moment System OFF was entered and the device reset within a second
  (USB-powered sleep was unaffected: a cable parks in the charging loop
  and never enters System OFF). Runtime RPM counting can't expose the
  polarity — a spark pulse yields one falling edge either way. Shutdown
  now samples the parked tach line (15 reads over ~30 ms, majority vote
  in the host-tested `wake_cause::tachIdleIsHigh()`) and arms SENSE for
  the opposite level; ties/floating inputs keep the original SENSE-LOW.
- **`isnan()` was compiled out of egg paths by `-Ofast`** (the platform
  builds sketches with `-ffinite-math-only`, which constant-folds
  `isnan()` to false). The Temp1 race page rendered `lroundf(NaN)`
  garbage (`-214748`) instead of `---` on a stale link; the DOVEX temp
  columns survived only because `dtostrf(NaN)` happens to emit a string
  the numeric guard rejects into the same `nan` fallback. Egg paths now
  use `isNanF()` (bit-pattern check, `nan_bits.h`) which the optimizer
  cannot fold.

## [3.1.0] - 2026-08-03

Makes room. The self-flash OTA capped images at 320 KB, and the beta image
was at 99% of it — every new feature was fighting the cap. Splitting the
flash evenly raises the ceiling to 408 KiB with no change to how updating
works, so this release is purely "more headroom, same behavior". Nothing
user-facing moves.

**MINOR, not PATCH**: the device now accepts OTA images it would previously
have rejected with `FWERR:SIZE` — backwards-compatible new device behavior.

### Changed
- **OTA image cap raised 320 KiB → 408 KiB by splitting the flash evenly.**
  The app and the OTA staging region share one 820 KiB stretch, and both
  must be able to hold the image — the incoming one is staged up top, then
  copied down over the app — so the largest installable image is half that
  span. The split was lopsided: 320 KiB of staging against 500 KiB of app
  region, which capped OTA at 320 KiB while leaving ~180 KiB of app region
  that no legal image could ever reach. The staging base moves `0xA4000` →
  `0x8E000`, making it 408 KiB of staging against 412 KiB of app. Nothing
  about the apply sequence, the `FW*` protocol, or the CRC changes — only
  two constants, now backed by `static_assert`s for page alignment and
  app-region fit. **No companion-app change is needed**: the web client
  never enforced a cap of its own, it relies on the device's `FWERR:SIZE`.
  - Upgrading to this release is safe from any earlier build: the staging
    location is chosen at apply time from the *installed* firmware's
    constants, so a 3.0.x device stages at the old `0xA4000` and installs
    this one normally. The new app region also ends below that old staging
    base, so a new-layout image can never collide with an old device's
    staging area.
  - **Devices still on 3.0.x keep their own 320 KiB limit** until they take
    this release. A future build larger than 320 KiB cannot be sent to one
    over the air — it would answer `FWERR:SIZE` — and would have to go over
    USB via `FWDFU` → UF2 instead. CI now warns when a build crosses that
    line so the split is visible before release rather than in the field.
- **The crossing animation is generated, not stored — 2,048 B of flash
  reclaimed.** The two "calculating" frames shown while inside a crossing
  zone were hand-stored 1 KB PROGMEM bitmaps, but both were pure block
  patterns: eight 16x16 px cells on the odd row bands, the two frames
  offset by one cell. They are now emitted by the host-tested
  `crossing_pattern` unit and drawn with `fillRect()`. The output is
  proven byte-identical to the bitmaps it replaces —
  `crossing_pattern_test.cpp` pins the original 2 KB as goldens and
  rasterizes the generated rectangles against them, so what shows on the
  device is unchanged. The bird splash stays a real bitmap (it is actual
  artwork, not a pattern). Backported from the beta channel.

## [3.0.2] - 2026-08-03

Ships the **`FWDFU` pre-update**: a device on this build can always be
reflashed over a USB cable, whatever a future image weighs. That matters
because the self-flash OTA caps images at the 320 KB staging region and
the beta image is already at ~99% of it — the planned SD-staged rework
(plan 0004) removes that cap, and this release is the escape hatch that
makes migrating to it safe on sealed units.

### Added
- **`FWDFU` BLE command — reboot into UF2 mass-storage DFU** (additive;
  every existing command keeps its wire behaviour). Sends `FWDFU:OK`,
  then reboots into the stock
  Adafruit/Seeed bootloader's UF2 mode: the device shows up as a USB
  drive and flashing is a drag-and-drop of a `.uf2` file — no web app, no
  nRF Connect, **no OTA image-size cap** (the bootloader writes the app
  region directly; no staging). This is the "pre-update" for the planned
  SD-staged OTA rework: any device updated to a build carrying `FWDFU`
  has a permanent, size-unlimited update path over a USB cable. The
  bootloader itself is unchanged.

### Changed
- Companion web app references updated from HackTheTrack.net to
  [LapWingData.com](https://LapWingData.com) in the README and project
  docs (site rename; no firmware behavior change).

## [3.0.1] - 2026-07-26

### Added
- **Build flag `BIRDSEYE_ENABLE_ONBOARD_CHARGING` (`project.h`), default
  off in every channel.** The hardware now carries an external charging
  circuit — the XIAO's onboard BQ25100 tops out around 100 mA even with
  the HICHG fast-charge pin held, which is too slow to be useful. With the
  flag off the firmware never drives HICHG (the charge IC stays at its
  ~50 mA default and the external circuit owns the battery), and the USB
  charging UX built around that hold is compiled out: a VBUS wake boots
  normally instead of shortcutting to the charge screen, and the main menu
  is no longer pulled into the charging loop after 60 s of inactivity just
  because a cable is plugged in. Setting the flag to `1` restores the
  pre-3.0.1 behavior exactly.
- **Build flag `BIRDSEYE_ENABLE_SENSOREGG` (`project.h`), default off on
  master/release and on in the beta channel.** The wireless-EGT pod is
  still a proof of concept, so it now ships only where POCs belong. With
  the flag off, the passive BLE scanner and the Temp1 race page are
  compiled out and BLE returns to coming up lazily on first
  camera/transfer use instead of at boot (recovering the idle power the
  always-on core costs). `beta.yml` passes
  `-DBIRDSEYE_ENABLE_SENSOREGG=1`, and `compile-sketch.yml` does the same
  for pull requests targeting `BETA`, so the flag-on build is
  compile-checked on the PR rather than first failing at publish time.
- **Simulator oracle diagnostic replay modes.** `birdseye_sim_oracle
  --dovex-noheader <file>` replays a header-less DOVEX log (crashed /
  power-cut session) through the full pipeline, printing live page / race /
  track-detect / course / lap state instead of asserting against header
  laps. `--two-session <file> [break-minutes]` reproduces a whole track
  day — synthetic session 1, auto-idle session end, a parked break with
  deterministic GPS drift, then the real log as session 2 — validating the
  carried-over CourseManager against the log's own header laps (wired into
  CI as `sim_two_session_carryover`).
- **GPS pipeline drop instrumentation.** The ~0.9% dropped-PVT regression
  was invisible on-device (the only signal was the frame-rate readout).
  The GPS serial path now carries permanent lightweight counters: missing
  PVT frames vs the nav-rate expectation (window math in the new
  host-tested `gps_stats` pure unit), worst-case TIMER3 drain deferral in
  µs (hardware timer capture — measures SoftDevice radio-ISR pressure),
  the biggest single-fire drain burst vs the core UART ring capacity, and
  overflow event counts for both the core ring and the 4 KB GPS ring.
  Surfaced on the GPS debug page — now first in the race rotation — with
  a one-line `Drops / Ovf` summary on the GPS stats page. ISR cost is a
  few cycles per fire; ~50 B RAM.
- **SensorEgg wireless EGT (proof of concept).** The logger passively
  scans for the DovesSensorEgg — a wireless thermocouple pod that
  broadcasts EGT + cold-junction temperature in BLE advertising packets
  (protocol `PW-ADV-1`, 14-byte manufacturer data, ~10 Hz). Passive
  observer only: no SCAN_REQ, no connection, no GATT link to the egg, so
  the scanner cannot contend with the Insta360 X4 camera link for TX
  airtime. Pairing is a hardcoded MAC (`SENSOREGG_MAC` in `sensoregg.h`);
  the all-zeros default accepts any egg matching the payload magic (POC:
  exactly one egg exists). Payload parsing + staleness rules live in the
  host-tested `sensoregg_protocol` pure unit.
- **DOVEX columns `Temp1` / `Junction1`** (degC, appended after
  `accel_z`). A stale link (>1 s) or an egg-reported invalid probe logs
  the literal `nan` — a dropout is a visible gap, never a held flat line
  (which would be indistinguishable from real data). Old logs and readers
  are unaffected; the egg fields can never cause a GPS row to be skipped.
- **Temp1 race page** after the tachometer page: big EGT (degC), small
  cold-junction + `rf:` link-status subtext, `---` when the egg is
  silent, `*TC FAULT*` header when the egg reports an open/faulted probe.

### Changed
- **USB behavior with onboard charging disabled (i.e. by default).** A
  cable is now treated as a host/data connection rather than a charge
  session: plugging into a powered-off device boots it normally instead of
  landing straight on the charge screen, and the main menu keeps its full
  5-minute idle window while plugged in. Shutdown still parks in the
  charging loop while VBUS is present regardless of the flag — VBUS is an
  always-armed System OFF wake source on the nRF52840, so powering down
  with the cable in risks an immediate wake-reset loop. That park is a
  hardware constraint, not a charging feature.
- **DOVEX `Temp1` / `Junction1` are written on every build.** With the
  SensorEgg POC compiled out they log the literal `nan`, so logs from the
  master and beta channels have identical column layout.
- **GPS serial pipeline hardened against BLE radio load (dropped-PVT
  fix).** SoftDevice radio interrupts (SensorEgg scan windows, camera
  connection events) can defer the TIMER3 GPS drain; at 57600 baud the
  core's stock 64-byte Serial1 ring gave only ~1 ms of deferral slack
  before bytes were silently lost (~0.9% of 25 Hz PVT frames in the
  field). Two changes: the drain now runs every 5 ms instead of 10
  (`GPS_DRAIN_INTERVAL_US`), and the core ring is grown to 256 bytes via
  a required `-DSERIAL_BUFFER_SIZE=256` build flag (~44 ms of slack;
  +384 B RAM). `project.h` fails the compile with instructions if the
  flag is missing, so a stock IDE build can't silently reintroduce the
  bug — see CONTRIBUTING.md "Local build flags".
- **SensorEgg scan duty reduced 60% → 44% (dropped-PVT fix, part 2).**
  The scanner now listens 40 ms out of every 90 ms (was 60 of 100). The
  wider-than-spec 60 ms window existed to break adv/scan phase-lock, but
  that job moves to the off-100 ms interval: 90 ms scan vs the egg's
  ~100 ms advertising sweeps their relative phase ~10 ms per cycle, so a
  deaf-zone park escapes in under half a second — invisible at the 1 s
  staleness rule. Less radio time in SoftDevice scan windows means less
  deferral of the GPS drain ISR. Camera connection parameters are
  deliberately untouched (we're the peripheral; the X4 dictates the real
  interval, and the 10 Hz GPS heartbeat needs the short interval).
- **Camera recording requires 1500+ RPM sustained for 5 s.** The record
  start gate moved from the 500 RPM wake threshold to a dedicated
  `kRecordRpmThreshold` (1500), held continuously for the full 5 s delay —
  any dip below restarts the clock. Pull-start cranking registers real
  ignition pulses above 500 RPM, which could start a camera recording
  during a failed start; cranking cannot sustain 1500. Camera wake and the
  30 s engine-off stop keep the 500/300 hysteresis band.
- **PVT callback math moved off software doubles.** The nRF52840's FPU
  is single-precision; `double` is software-emulated. The 25 Hz PVT
  callback now computes altitude/speed/HDOP/heading/accuracy as `float`
  reciprocal multiplies (lat/lng stay `double` — 1e-7° needs the
  precision). No logged or displayed digit changes at the precisions
  used; the sim lap oracles reproduce the hardware fixture to the exact
  millisecond. Also deduplicated a triple `toDegMin()` call in the
  camera RMC builder (byte-identical output, golden-pinned).
- **SensorEgg temperatures display in Fahrenheit.** The Temp1 race page
  (big EGT + junction subtext) and the camera bench page's `egg:` soak
  readout now render in °F, converted at display time via the host-tested
  `sensoregg_protocol::celsiusToFahrenheit()`. DOVEX logging is unchanged
  (`Temp1`/`Junction1` stay Celsius). A C/F display setting will follow
  in a later release.
- **BLE core now starts at boot** (was lazy — first camera/transfer use)
  so the SensorEgg scanner is always listening. Idle power draw increases
  accordingly; GATT service registration order is unchanged.

### Fixed
- **Zombie SensorEgg no longer reads as a live link (field incident
  2026-07-19).** BLE radios rebroadcast the last advertising payload
  autonomously, so an egg whose application hangs keeps beaconing frozen
  data at 10 Hz — the logger showed `rf: OK` with a value that never
  updated, and would have logged a flat line indistinguishable from real
  data. The logger now watches the payload's sequence counter (the app's
  only sign of life, via the host-tested wrap-safe
  `sensoregg_protocol::SeqMonitor`): if packets arrive but the sequence
  hasn't advanced within 1 s, readings go NaN (`nan` in the log, `---` on
  the display) and the Temp1 page shows `rf:HUNG` — the egg needs a power
  cycle.
- **Menu idle shutdown ignored button activity.** The 5-minute main-menu
  idle timer read the buttons' `pressed` flags at a point in the loop where
  they are always false (set later by `readButtons()`, cleared by
  `resetButtons()` before the next iteration), so navigating the menu never
  reset the clock and the device powered off 5 minutes after menu entry
  regardless of activity. The timer now anchors on the button debouncer's
  persistent `lastPressed` stamps. Regression-tested by the new
  `--two-session` sim oracle mode in CI (the mid-break shutdown it used to
  cause kept session 2 from ever entering race mode).
- **Track detection silently degraded to Lap Anything when logging started
  first.** `SD_ACCESS_TRACK_PARSE` was denied while `SD_ACCESS_LOGGING`
  held the card — but logging holds it for the entire race session, so any
  boot where the log file was created before the 1 Hz track-detect parse
  (typical tach-wake with a warm GPS) lost course detection for the whole
  session. Track parse / settings reads now nest under the logging hold
  without taking ownership (`sd_access_policy::ownerAfterAcquire`) — they
  run on the same main-loop task with their own file handles, so the
  exclusion never protected anything. Policy change covered by host unit
  tests.
- **Pull-start / engine-kill lockup (field incident 2026-07-19).** A failed
  first start or killing the motor before GPS acquired its time lock left
  the device apparently frozen: pinned to the RPM page, all buttons dead,
  no watchdog reset. Root cause: the GPS-lock hold (which pins the UI while
  a race session waits for a lock to create its log file) latched on any
  tach pulse — pull-cord ignition blips included — and had no engine-off
  release, while its only automatic session-enders were blocked (3-minute
  auto-idle grace, and full auto-idle suppression once the camera was
  recording). Fixes: the hold now releases after 10 s of engine-off (the
  session stays active and navigable), the pinned tach page shows
  `WAITING GPS LOCK..` instead of pinning silently, and auto-idle may end
  a still-fileless session even while the camera records.
- **SensorEgg reception flapping** (1 s of readings, then 1–30 s of
  `NA`/`nan`, seen on the first bench soak). Three scanner fixes: an
  inline manufacturer-ID filter (`filterMSD(0xFFFF)`) so ambient BLE
  packets are rejected inside Bluefruit instead of pausing the scanner
  for a deferred-callback round trip each; a 60 ms scan window (was
  40 ms) plus an off-100 ms egg advertising interval so the equal
  100 ms adv/scan periods can no longer phase-lock the egg into the
  scanner's deaf zone for seconds at a time; and a 30 s self-heal that
  restarts a silently-halted scanner (a lost deferred rx callback
  otherwise kills scanning forever with no error).

## [3.0.0] - 2026-07-17

This release rolls up the entire BETA cycle since `2.2.3`: hands-free
Insta360 X4 camera auto-record, USB mass-storage transfer, a full nRF52
System OFF shutdown/wake redesign, a MyChron-style GPS status boot page,
on-device SD formatting for blank/soldered-in modules, per-device log
labeling, and a complete browser/WASM simulator built from the real
firmware — on top of the code-review hardening and CI supply-chain
pinning that were originally scoped for `2.3.0`. The version is bumped to
**3.0.0** because the sleep model changes to a full power-down, two
user-visible modes are removed (the Wokwi target; the sleep-time periodic
GPS fix), and the BLE file-command protocol adds `BUSY` back-pressure —
all breaking under this project's semver policy.

### Added
- **Insta360 X4 camera auto-record (remote emulation).** The device
  emulates the physical Insta360 GPS Remote as a pure BLE **peripheral**
  to drive an X4 hands-free. Engine start (RPM > 500 held 2 s) wakes a
  paired, powered-off camera with the remote's manufacturer-data
  advertisement carrying the camera's serial — byte-for-byte the genuine
  remote's payload, **X4-confirmed** (captured with nRF Connect and
  replayed to wake a sleeping X4; flags `0x05`, serial at mfg[14..19]).
  The camera connects back to *us* and subscribes to our `ce82` button
  characteristic, and **all** control rides `ce82` notifications exactly
  like the real remote: recording toggles via the shutter button (the FSM
  tracks record state so a mid-session reconnect never blind-toggles), and
  power-off streams the remote's 3-second power hold. Pairing captures the
  camera's 6-character serial (new `camera_serial` setting; manual-entry
  fallback) from the new main-menu **Camera** page, which also has a bench
  **Test** menu (*Wake / Record / Power Off*) with live `R:UP+` / `Adv`
  status. The single BLE peripheral slot is shared with the file-transfer
  service via an explicit `bleOwner`, so a camera link can never trigger
  the transfer auto-reboot; the link is Just-Works bonded; the FSM is a
  telemetry consumer (logs are byte-identical with the feature on or off,
  save the one deliberate 30 s-engine-off log-session end) and BLE comes
  up lazily, so unpaired users pay nothing. The in-camera GPS overlay
  rides the remote channel: a Wireshark capture of the genuine
  remote↔camera link revealed the remote streams GPS on `ce82` at **10 Hz**
  as a (non-standard, signed-longitude) NMEA-RMC frame — so the firmware
  now streams that continuously while the camera is connected (it doubles
  as the remote's liveness heartbeat; status `V` with no fix, never
  silent), golden-tested byte-for-byte against the capture. **GPS still
  logs to SD** exactly as before, independently. All lifecycle timing
  lives in a host-tested pure FSM; the frame bytes in a host-tested
  protocol unit with golden tests.
- **USB mass-storage file transfer.** The Transfer screen now opens a
  submenu offering **Bluetooth** (the existing BLE file-transfer flow,
  unchanged) or **USB**. Choosing USB presents the SD card to a connected
  computer as a standard drive (TinyUSB MSC) for drag-and-drop of track
  files and logs — no companion app required. The drive is opt-in: it only
  enumerates while on the USB page, so normal plug-in/charging is unchanged.
  Exiting USB mode reboots the device so the firmware remounts a clean
  filesystem after host edits. USB transfer holds the SD card exclusively
  via the access mutex (new `SD_ACCESS_USB_MSC` mode), so it cannot collide
  with logging, replay, or BLE.
- **Blank-module first-boot safety.** Aimed at soldered-in SD modules that
  can never be pre-loaded or reformatted on a PC. The `/TRACKS` folder is
  now created automatically when missing (at boot and before a BLE track
  upload) — previously every `TPUT` to a blank card failed with
  `TERR:WRITE_FAIL` until the card was hand-populated. And when the card
  responds but has no mountable FAT volume (factory-blank or corrupted
  filesystem), boot now lands on an **SD format page** instead of the
  dead-end FAULT screen: hold Select for 3 s (live countdown, release
  restarts the window) to format the card FAT16/32 on-device, after which
  the device reboots, mounts the fresh volume, and creates default
  settings — first boot then proceeds normally and tracks can be synced
  over Bluetooth. Five minutes idle on the page powers the device down;
  a dead/absent card still shows the FAULT page.
- **GPS status boot page (MyChron-style).** Every boot now lands on a
  satellite status page after the splash instead of the main menu: the
  top half shows used-in-solution/tracked satellite counts, HDOP, lock
  state, constellation mode and battery;
  the bottom half draws one vertical signal bar per satellite (height =
  carrier-to-noise, from UBX-NAV-SAT). During the page the GPS runs a
  5 Hz status config; leaving it switches to the 25 Hz PVT-only race
  config. The page **holds but never locks**: any button skips it
  immediately, and once a stable lock (position fix + fully-resolved
  time, held 3 s) is acquired it auto-advances. It exits to the main
  menu — or straight into race mode with logging when the engine-start
  (tach) wake booted the device or the engine is running. Five minutes
  with no lock and no engine activity powers the device back down. A GPS
  that fails to initialize is re-probed up to 3 times in the background
  and surfaced as `NOT DETECTED` / `CHECK WIRING` instead of failing
  silently.
- **`device_name` setting to label logs per device.** A new persistent
  setting identifies which unit produced a log — handy when dumping logs
  from a fleet. On first boot (or upgrade) a friendly default is generated
  by picking two of twelve racing-adjacent words at random (e.g.
  `ApexTurbo`); editable on a computer or over BLE like any other setting.
- **`device_name` recorded in the DOVEX header.** The session metadata line
  now carries the logging device's name as a new trailing column. The column
  is appended after `optimal_ms`, so older readers ignore it and the firmware
  reads pre-existing logs (no column) as an empty device name — fully
  backwards compatible with the reserved 1 KB header.
- **Simulator host build (`BirdsEye/sim/`, internal).** The real firmware
  sources now also compile and run on a desktop toolchain under the `SIM`
  flag — one concatenated translation unit against an Arduino/nRF52 shim,
  an in-memory SD card (fixed settings + example track baked in), a
  host-driven virtual clock, and the real DovesLapTimer/CourseManager
  library, with BLE/camera/USB/OTA stubbed out. A new `sim-build` CI
  workflow boots the firmware for 60 virtual seconds and verifies two
  runs are byte-identical, so the `SIM` flag can't silently rot. This is
  the foundation for the browser (WASM) simulator; no firmware behavior
  changes.
- **Simulator pixel-perfect display (internal, sim Phase 2).** The sim
  now renders through the REAL Adafruit display stack (GFX 1.12.6 →
  GrayOLED → SH110X 2.1.14, pinned) with the hardware boundary shimmed at
  the two BusIO device pointers — every framebuffer pixel comes from the
  real `drawPixel()`. Adds a zero-copy framebuffer getter + FNV-1a frame
  hash, a dependency-free PNG frame dumper, and 8 committed golden page
  fixtures (hash + expected page id, captured by walking the real menus)
  that CI verifies on every PR; rendered frames are uploaded as a CI
  artifact. No firmware behavior changes.
- **Simulator inputs + lap-timing oracle (internal, sim Phase 3).** The
  sim now drives the firmware at the same boundaries the hardware uses:
  GPS frames are injected as real `UBX_NAV_PVT_data_t` structs straight
  into `onPVTReceived()` (struct and JSON spellings), the tachometer is
  synthesized pulses through the real falling-edge ISR at exact virtual
  microseconds, and accelerometer traces ride the IMU shim. A CI oracle
  test streams a synthetic constant-speed OKC lap trace — lap period
  exact by construction — through the whole real pipeline (boot GPS
  page → auto race entry → track proximity detection → CourseDetector
  picking "Normal" → DovesLapTimer) and requires every lap within one
  GPS frame (40 ms; observed within 1 ms). The same driver's `--dovex`
  mode replays a hardware-recorded log against its own header lap list.
  The sim's bundled OKC track fixture is now the HackTheTrack object
  format (`courses[]`), so proximity detection and course ranking work.
- **Simulator hardware-session oracle (internal, sim Phase 3b).** A real
  device-recorded OKC session (`sim/fixtures/okc_tillotson_1.dovex`,
  13 laps) is now replayed through the sim in CI and the sim's
  DovesLapTimer must reproduce the lap list from the file's own header —
  it currently matches all 13 hardware lap times to the exact
  millisecond. This is the definitive same-code-same-answer check for
  the simulator's fidelity.
- **Simulator WASM build (internal, sim Phase 4).** The sim now compiles
  to a browser module (`emcmake`; Emscripten 3.1.61 pinned in CI):
  `birdseye-sim.mjs` (stable public wrapper) + `birdseye-sim-core.{mjs,
  wasm}` + `version.json` (firmware sha, DovesLapTimer sha, display-lib
  versions). Full API contract v1 in `BirdsEye/sim/API.md` — framebuffer
  view + FNV-1a hash, JSON PVT injection, RPM synthesis, state/version
  JSON, VFS readFile/listFiles, and a true-fresh-boot async `reset()`
  (module re-instantiation). A standalone `test.html` harness boots the
  firmware in a browser and replays real `.dovex` files; a node smoke
  test gates CI (`sim wasm build` job) and the dist folder is uploaded
  as the `birdseye-sim-wasm` artifact. The wasm module renders
  byte-identically to the native golden fixtures (same frame hashes).
  Artifacts are vendored into DovesDataViewer (`public/sim/`).
- **Simulator boot-sequence capture (internal, sim).** `sim_init()` now
  records deduplicated framebuffer keyframes (with virtual timestamps)
  at every in-`setup()` `delay()` boundary — the splash and boot pages
  that were previously invisible to the host because `setup()` runs as
  one call. Exposed as `getBootFrames()` in the wasm API (contract v1
  addition) so the viewer can play the real power-on sequence.

### Changed
- **Sleep is now a full shutdown (nRF52 System OFF).** Replacing the
  software sleep loop, the device tears everything down and powers off
  to µA-level System OFF; a tachometer pulse (engine start), any button,
  or plugging in USB wakes it with a fresh boot, making a power switch
  unnecessary. The engine-start wake boots through the GPS status page
  and auto-enters race mode; wake cause is decoded from the reset-reason
  and GPIO latch registers. **Charging is the one exception**: while USB
  power is present the device stays in a live charging loop (software
  holds the fast-charge pin) — screen on for 10 s then dark, any button
  fully wakes to the main menu, and unplugging powers off. USB connected
  on the main menu now enters the charging loop after 60 s of button
  inactivity (previously immediate sleep), so the device remains usable
  for replay/transfer while plugged in.
- **Camera auto-record is a simple, RPM-driven lifecycle.** Recording is
  not gated on a GPS lock and does not stop on a speed+engine combo
  with a cooldown/power-off tail. Instead: the engine starting wakes+connects
  the camera; ~5 s of sustained RPM starts recording (one shutter); 30 s of
  engine-off (RPM only — a stationary but running grid idle keeps rolling)
  stops recording (one shutter) **and** ends+saves the race log session,
  returning to the menu. The camera then enters a **watching** state — it
  stays on and connected, so a brief on-track stall recovers straight back
  into recording when RPM returns — and powers off only when the device
  sleeps. GPS still streams to the camera the whole time (voided RMC until a
  lock, real data after). While the camera is recording, the speed-based log
  auto-idle yields to it; with no camera paired, logging is unchanged.
- **SD SPI clock raised during file transfers.** While a BLE or USB
  mass-storage transfer is active the SD card is clocked at 8 MHz (4x the
  normal 2 MHz), reverting to 2 MHz afterward. Transfers only happen parked
  with the motor off, so the ignition-EMI rationale for the slow clock doesn't
  apply — this lifts the USB drag-and-drop ceiling from ~250 KB/s. Falls back
  to 2 MHz automatically if the fast re-init fails.
- **GPS boot connection hardening.** Boot now sends the u-blox
  backup-mode wake byte before probing (a module left in backup mode by
  the shutdown wakes correctly), probes the configured 57600 baud first
  (warm boots connect near-instantly; the old fixed 2.25 s boot delay is
  only paid when nothing answers), and validates that PVT data actually
  flows within 5 s of boot — recovering via the existing baud-recovery
  ladder if the module answered the probe but was silently misconfigured.
- **CI now controls which DovesLapTimer the firmware is built against.**
  Builds targeting (or running on) the `BETA` branch track the library's own
  `BETA` branch, so the two beta channels move together; `master` CI and the
  release/tag builds pin a known-good tag instead of floating on
  the library's default-branch tip. Bump the pin deliberately when a new
  library release is validated — this release moves that pin from `v4.1.0`
  to **`v4.2.0`**.
- **Simulator flag renamed: the old Wokwi define is now `SIM`** at every
  site, ahead of the browser/WASM simulator work. All conditional behavior
  carries over unchanged (bare-SdFat type, smaller JSON buffer, WDT skip, fixed battery
  voltage, plain-reset shutdown), except the dead Wokwi GPS setup branch
  (`myGNSS.begin(gpsStream)` at 19200), whose body is now a placeholder
  that just sets `gpsInitialized = true` — the simulator will inject PVT
  data via the real `onPVTReceived()` callback instead. `SIM` is never
  defined in normal firmware builds; no hardware behavior changes.
- **SIM builds now use the hardware's 4 KB track JSON buffer** (was a
  1 KB Wokwi-era carve-out inside `#ifdef SIM`). The smaller buffer
  silently truncated real track files, breaking track parsing in the
  simulator; hardware builds are byte-for-byte unaffected (always 4 KB).

### Removed
- **(Breaking) Wokwi simulator files** (`BirdsEye/diagram.json`,
  `BirdsEye/libraries.txt`) — they described a dead Wokwi/Arduino-Mega
  target with the wrong display (SSD1306 vs the shipped SH1106G) and the
  wrong GPS library (Adafruit NMEA vs SparkFun UBX). A WASM simulator
  built from the real firmware replaces them.
- **(Breaking) 24-hour periodic GPS fix during sleep** — nothing runs
  during System OFF to schedule it; the GPS warm-starts on wake instead.
- **RPM sleep-wake latch (`tachHavePeriod` / `TACH_SLEEP()`)** —
  superseded by the tach pin's GPIO SENSE wake from System OFF.

### Fixed
- **Boot hang on "Initializing..."** introduced by the GPS boot probe
  ladder: it called `Serial1.end()` before the port had ever been opened,
  and the nRF52 core's `Uart::end()` spin-waits on stop events a
  never-enabled UART can't produce — hanging `setup()` forever (before
  the watchdog is armed). Baud switches now go through a guard that only
  closes a port we actually opened.
- **Watchdog resets from the GPS status page** (device reboots a few
  seconds after boot): the GPS connection probes and the baud-recovery
  path could block past the ~4 s hardware watchdog. A failing
  `myGNSS.begin()` is 3 internal ping retries at the library's 1100 ms
  default (~3.3 s, un-pettable), and a recovery on a slow-responding
  module ran up to 11 back-to-back VALSET/ACK exchanges with no pets at
  all. All probes now use a 550 ms maxWait (halving worst-case blocking)
  and every blocking GPS exchange in the probe/recovery/reconfigure
  paths is bracketed by watchdog pets. The status page also shows an
  uptime readout so any remaining reboot can be timed against the GPS
  watchdog (5 s) and re-detect retry (10 s) schedules.
- **Camera record state is confirmed from the camera, not just believed.**
  The shutter is a stateful toggle, so a lost or mistimed frame used to
  *invert* our belief and stop a live recording (or start one in the paddock).
  A Wireshark capture of the genuine remote link showed the camera reports its
  state implicitly through its `0x10` display-string frame — a live
  `.HH:MM:SS` timer while recording, the mode/battery string when idle (the
  `0x02` status word is not reliable). The firmware now parses that timer and
  **reconciles** its record belief against it: on reconnect it adopts the
  camera's real state instead of blind-toggling, and if the camera reports
  idle while we think we're recording it re-asserts the shutter once. The
  belief is preserved (not cleared) whenever the camera is unreachable, so a
  dropped link mid-session can never invert on reconnect. The bench **Test**
  page gains a `rec:yes/no` state (the camera's own timer; `rec:--` when there
  is no fresh observation) and a `G:SYNC` / `G:V`
  GPS indicator so the link can be verified end-to-end. (Parser is golden-
  tested in the `insta360_protocol` unit; the reconcile in the `camera_fsm`
  unit.)
- **Camera powers off on sleep instead of running all night.** Entering
  sleep armed the streamed power-off hold and then immediately disconnected —
  but the loop parks on sleep, so the hold was never serviced and *zero*
  power-off frames were sent. Sleep entry now streams the hold synchronously
  (feeding the watchdog) before dropping the link.
- **A nearby paired camera no longer reboots the logger out of a transfer
  session.** The radio has one address, so a bonded X4 can connect to the
  transfer advert and get routed as "the phone"; its sub-second drop hit the
  transfer auto-reboot, kicking the user out of Bluetooth/USB transfer
  repeatedly. The reboot is now gated on the peer actually having used the
  file/settings/OTA service — a camera that only vets our GATT and leaves is
  ignored. Relatedly, exiting Bluetooth no longer leaves a stale transfer
  advert on air (`restartOnDisconnect` is disarmed before the teardown
  disconnect), which had let a phone reconnect into a mute session and
  blocked camera auto-record until a power cycle.
- **A camera that connects but never subscribes no longer loops forever.**
  The ce82 subscribe-timeout re-advertised without counting attempts, so a
  stale bond (encryption never comes up) span connect→timeout→re-advertise
  indefinitely. It is now bounded — after a few cycles the FSM gives up back
  to IDLE.
- **Camera Pair/Test menus scroll the right way.** The new pages render a
  static top-to-bottom list like the main menu, but weren't in the
  direction-reversal set, so the first "down" press wrapped to the last item
  (once landing on Unpair). They now move with the buttons.
- **ce82 subscription is cached off the hot loop.** The subscription check was
  a SoftDevice round-trip called ~500×/s (per loop + per GPS tick); it is now
  latched from the CCCD callback (with a low-rate re-read to catch a bonded
  peer's silent sys-attr restore), keeping the 25 Hz logging loop clear.
- **Camera Power Off streams the held-button frame — decoded from a
  live remote capture.** A genuine remote's ce82 traffic (nRF Connect,
  2026-07-10) showed two things we had wrong: the button frame's byte[4]
  is a running sequence counter the remote steps by 2 with every frame
  (we hardcoded `0x00`), and **power-off is a held button** — the remote
  streams the 3-second-hold frame continuously (fresh seq each) until the
  camera powers off, rather than sending one frame. We now stream the
  hold non-blockingly for ~3.5 s (or until the camera drops the link,
  which is it powering off), with a per-frame sequence counter. ce82 is
  also now NOTIFY-only, matching the captured remote's GATT. (The
  captured shutter/mode/power-tap frames confirm our other button byte
  patterns exactly.)
- **Camera Power Off no longer fails silently — ce82 sends honor the
  camera's subscription and report failures.** The power-off button frame
  was a fire-and-forget notify behind two invisible gates: it returned
  silently with no remote link, and a notification to a camera that never
  wrote the ce82 CCCD (or subscribed for *indications* rather than
  notifications) was discarded by the stack while the UI showed nothing.
  ce82 sends now pick notify vs indicate from the actual subscription,
  return a real result, and the bench-test menu shows *why* a Power Off
  failed ("run Connect first" / "camera not subscribed" / "rejected by
  stack"). The test page's R status gains a `+` when the camera has
  subscribed to buttons (`R:UP+` = deliverable; `R:UP` = connected but
  ignoring us), and ce82 CCCD writes are traced to serial for bench
  diagnosis.
- **Wake advert matched byte-for-byte to the genuine GPS Remote —
  X4-confirmed ground truth.** A real remote was captured with nRF
  Connect against the camera, and replaying its advertisement from a
  phone woke the sleeping X4 — making the packet authoritative rather
  than reference-derived. Our transmission differed by exactly one byte:
  the Flags AD is `0x05` (LE Limited Discoverable + BR/EDR Not
  Supported), not the `0x1A` inherited from the ESP32 replication. The
  scan response now also matches the real remote (Appearance 0x0180
  "remote control" + name — previously name only), and the paired
  camera-mode connectable advert is unified onto this same
  remote-identity packet (it is the only advert a genuine remote ever
  transmits, and what the camera's reconnect scan expects) — the
  invented name+service advert is now used only for the unpaired pairing
  flow, where no serial exists yet for the manufacturer block.
- **Camera wake advert was garbled on air by a BLE core bug — all adverts
  now transmit as fixed 31-byte packets.** Bluefruit 0.21.0 (the version
  in the Seeed board package; fixed upstream in Adafruit 1.7.0) freezes
  the advertising packet lengths at whatever the FIRST advert of the
  boot carried (`_start()` uses a function-local static), so any later
  advert of a different length went out truncated or with a stale tail —
  a malformed PDU every receiver silently discards while the API reports
  success. In practice: after the 28-byte connect advert ran once, the
  31-byte Insta360 wake advert lost its last 3 bytes on air and could
  never wake the camera. Every advert (transfer, camera wake, camera
  connectable) is now zero-padded to exactly 31+31 bytes (spec-legal)
  via a shared `bleAdvFinalizePadded()` before start, making the frozen
  length always correct. The wake path also skips (with a debug note)
  when the camera already holds the peripheral slot, instead of failing
  the connectable start with `NRF_ERROR_CONN_COUNT`. *Camera-side note
  from research:* on the X4, Bluetooth Wakeup is armed only when
  **QuickCapture is OFF** — with QuickCapture on, the powered-down
  camera's radio never scans and no beacon can wake it.
- **Camera R-link diagnosis + bench advert re-arm.** The camera has been
  observed connecting to the remote service intermittently — sometimes
  dropping faster than the display refresh, invisibly. R-link connects
  and disconnects (with the HCI reason code, which says who ended the
  link and why) are now traced to serial, and in the bench-test menu the
  connectable remote advert automatically re-arms whenever the R-link is
  down — the camera retries on its own schedule and could previously
  only reconnect if the tester pressed Connect at the right moment.
- **Main menu scrolls — the Camera entry is reachable again.** The 4-item
  main menu was drawn as four full-height rows filling the panel's nominal
  64 px exactly, and the last row (Camera) was cut off on real hardware.
  The menu now shows a 3-row window that follows the selection (same
  pattern as the replay file list) with a `v more` scroll hint on the
  spare bottom line.
- **USB mass-storage exit no longer risks truncating a host write.** Exiting
  USB mode syncs the card and reboots, but `setUnitReady(false)` only stops
  *new* SCSI commands — a `WRITE10` already in flight keeps calling the write
  block callback on the USB task. The exit now waits (bounded to 1 s) for the
  write callback to go quiet before syncing and resetting, so a reset can't
  cut an in-progress `writeSectors()` and leave a truncated file or an
  inconsistent FAT.
- **Selecting USB storage with no cable plugged in no longer reboots the
  device.** `USB_MSC_ENABLE()` had no VBUS precondition and the parked USB
  loop reads "VBUS absent" as "cable pulled" on its first iteration, so
  choosing USB before plugging in instantly reset the unit. USB mode now
  requires VBUS: the menu shows "Plug in USB cable first!" instead of
  entering (and the enable path bails defensively too, taking no SD lock and
  not enumerating).
- **USB mass-storage no longer races the host for the SD card.** While the
  drive was mounted the main loop kept running `GPS_LOOP()`,
  `trackDetectionLoop()`, auto-idle, etc., so the firmware and the host PC
  could both drive the FAT — corruption was prevented only as a side effect
  of the access mutex denying those acquires, not by design. The loop now
  parks while `usbMscActive` (mirroring the BLE branch): GPS/tach/lap/SD
  processing is skipped entirely, only the Exit button and the status page
  are serviced, so the host owns the card uncontested.
- **Unplugging the USB cable now exits mass-storage mode.** Previously the
  only way out was the on-device Exit button; pulling the cable (the natural
  way to "finish") left the device stuck `usbMscActive` — holding the
  `SD_ACCESS_USB_MSC` lock and the EMI-unsafe 8 MHz SD clock indefinitely,
  so a subsequent drive would silently fail to log. The parked loop now
  watches VBUS and reboots out of USB mode when the cable is removed.
- **Simulator: center button in race mode now switches pages** (pace
  while moving, best lap when stopped) exactly like the hardware. The
  old Wokwi-era `#ifdef SIM` carve-out toggled panel inversion instead —
  invisible in the simulator (inversion happens in the panel, not the
  framebuffer), so the button read as dead. Hardware behavior unchanged;
  the now-unused `displayInverted` global is removed.
- **I2C bus recovery no longer risks a reboot loop.** `i2cBusRecover()`
  re-inits Wire and the OLED over I2C, which can block if ignition EMI is
  still glitching the bus — and it never fed the watchdog, so the recovery
  routine itself could trip the 4 s WDT and reset, then re-trigger on the
  next boot. It now pets the watchdog before each blocking re-init step
  (matching the GPS baud-recovery hardening), and `safeDisplayUpdate()`
  recovers a hung bus immediately instead of waiting one more (also-slow)
  frame.
- **Logging init aborts cleanly if the SD card drops mid-header.** The DOVEX
  1 KB header pre-fill ignored each `write()` return, so a card dropping
  sectors during log creation could leave a truncated header region while
  the firmware still marked logging ready and streamed rows into it. The
  pre-fill now verifies every write and aborts the open (retrying next
  second) on a short write.
- **A mid-session SD write failure now tries to save the lap times.** When a
  data-row write fails (typical of a failing card/tray), logging stops
  cleanly as before — but the reserved header is now written first, so the
  session's lap list and best/optimal times survive instead of being lost
  with the session.
- **`buildTrackList()` now arbitrates SD access.** The track-list/manifest
  rebuild walked the `/TRACKS` directory with raw SdFat calls and no access
  mutex, the lone SD consumer that didn't — leaving a window where a BLE
  track upload/delete completing during a logging teardown could touch SdFat
  from two tasks. It now holds `SD_ACCESS_TRACK_PARSE` for the walk and
  checks the directory open.
- **Track detection no longer throttles the whole main loop.** The manifest
  scan (O(N) software-double haversine, several ms at the 200-entry ceiling)
  was gated only on `gpsData.fix`, which stays true between PVT updates — so
  it ran every ~250 Hz loop iteration instead of "every GPS fix" as
  documented, dragging the loop rate down while hunting for a track. The
  scan is now throttled to 1 Hz, which is still instant at driving pace.
- **Tach ring buffer can no longer be lapped during SD stalls.** The pulse
  ISR advanced the ring head unconditionally; an SD GC stall (the documented
  100 ms–2 s, the same reason the GPS serial ring exists) at racing RPM
  overruns the 16-entry buffer, breaking the ring invariant and producing a
  confident-but-wrong RPM that was logged to CSV and fed the >500 RPM
  auto-race trigger. The ISR now checks full and drops the pulse instead,
  flagging the gap so `TACH_LOOP()` discards the one period spanning it —
  the Kalman estimate coasts briefly rather than going silently wrong. The
  filter math itself moved to the host-tested `tach_filter` pure unit.
- **GPS baud recovery no longer risks tripping the 4 s hardware watchdog.**
  `GPS_BAUD_RECOVERY()` can block for up to three ~1.1 s module probes plus
  ~500 ms of delays — against a genuinely hung GPS that out-waited the WDT,
  causing a reset → re-setup → recovery → reset boot loop. It now pets the
  watchdog before each blocking probe (same treatment `fwStageToFlash()`
  already had).
- **Sleep mode actually sleeps now.** The tach ISR latched `tachHavePeriod`
  on the first engine pulse since boot and nothing ever cleared it, so every
  sleep entry (long-press, 5-min menu idle, USB) instantly bounced through
  the RPM-wake path back into race mode **with logging enabled** — the
  device would silently start a new session and drain the pack overnight.
  `enterSleepMode()` now calls the new `TACH_SLEEP()`, which re-arms the
  wake trigger and drops stale ring-buffer/Kalman state; the next *real*
  pulse still RPM-wakes straight into race mode as designed. (Superseded
  within this release by the full System OFF shutdown, above.)
- **Lap times under 100 ms-fraction rendered wrong on the live pages.** The
  current-lap, best-lap, and optimal-lap pages appended the millisecond
  zero-padding *after* the value, so `1:23.007` displayed as `1:23.700` (a
  693 ms error), and the lap-history list did no padding at all (`1:5.7`).
  All six divergent inline copies of the ms → `M:SS.mmm` math are replaced
  by one host-tested `lap_format` unit; the replay page's already-correct
  rendering is unchanged, and the lap list now shows zero-padded
  `M:SS.mmm`. (Cosmetic side effect: once a lap passes one minute the
  big-font live pages now zero-pad the seconds — `1:05.007` rather than the
  old `1: 5.007` — same field width, so the column stays stable.)

### Security
- **SD card arbitration race fixed — a BLE client in radio range could
  corrupt the card.** `acquireSDAccess()` was a non-atomic check-then-set on
  a shared flag, and several BLE commands (`LIST`, `GET:`, `DELETE:`,
  `TLIST`, `TGET:`) ran SdFat directly in the Bluefruit callback task —
  concurrently with the main loop's 25 Hz session logging. Overlapping
  commands could close a file mid-read, delete the file being streamed
  (`DELETE:` took no lock at all), or interleave two SdFat operations:
  FAT corruption, lost session logs, or an SPI wedge. Now: lock
  transitions are atomic (FreeRTOS critical section; the grant/deny table
  is the new host-tested `sd_access_policy` unit), all five commands are
  deferred to `BLUETOOTH_LOOP()` on the main loop like the
  settings/track/OTA commands already were, directory listings hold the
  lock for the whole walk, and `DELETE` takes the lock and refuses with
  `BUSY` while a transfer is streaming. Protocol impact: commands that
  arrive while another file command is still queued now get the existing
  `BUSY` / `TERR:BUSY` replies instead of executing concurrently.

## [2.2.3] - 2026-06-10

### Added
- **The OLED now shows a full-screen "UPDATING FIRMWARE / Do not power off"
  notice during an OTA apply.** The apply blocks the main loop (UI frozen) and
  ends in a reboot; previously the screen just sat on a stale page with no
  indication anything was happening. The notice stays up through staging and
  the swap until the new firmware boots and repaints; on a failed apply the
  normal 3 Hz display refresh replaces it automatically.
- **Beta OTA manifest now lists each variant's `.uf2`** (`builds[model].uf2`).
  The `.uf2` was already published to `beta/`, just not referenced — exposing
  it makes drag-and-drop bootloader (DFU-mode) recovery easy when an OTA fails.
- **Firmware OTA apply emits `FWDBG:*` breadcrumbs** (`APPLY`, `VBAT=<mv>`,
  `STAGE`, `ERASE=<pages>`, `ERASED`) over the status characteristic so a stall
  before `FWAPPLIED` can be pinpointed from the web app's raw notification log
  — apply entered? battery reading seen? staging/erase reached? The up-front
  staging-region erase is several seconds with no progress notify (and may run
  while BLE is still connected), so it is bracketed explicitly.
- **Beta / nightly firmware channel.** A new `beta` CI workflow builds both
  XIAO nRF52840 variants on every push to the `BETA` branch and publishes them
  to a `beta/` subtree on `gh-pages` — a second OTA channel that lives
  alongside the production one at the Pages root (the deploy's `keep_files`
  keeps the two from clobbering each other). No GitHub Release and no version
  tag are cut; these are throwaway debug builds you flash from your phone via
  DovesDataViewer's beta channel while at the track. `beta/manifest.json`
  mirrors the prod manifest shape (so the web client reuses one parser) plus
  `channel`, `commit`, and `branch` markers, and points at `beta/` asset URLs.
  Retention is **latest-only** — a single flat `beta/` slot, overwritten each
  push (no per-build history, unlike prod's `firmware/<version>/`).

### Fixed
- **Device now boots straight into the new firmware after an OTA apply
  (no more manual power-cycle).** The apply arms the bootloader-recovery
  magic (`GPREGRET = 0xA8`, OTA-DFU) before the destructive swap, but never
  cleared it on success — so after the RAM flasher's reset the bootloader saw
  the magic and parked in BLE DFU mode instead of booting the freshly
  installed app (blank/stale screen, odd USB device on the PC; a manual
  power-cycle cleared the register, which is why it booted fine afterwards).
  The RAM flasher now clears `GPREGRET` after a successful copy, immediately
  before its reset. An interrupted swap never reaches that line, so the
  recovery net is unchanged.
- **Firmware OTA self-flash swap never took effect — `FWAPPLIED` but still the
  old image after reboot.** The apply disabled the SoftDevice (`sd_softdevice_
  disable()`) with the web app *still connected* and ignored the return code.
  The SoftDevice won't cleanly disable while a link is up, so it stayed partly
  active, flash remained SoftDevice-protected, and the RAM flasher's raw NVMC
  erase/copy silently no-opped — but the final `SCB->AIRCR` reset still fired,
  rebooting into the intact old application. The apply now **disconnects the
  central and waits for the link to close** before disabling the SoftDevice,
  and **checks the disable return** — on failure it resets toward the armed
  bootloader-recovery flag instead of running a swap that can't write.
- **Firmware OTA apply was aborted by the BLE disconnect, so the update never
  installed.** After `FWAPPLY`, the web app disconnects to hand the device off
  to self-flash — but `BLUETOOTH_LOOP()` ran its disconnect teardown (which
  calls `fwReset()` to abort the OTA, then `NVIC_SystemReset()`) *before*
  `FW_OTA_LOOP()`, where the apply actually runs. So a disconnect at that point
  discarded the staged image and rebooted into the **old** firmware (reported
  as "applied OK, rebooted, still the old version"). The disconnect teardown
  now detects an in-flight apply (`fwApplyRequested()`) and skips both the abort
  and the reboot, leaving the install to `FW_OTA_LOOP()`, which owns its own
  reset. The SoftDevice is still up at that point, so the SD→flash staging and
  CRC re-verify proceed normally with the radio already gone.

### Changed
- **`FIRMWARE_VERSION` can now be overridden at build time.** `project.h`
  stringizes an optional `-DFIRMWARE_VERSION_OVERRIDE=<token>` build flag, so a
  beta build self-reports its exact commit over BLE as `<base>-beta.<gitsha>`
  (e.g. `2.2.2-beta.abcdef0`) — read the version off a device and you know
  precisely which nightly is on it. A normal build (prod release, plain IDE,
  `compile-sketch` CI) leaves the flag undefined and uses the literal base
  version, so nothing changes for production. The OTA image descriptor's
  `version` field was widened 16 → 32 bytes to hold the longer beta strings.

## [2.2.2] - 2026-06-08

### Fixed
- **`FIRMWARE_VARIANT` now follows the board you select in the Arduino IDE.**
  Previously, only the CI/release flags (`-DBIRDSEYE_BOARD_SENSE` /
  `-DBIRDSEYE_BOARD_NONSENSE`) set the variant; a plain IDE build with neither
  flag always reported `"sense"` regardless of the selected board, so a
  non-Sense unit flashed from the IDE mislabeled itself in its BLE DIS Model
  Number (and thus to the OTA update check). `project.h` now derives the
  variant from the Seeeduino core's `ARDUINO_Seeed_XIAO_nRF52840[_Sense]` board
  macro when no explicit build flag is present. The explicit CI flags still
  take precedence, and an unknown board still defaults to `"sense"`.

## [2.2.1] - 2026-06-08

### Changed
- **Firmware OTA: the target variant is now declared in the `FWBEGIN`
  handshake instead of inferred from the image bytes.** The command gains a
  third field — `FWBEGIN:<size>,<crc32>,<variant>` — where `<variant>` is the
  target board variant (`sense` / `nonsense`) that the web app derives
  authoritatively from the device's own DIS Model Number. The firmware
  compares it (case-insensitively) to its compile-time `FIRMWARE_VARIANT` and
  replies `FWERR:VARIANT` *before any upload* on a mismatch. The old image-byte
  scan at `FWAPPLY` (which misfired `FWERR:VARIANT` on correct sense→sense
  flashes) has been removed; the embedded image descriptor is retained for
  forensics only. **Breaking:** a web client that still sends the two-field
  `FWBEGIN:<size>,<crc32>` is rejected — the web side updates in lockstep.

## [2.2.0] - 2026-06-08

### Fixed
- **Logging no longer starts before the GPS has a real time lock.** File
  creation was gated only on `day > 0`, so before the module resolved UTC it
  would create a log named from its placeholder date (e.g.
  `20210307_0000.dovex`). That name was identical on every boot and, once a
  write was interrupted, the half-written file could no longer be reopened —
  producing a "Error saving log" fault that reproduced on every reboot. File
  creation now requires the module's `validDate + validTime + fullyResolved`
  flags, and `fix` now also requires `gnssFixOK`.

### Changed
- **Logging failures never drop out of race mode.** When a session is running
  with the engine turning but no GPS lock yet, the device now pins the user to
  the tachometer and waits, then begins logging and resumes normal race-mode
  navigation the moment a valid lock arrives. A failed log-file open is
  retried (throttled to 1 Hz) instead of faulting, and a mid-session write
  failure stops logging while the race continues — none of these show the
  full-screen "Please Reboot Device" fault anymore.
- Sketch sources moved into the `BirdsEye/` subfolder so the folder name
  matches `BirdsEye.ino` (Arduino IDE / arduino-cli requirement).
- DOVEX header read/write now goes through a single tested
  `dovex_header::format()` / `parse()` implementation. On-disk format is
  unchanged (byte-for-byte compatible with existing `.dovex` files).
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

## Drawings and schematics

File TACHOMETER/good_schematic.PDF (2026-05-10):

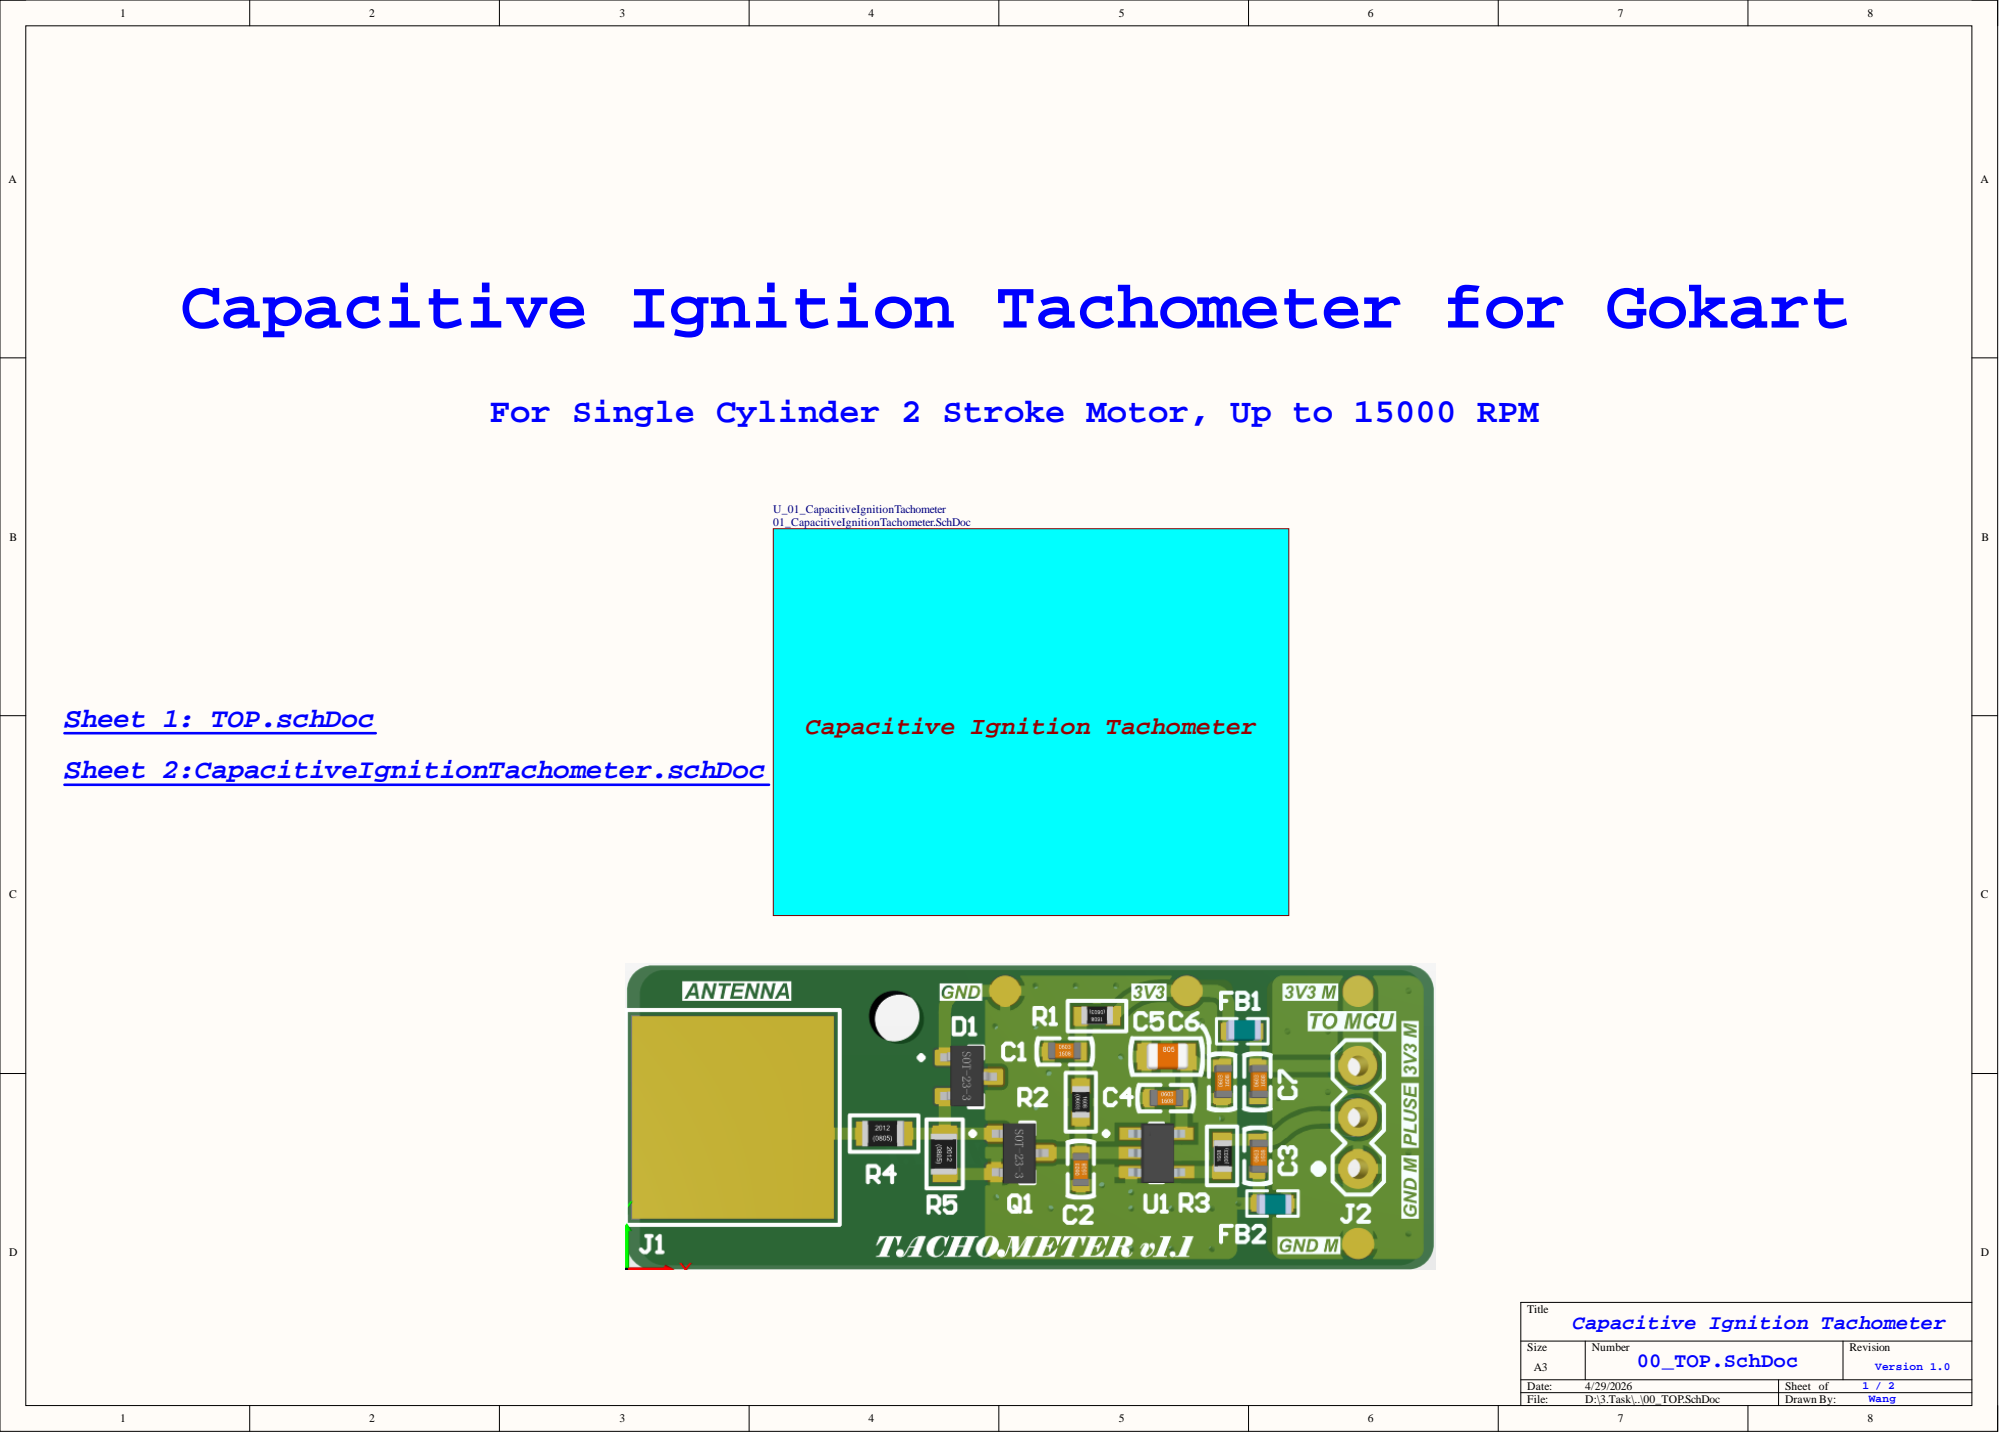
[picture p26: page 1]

Capacitive Ignition Tachometer for Gokart

For Single Cylinder 2 Stroke Motor, Up to 15000 RPM

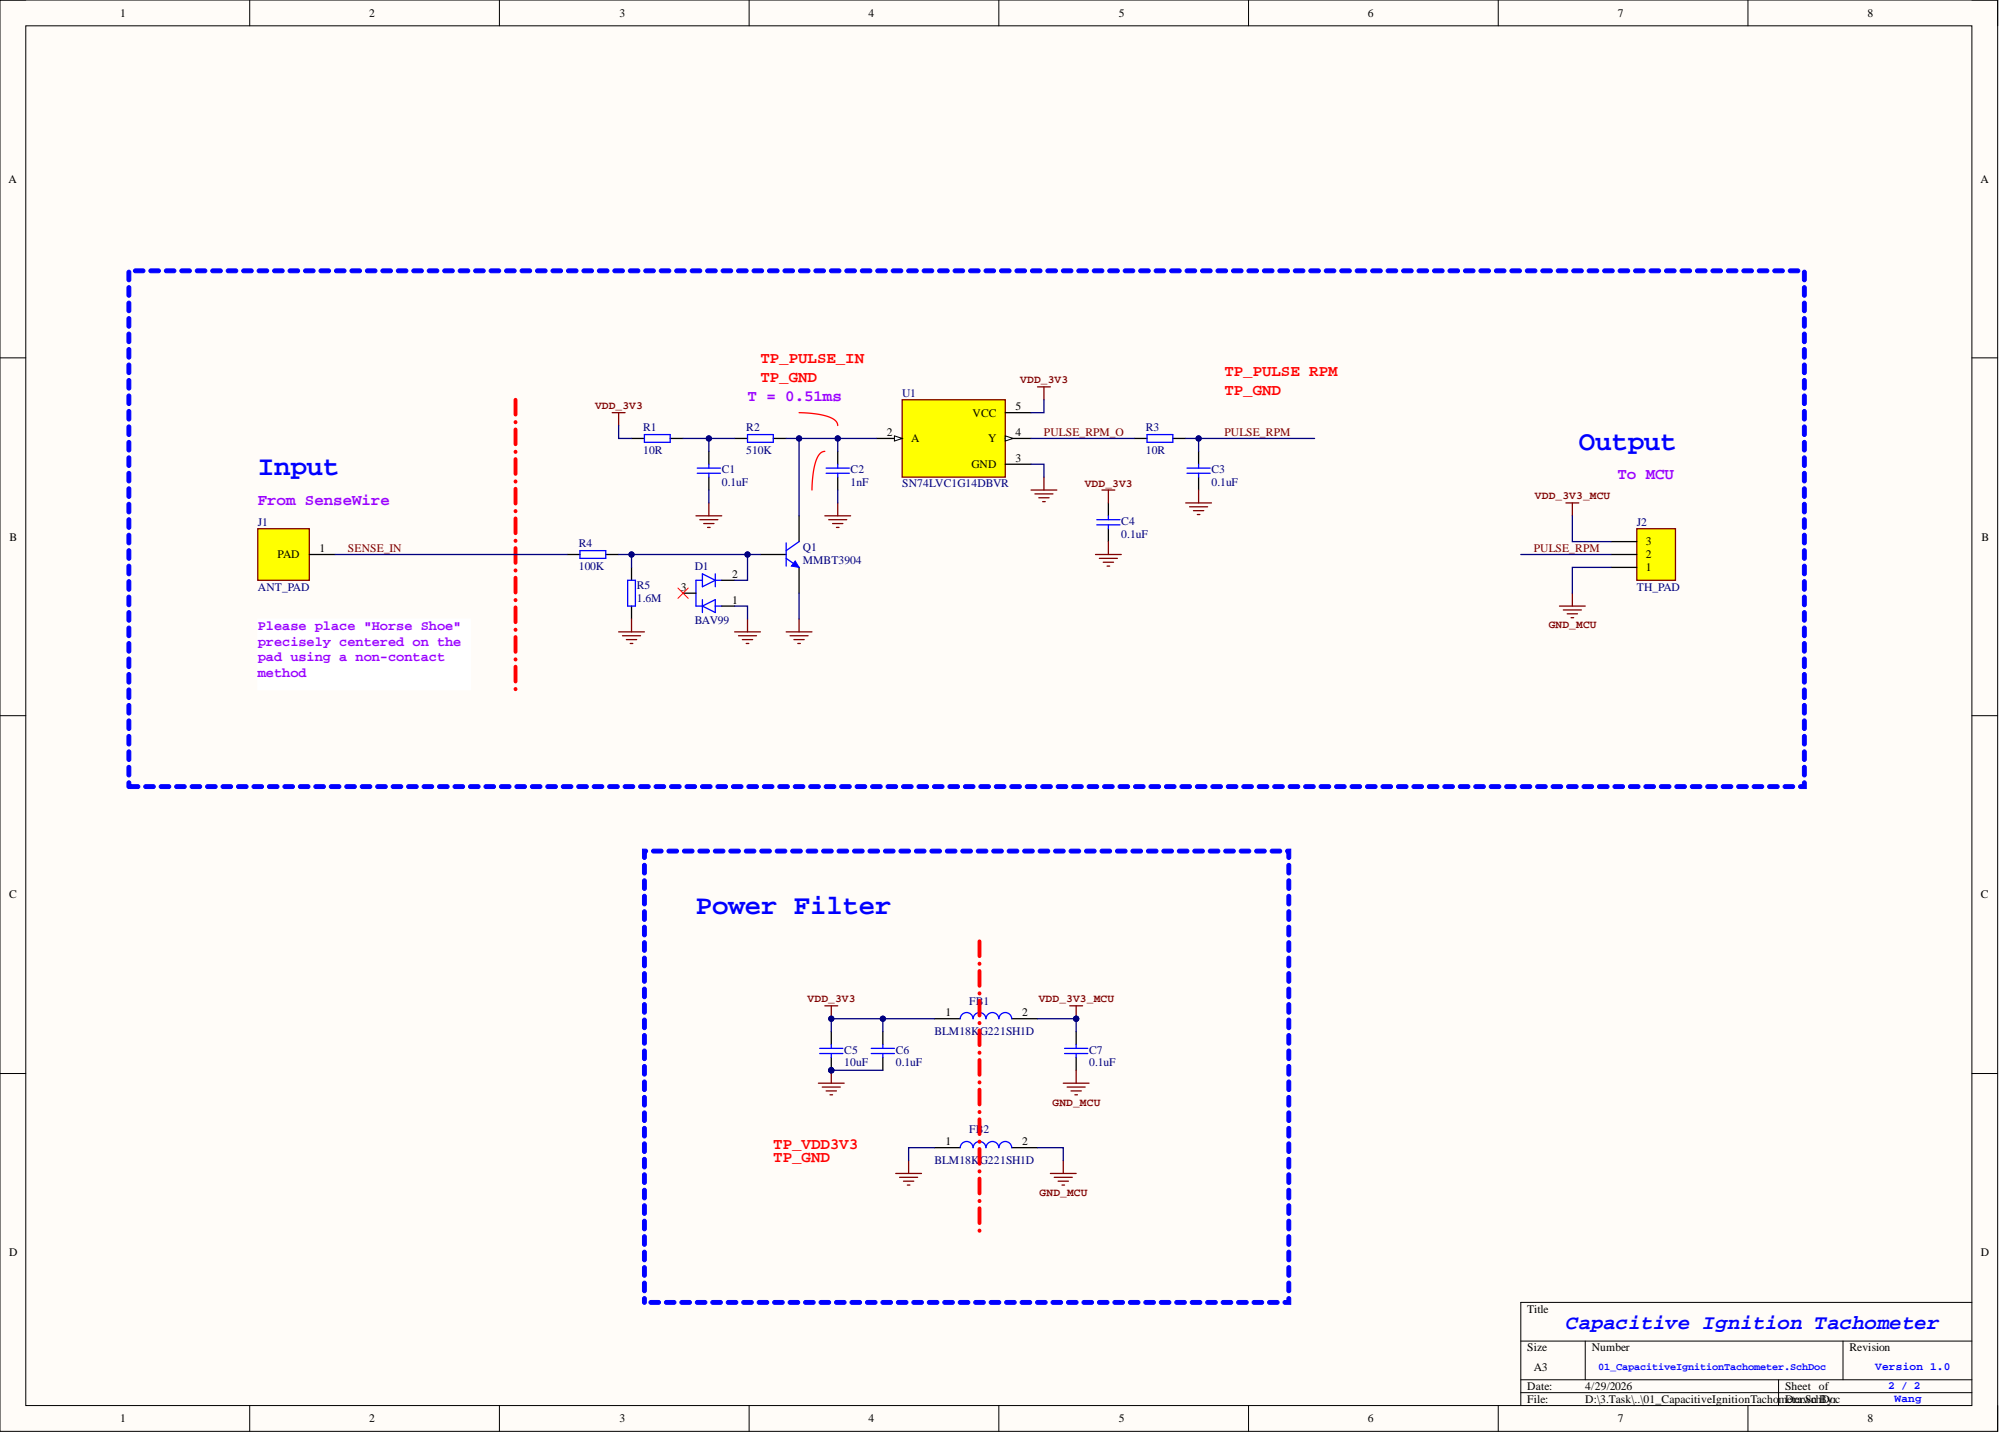
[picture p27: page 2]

Please place "Horse Shoe"
precisely centered on the
pad using a non-contact
method

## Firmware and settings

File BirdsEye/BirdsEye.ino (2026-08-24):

///////////////////////////////////////////
// DovesDataLogger - BirdsEye Main Sketch
//
// This is the main sketch file containing global state, includes,
// setup(), and loop(). All function implementations are split into
// separate module files (Arduino concatenates .ino files automatically):
//
//   accelerometer.ino - LSM6DS3 IMU accelerometer reads (g-force)
//   bluetooth.ino    - BLE file transfer service
//   display_pages.ino - All display page rendering functions
//   display_ui.ino   - Display setup, button handling, menu navigation
//   gps_functions.ino - GPS setup, loop, time functions, data logging
//   profiling.ino    - Main-loop CPU profiling (beta channel only)
//   replay.ino       - Session replay system
//   sd_functions.ino - SD card setup, track parsing, access management
//   settings.ino     - Persistent JSON settings on SD (/SETTINGS.json)
//   tachometer.ino   - Tachometer ISR and loop processing
//
///////////////////////////////////////////

#include <avr/dtostrf.h>
#include <SPI.h>
#include <nrf_gpio.h>  // SENSE-wake pin config for System OFF shutdown
#include <nrf_wdt.h>

// #define SIM
// #define HAS_DEBUG

// Hides a couple pages and changes some behavior
// todo: make dynamic in next UI version
// #define ENDURANCE_MODE

// Project-wide types and macros - MUST be included before Arduino
// auto-generates function prototypes from the other .ino files,
// otherwise custom types (ButtonState, TrackLayout, etc.) won't
// be resolved in function signatures.
#include "project.h"

// SparkFun GPS library must be included here (in the top include block)
// so that UBX_NAV_PVT_data_t is in scope when Arduino auto-generates
// function prototypes for the onPVTReceived() callback.
#include <SparkFun_u-blox_GNSS_v3.h>
#include "gps_config.h"
#include <DovesLapTimer.h>
#include <CourseManager.h>
#include <SprintTimer.h>
// ArduinoJson is here for the same reason, and it is load-bearing: the track
// helpers in sd_functions.ino take and return JsonArray, and Arduino generates
// their prototypes ABOVE this point. Included further down (where the JSON
// globals live) those prototypes see no such type, quietly degrade the
// parameter to `int`, and every one of them fails to compile with "redeclared
// as different kind of entity". The simulator cannot catch this — it hand-writes
// its prototypes — so the only signal is the Arduino build.
#include <ArduinoJson.h>

// SdFat configuration. SD_FAT_TYPE must be defined BEFORE SdFat.h is
// processed for the first time, which means before any module header
// that pulls it in (e.g. replay.h).
//   0 = bare SdFat/File   (SIM only)
//   1 = SdFat32/File32    (real hardware — FAT16/FAT32)
//   2 = SdExFat/ExFile
//   3 = SdFs/FsFile
#ifdef SIM
#define SD_FAT_TYPE 0
#define PIN_SPI_CS -1
#else
#define SD_FAT_TYPE 1
#define PIN_SPI_CS -1  // CS is grounded on the gry-box revision
#endif
// 2 MHz SPI for EMI tolerance in ignition environments — 12.5x below
// the SdFat default (25 MHz) but still fast enough for 25 Hz logging
// and the BLE-2M file transfer ceiling.
#define SPI_SPEED SD_SCK_MHZ(2)

// Parked-transfer SPI clock. File transfers (BLE / USB mass storage) only
// happen with the motor off, so the ignition-EMI rationale for the slow 2 MHz
// clock doesn't apply — sdSetTransferSpeed(true) bumps to this for the session
// and reverts to SPI_SPEED afterward. Bump to SD_SCK_MHZ(16) if the board
// proves it can sustain it (the nRF52840 standard SPIM may clamp 16 to 8 MHz).
#define SD_SPI_SPEED_FAST SD_SCK_MHZ(8)

#include "SdFat.h"
#include "sdios.h"

// TinyUSB — provides Adafruit_USBD_MSC / TinyUSBDevice for the USB
// mass-storage transfer mode (usb_msc module). Must precede usb_msc.h.
#include <Adafruit_TinyUSB.h>

// Module interfaces. Each header documents its module's public
// surface and pulls in any library types those signatures need.
#include "accelerometer.h"
#include "bluetooth.h"
#include "camera_ble.h"
#include "course_creator.h"
#include "display_pages.h"
#include "display_ui.h"
#include "dovex_header.h"
#include "gps_functions.h"
#include "gps_status_page.h"
#include "haversine.h"
#include "idle_policy.h"
#include "local_time.h"
#include "setting_parse.h"
#include "neopixel.h"
#include "profiling.h"
#include "replay.h"
#include "sat_bars.h"
#include "sd_format_page.h"
#include "sd_functions.h"
#include "sensoregg.h"
#include "settings.h"
#include "sprint_select.h"
#include "tach_filter.h"
#include "tachometer.h"
#include "usb_msc.h"
#include "wake_cause.h"

///////////////////////////////////////////
// BATTERY CONFIGURATION
///////////////////////////////////////////

// designed for seeed NRF52840 which comes with a charge circut
#define VREF 3.6
#define ADC_MAX 4096

unsigned long lastBatteryCheck;
int batteryUpdateInterval = 5000;
float lastBatteryVoltage;

float getBatteryVoltage() {
  #ifdef SIM
  return 3.75;
  #else
  unsigned int adcCount = analogRead(PIN_VBAT);
  float adcVoltage = adcCount * VREF / ADC_MAX;
  // Nominal divider: (1000+510)/510 = 2.9608, but reads ~2% low due to
  // resistor/VREF tolerances (4.11V observed at true 4.20V full charge).
  // Calibrated: 2.9608 * (4.20/4.11) = 3.024
  return adcVoltage * 3.024;
  #endif
}

int getBatteryPercent(float voltage) {
  // LiPo range: 3.3V (cutoff) to 4.2V (full charge)
  return constrain((int)((voltage - 3.3) / 0.9 * 100), 0, 100);
}

///////////////////////////////////////////
// LAP TIMER / SESSION STATE
///////////////////////////////////////////

double crossingThresholdMeters = 7.0;
unsigned long gpsFrameStartTime;
unsigned long gpsFrameEndTime;
unsigned long gpsFrameCounter;
float gpsFrameRate = 0.0;

CourseManager* courseManager = nullptr;
TrackConfig activeTrackConfig;
bool trackDetected = false;
int detectedTrackIndex = -1;

// Sprint mode (plan 0002): point-to-point runs instead of laps. The mode
// follows the detected track's folder — a non-null sprintTimer IS sprint
// mode (courseManager stays null for the session, and vice versa).
SprintTimer* sprintTimer = nullptr;
char sprintCourseName[MAX_LAYOUT_LENGTH] = "";
int sprintLastRunCount = 0;  // run-complete edge for lap history capture
unsigned long idleStartTime = 0;
bool idleTimerRunning = false;
bool raceActive = false;
unsigned long raceSessionStartedAt = 0;  // For auto-idle grace period after RPM wake
// How the active session started (RACE_ENTRY_NONE between sessions). Decides
// the session-end rule and the camera driver: manual/speed sessions have no
// engine signal, so they record from session start and end on the 5 min
// below-5 mph idle rule; tach sessions keep the RPM-driven behaviour.
RaceEntryCause raceEntryCause = RACE_ENTRY_NONE;

// Runtime settings (loaded from SD in setup)
float settingLapDetectionDistance = 7.0;
float settingWaypointDetectionDistance = 30.0;
float settingWaypointSpeed = 30.0;
char settingDriverName[32] = "Driver";
char settingDeviceName[32] = "BirdsEye";
// race_mode preference — ONLY the tiebreak when both a circuit and a
// sprint track are within detection range (sprint_select::chooseKind).
// It never overrides what is actually detected.
bool settingRaceModePrefSprint = false;
// NeoPixel strip (plan 0006): global brightness cap (0-255, 0 = LEDs
// disabled entirely) and the target RPM (true RPM) the LED scale/flasher
// are anchored to. Read at boot only, like every other setting.
//
// settingTargetRpm was `settingRevLimit` / the `rev_limit` key until plan
// 0013. It is the SHIFT point — where the driver wants to know the engine
// is at its working ceiling — and never was a limiter; settingOverrevLimit
// below is the real limit. The old name taught the wrong thing to
// everyone who opened SETTINGS.json, so both the key and the global moved.
uint8_t settingLedBrightness = 64;
int settingTargetRpm = 15000;
// Plan 0007: the PROBLEM limit — an engine at overrev_limit is broken,
// not just at its ceiling. 0 = disabled. And the Temp1 (EGT) alert
// threshold in Celsius for the right status LED.
int settingOverrevLimit = 0;
int settingTemp1AlertC = 650;
// Plan 0010: minutes east of UTC. PRESENTATION ONLY — the DOVEX rows,
// the header datetime and every generated filename stay UTC, and the
// webapp converts on the viewing side (you might be reading a log from
// another state). The single consumer is the LED day/night swap, which
// needs the driver's 7am rather than Greenwich's.
int16_t settingUtcOffsetMin = 0;
// Night-time LED cap and the LOCAL hours the swap happens on. Equal
// hours = no swap. A night cap of 0 blanks the strip but leaves the
// 5 V rail up — only led_brightness 0 cuts the rail (NEOPIXEL_SETUP).
uint8_t settingLedBrightnessNight = 16;
uint8_t settingLedDayStartHour = 7;
uint8_t settingLedNightStartHour = 19;
// Plan 0013: the speed the 9-px bar scales against on a session with no
// tachometer (mph, stored in mph — the companion app converts for
// display), and what each status LED is assigned to show. The defaults
// reproduce the pre-0013 hardcoded pair on a SensorEgg build; a stock
// build gets the lap indicator on the right instead of a Temp1 readout
// with no probe behind it.
int settingTargetSpeedMph = 60;
led_status::Mode settingLedStatusLeft = led_status::Mode::kRpm;
#if BIRDSEYE_ENABLE_SENSOREGG
led_status::Mode settingLedStatusRight = led_status::Mode::kEgt;
#else
led_status::Mode settingLedStatusRight = led_status::Mode::kLap;
#endif

// Track manifest for proximity detection
TrackManifestEntry trackManifest[MAX_LOCATIONS];
int trackManifestCount = 0;

// DOVEX replay globals (populated by parseDovexHeader in replay.ino)
char dovexReplayDatetime[24];
char dovexReplayDriver[32];
char dovexReplayCourseName[32];
char dovexReplayShortName[16];
char dovexReplayBestLap[16];
char dovexReplayOptimal[16];

// Main-menu idle tracking (drives auto-shutdown and the USB charge-mode
// entry — see the trigger block at the end of loop()).
unsigned long menuIdleStartTime = 0;
bool menuIdleTimerRunning = false;

// When the main menu was last ARRIVED at, stamped by switchToDisplayPage().
// autoRaceModeCheck() uses it (with the button stamps) to tell "the user just
// landed here" from "the device has been sitting on the menu" — see
// AUTO_RACE_MENU_GRACE_MS.
unsigned long mainMenuEnteredAtMs = 0;

// Button hold tracking (for long-press combos)
unsigned long btn1HoldStart = 0;
unsigned long btn2HoldStart = 0;
unsigned long btn3HoldStart = 0;
bool btn1Held = false;
bool btn2Held = false;
bool btn3Held = false;

///////////////////////////////////////////
// PROJECT DEFINES
///////////////////////////////////////////

#define SD_CARD_LOGGING_ENABLED
// MAX_LOCATIONS, MAX_LOCATION_LENGTH, MAX_LAYOUTS, MAX_LAYOUT_LENGTH
// are now defined in project.h for use by project-wide structs
#define FILEPATH_MAX 64        // "/TRACKS/SPRINT/" (15) + manifest name (31) + ".json" (5) + null = 52, using 64 for safety
#include <string.h>

///////////////////////////////////////////
// BUTTON CONFIGURATION
//
// HARDWARE EMI RECOMMENDATIONS FOR BUTTONS:
// Phantom button presses can occur from EMI coupling, especially from
// the tachometer signal. To improve button reliability:
//
// 1. RC FILTER: Add 10K resistor + 100nF cap from each button pin to GND
//    This creates a ~160Hz low-pass filter that eliminates high-freq noise
// 2. WIRE ROUTING: Keep button wires away from tach/ignition wiring
// 3. SHIELDING: If buttons are on a ribbon cable, add ground wire between signals
// 4. FERRITE: Add ferrite bead on button cable near MCU for extra HF rejection
//
// The software debouncing below uses multi-sample verification to reject
// transient noise spikes that get through hardware filtering.
///////////////////////////////////////////

// ButtonState, TrackLayout structs defined in project.h
// debug/debugln macros defined in project.h

///////////////////////////////////////////
// BLUETOOTH (BLE) GLOBALS
///////////////////////////////////////////
#include <bluefruit.h>

// BLE Service & Characteristics
BLEService fileService = BLEService(0x1820);
BLECharacteristic fileListChar = BLECharacteristic(0x2A3D);
BLECharacteristic fileRequestChar = BLECharacteristic(0x2A3E);
BLECharacteristic fileDataChar = BLECharacteristic(0x2A3F);
BLECharacteristic fileStatusChar = BLECharacteristic(0x2A40);

// OTA + version reporting services (set up in BLE_SETUP()):
//   bledfu - buttonless Secure DFU; a write reboots the board into the
//            bootloader's OTA mode so a companion can flash new firmware.
//   bledis - Device Information Service; publishes FIRMWARE_VERSION so the
//            companion can tell whether an update is available.
BLEDfu bledfu;
BLEDis bledis;
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
void loop() {
  #ifndef SIM
  wdtPet();
  #endif

  // Whole-iteration timing + the once-a-second rollup (plan 0011, beta
  // only). A scope guard rather than a call at the bottom because both
  // parked branches below return early and enterShutdown() never returns
  // at all — a profiler that goes quiet exactly when the firmware parks
  // would be measuring the wrong thing. Compiles to nothing off beta.
  PROFILE_LOOP_SCOPE();

  #ifdef HAS_DEBUG
  unsigned long loopStart = millis();
  #endif

  // When BLE is active, skip GPS/tach/lap processing for better throughput
  if (bleActive) {
    PROFILE_SECTION(loop_profile::kBle, BLUETOOTH_LOOP());

    // Keep battery voltage fresh for BLE BATT command and display
    if (millis() - lastBatteryCheck > batteryUpdateInterval) {
      lastBatteryCheck = millis();
      lastBatteryVoltage = getBatteryVoltage();
    }

    // Minimal button check for exit. Leaving transfer mode reboots (same
    // as the phone-disconnect auto-reboot and the USB exit) so changed
    // settings take effect and no session state leaks.
    PROFILE_SECTION(loop_profile::kButtons, readButtons());
    if (btn2->pressed) {
      bleExitTransferMode();  // does not return (NVIC_SystemReset)
    }
    resetButtons();

    // Reduced display rate: 5s during transfer, normal otherwise
    unsigned long displayInterval = bleTransferInProgress ? 5000 : (1000 / displayUpdateRateHz);
    if (millis() - displayLastUpdate > displayInterval) {
      displayLastUpdate = millis();
      PROFILE_SECTION(loop_profile::kDisplay, displayPage_bluetooth());
    }

    // Keep the LED frame ticking so the strip blanks (composition sees
    // the parked state) instead of freezing mid-pattern.
    PROFILE_SECTION(loop_profile::kLed, NEOPIXEL_LOOP());

    return; // Skip GPS, tach, lap checks while BLE is active
  }

  // When USB mass-storage is active the host PC owns the SD card over MSC.
  // Park the loop exactly like the BLE branch so the firmware never drives
  // the FAT concurrently with the host — GPS/tach/lap/SD processing is all
  // skipped. (The SD-access policy would deny those acquires anyway, but
  // parking here is the real guarantee rather than a side effect.)
  if (usbMscActive) {
    // Cable pulled without using the on-device Exit (the natural way to
    // "finish") — tear down so the SD lock, the fast SPI clock, and the
    // media-ready state don't leak into a later driving session and
    // silently refuse to log. USB_MSC_DISABLE() reboots and does not return.
    if (!isUsbConnected()) {
      USB_MSC_DISABLE();
    }

    // Minimal button check for the on-device Exit (Select).
    PROFILE_SECTION(loop_profile::kButtons, readButtons());
    if (btn2->pressed) {
      USB_MSC_DISABLE();  // does not return (NVIC_SystemReset)
    }
    resetButtons();

    // Refresh the status page at the normal rate.
    if (millis() - displayLastUpdate > (1000 / displayUpdateRateHz)) {
      displayLastUpdate = millis();
      PROFILE_SECTION(loop_profile::kDisplay, displayPage_usb_storage());
    }

    // Same as the BLE branch: blank the strip rather than freeze it.
    PROFILE_SECTION(loop_profile::kLed, NEOPIXEL_LOOP());

    return;  // host owns the card — skip GPS/tach/lap/SD entirely
  }

  // Each subsystem call is bracketed for the loop profiler (plan 0011).
  // PROFILE_SECTION expands to the bare call off the beta channel, so
  // this is the same sequence it has always been.
  PROFILE_SECTION(loop_profile::kGps, GPS_LOOP());
  PROFILE_SECTION(loop_profile::kTach, TACH_LOOP());
  PROFILE_SECTION(loop_profile::kAccel, ACCEL_LOOP());
  PROFILE_SECTION(loop_profile::kBle, BLUETOOTH_LOOP());
  // drain SensorEgg scan buffer (Temp1 fresh for logging)
  PROFILE_SECTION(loop_profile::kEgg, SENSOREGG_LOOP());

  PROFILE_SECTION(loop_profile::kTrack, trackDetectionLoop());
  PROFILE_SECTION(loop_profile::kLap, checkForNewLapData());
  // One section for the three session-state checks: individually they are
  // a handful of comparisons, and thirteen slots on a 128x64 page is
  // already the budget.
  PROFILE_SECTION(loop_profile::kIdle, checkAutoIdle(); autoRaceModeCheck();
                  updateGpsLockHold());
  // step the Insta360 auto-record FSM (GPS/tach fresh above)
  PROFILE_SECTION(loop_profile::kCamera, CAMERA_LOOP());
  // LED strip frame (RPM/pace/purple fresh above)
  PROFILE_SECTION(loop_profile::kLed, NEOPIXEL_LOOP());

  // Camera auto-stopped recording (30 s engine-off): end + save the race
  // session and return to the menu — the camera stays connected in WATCHING,
  // ready to re-record if the engine restarts. endRaceSession() is idempotent
  // and does not switch pages itself, so we do (mirrors checkAutoIdle). A
  // manual logging-stop does not set this — that path already ended the log.
  // Consume UNCONDITIONALLY: the latch can be set with no session active
  // (e.g. the GPS-lock-hold idle ender leaves the camera recording, then the
  // engine dies on the menu), and a short-circuited read here let that stale
  // latch survive to kill the NEXT session on its first frame.
  {
    const bool cameraStopped = cameraConsumeAutoStop();
    if (raceActive && cameraStopped) {
      endRaceSession();
      switchToDisplayPage(PAGE_MAIN_MENU);
    }
  }

  // Button hold detection for shutdown/reboot combos. Bracketed into the
  // same section as readButtons(): it runs the identical multi-sample
  // debounce on all three pins, so leaving it out would park a
  // hold-dependent cost (up to ~1 ms per HELD button) in OTH, where it
  // reads as unexplained overhead rather than as button sampling.
  PROFILE_SECTION(loop_profile::kButtons, updateButtonHoldState());

  // Long-press left+right (5s) on main menu -> shutdown
  if (currentPage == PAGE_MAIN_MENU &&
      isButtonHeld(1, SLEEP_LONG_PRESS_MS) &&
      isButtonHeld(3, SLEEP_LONG_PRESS_MS)) {
    enterShutdown();
    return;
  }

  // Reboot combo: select + either side button held 5s (any page)
  if (isButtonHeld(2, SLEEP_LONG_PRESS_MS) &&
      (isButtonHeld(1, SLEEP_LONG_PRESS_MS) || isButtonHeld(3, SLEEP_LONG_PRESS_MS))) {
    NVIC_SystemReset();
  }

  // Main-menu idle tracking. Consumers:
  //  - USB present, onboard charging ENABLED: enter the charging loop after
  //    USB_MENU_CHARGE_IDLE_MS of no button activity. Not immediate — a
  //    charging-loop button wake lands here, and an instant re-entry would
  //    bounce it right back. The window is what lets replay/transfer be
  //    used while plugged in. Compiled out when charging is disabled: the
  //    firmware isn't managing the charge current, so a plugged-in cable is
  //    no reason to cut the menu short (the plain idle timeout still fires,
  //    and enterShutdown() parks on VBUS as always).
  //  - Always: full shutdown after SLEEP_IDLE_TIMEOUT_MS.
  if (currentPage == PAGE_MAIN_MENU) {
    if (!menuIdleTimerRunning) {
      menuIdleTimerRunning = true;
      menuIdleStartTime = millis();
    }
    // Button activity resets the idle clock. The `pressed` flags can't be
    // used here: readButtons() sets them AFTER this check runs and
    // resetButtons() clears them before the next iteration, so they always
    // read false at this point (menu navigation never reset the timer and
    // the device slept 5 min after menu entry regardless of activity —
    // 2026-07-19 field incident). The debouncer's lastPressed stamps
    // persist across iterations, so anchor on the newest of those.
    unsigned long lastBtn = btn1->lastPressed;
    if ((long)(btn2->lastPressed - lastBtn) > 0) lastBtn = btn2->lastPressed;
    if ((long)(btn3->lastPressed - lastBtn) > 0) lastBtn = btn3->lastPressed;
    if ((long)(lastBtn - menuIdleStartTime) > 0) {
      menuIdleStartTime = lastBtn;
    }
    unsigned long idleFor = millis() - menuIdleStartTime;
#if BIRDSEYE_ENABLE_ONBOARD_CHARGING
    if ((isUsbConnected() && idleFor >= USB_MENU_CHARGE_IDLE_MS) ||
        idleFor >= SLEEP_IDLE_TIMEOUT_MS) {
#else
    if (idleFor >= SLEEP_IDLE_TIMEOUT_MS) {
#endif
      enterShutdown();
      return;
    }
  } else if (currentPage == PAGE_INTERNAL_FAULT) {
    // FAULT is a buttons-disabled dead end (dead SD on a sealed unit). With
    // no idle timer it burned the battery flat on every charge — the same
    // rationale as the SD-format page's timeout. Reuse the menu idle pair:
    // buttons are disabled here, so a plain entry-stamped timeout is enough.
    if (!menuIdleTimerRunning) {
      menuIdleTimerRunning = true;
      menuIdleStartTime = millis();
    }
    if (millis() - menuIdleStartTime >= SLEEP_IDLE_TIMEOUT_MS) {
      enterShutdown();
      return;
    }
  } else {
    menuIdleTimerRunning = false;
  }

  calculateGPSFrameRate();
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

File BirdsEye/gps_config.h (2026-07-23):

#ifndef _DOVES_GPS_CONFIG_H
#define _DOVES_GPS_CONFIG_H

// GPS configuration constants used by GPS_SETUP()
// All module configuration is now handled via SparkFun VALSET API calls
#define GPS_BAUD_RATE      57600
#define GPS_NAV_RATE_HZ    25   // race rate (PVT only)
// Boot/status-page rate: slower nav solutions with UBX-NAV-SAT enabled so
// the GPS status page can draw per-satellite signal bars. Switched to
// GPS_NAV_RATE_HZ (NAV-SAT off) when the page exits — see gpsEnterRaceMode().
#define GPS_NAV_RATE_STATUS_HZ 5
// maxWait for the connection-probe begin() calls (probe ladder, baud
// recovery). The library's default is 1100 ms and begin() retries its
// ping 3x internally, so a failing probe blocks 3 x maxWait with no way
// to pet the ~4 s hardware watchdog in between — 1100 ms leaves a <15%
// margin. Modern modules answer in tens of ms (the library notes 250 ms
// is safe); 550 ms keeps a failed begin() at ~1.65 s, half the WDT budget.
#define GPS_PROBE_MAXWAIT_MS 550
#define GPS_SERIAL         Serial1

// TIMER3 GPS drain period (µs, 1 MHz tick). At 57600 baud ≈ 5.76
// bytes/ms line rate, a 5 ms period accumulates ~29 bytes per fire —
// under half the core Serial1 RX ring even at its stock 64 B — so a
// SoftDevice radio-ISR deferral of the drain has ~6 ms of slack before
// the core ring can overflow (~1 ms at the old 10 ms period, which is
// exactly where the scanner/camera-era PVT drops came from). The ISR
// body is µs-scale, so doubling its rate costs nothing measurable.
#define GPS_DRAIN_INTERVAL_US 5000

#endif

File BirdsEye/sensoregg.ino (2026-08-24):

///////////////////////////////////////////
// SENSOREGG MODULE (wireless EGT pod — passive BLE observer)
//
// Receives the DovesSensorEgg's PW-ADV broadcasts (v1 and v2) and
// exposes the latest readings. See sensoregg.h for the role,
// pairing, and threading contracts, and sensoregg_protocol.{h,cpp}
// (host-tested) for the byte layout and staleness rule.
//
// The scanner is a pure passive OBSERVER: no SCAN_REQ, no connection, so
// it cannot contend with the Insta360 X4 camera link for TX airtime.
// S140 time-slices scan windows around existing connection events.
//
// Cross-module globals (Bluefruit) are visible via Arduino's .ino
// concatenation — same as camera_ble.ino relies on.
///////////////////////////////////////////

#include "sensoregg.h"

#include <math.h>
#include <string.h>

#include "project.h"

#if BIRDSEYE_ENABLE_SENSOREGG

#include "bluetooth.h"  // bleCoreEnsureInit()
#include "sensoregg_protocol.h"

// Forward declaration: the callback signature mentions a SoftDevice type,
// and Arduino's auto-prototype generator inserts prototypes BEFORE
// <bluefruit.h> is included — an explicit prototype makes arduino-cli
// skip generating one (same workaround as camera_ble.ino).
static void sensoreggScanCallback(ble_gap_evt_adv_report_t* report);

///////////////////////////////////////////
// MODULE STATE
///////////////////////////////////////////

// Hardcoded egg MAC (human order, see sensoregg.h). All-zeros = accept
// any PW-ADV-1 broadcaster (POC: exactly one egg exists).
static const uint8_t kSensorEggMac[6] = SENSOREGG_MAC;

// ---- RX double-buffer (BLE scan callback fills, SENSOREGG_LOOP drains;
// mirrors camera_ble.ino's ce81 idiom: payload arrays are plain RAM, the
// per-slot ready flags are the synchronization points) ----
static uint8_t           eggBuf[2][sensoregg_protocol::kPayloadLenMax];
static volatile uint8_t  eggLen[2] = {0, 0};   // actual bytes captured
static volatile uint32_t eggAtMs[2] = {0, 0};
static volatile bool     eggReady[2] = {false, false};
static volatile uint8_t  eggWriteIdx = 0;  // callback writes (Bluefruit task)
static uint8_t           eggReadIdx = 0;   // main loop reads

// Latest parsed reading (main-loop context only).
static sensoregg_protocol::Reading eggReading;
static uint32_t eggRxMs = 0;
static bool     eggHaveReading = false;
static sensoregg_protocol::SeqMonitor eggSeqMon;  // zombie-egg detection

static bool eggScannerRunning = false;
static bool eggSetupDone = false;   // scanner configured — SENSOREGG_LOOP may (re)start it
// Sleep gate, read by the scan callback (BLE task): a report accepted just
// before SENSOREGG_SLEEP() has its rx callback deferred, and the callback's
// mandatory Scanner.resume() would restart the scan AFTER the stop (the
// core's resume() never checks the running flag) — the scanner then runs
// through the entire charging park. volatile: written on the main loop,
// read in BLE task context.
static volatile bool eggSleeping = false;
static uint32_t eggLastKickMs = 0;      // last scanner self-heal kick (main loop)
static uint32_t eggLastStartTryMs = 0;  // last start attempt (retry throttle)

// Throttle for retrying a start() the SoftDevice refused, so a persistent
// refusal costs one SVC per second instead of one per ~4 ms loop iteration.
static constexpr uint32_t kEggStartRetryMs = 1000;

// RACE-GATED SCANNER (plan 0012). The scanner's 40-of-every-90 ms radio
// claim is only paid while a race session is running — the one time the EGT
// feed is actually consumed (DOVEX rows + the Temp pages are race-only).
// Outside race mode the radio belongs to whoever needs it clean: the
// always-on scan was measured throttling BLE file downloads to ~33 KB/s by
// denying the transfer link's connection-event extension. raceActive is the
// BirdsEye.ino session flag, visible via the .ino concatenation (same as
// Bluefruit above). Read from the scan callback (BLE task) too — a plain
// bool read is atomic on this core, and a stale read only delays the
// stop/start by one report (the main-loop reconcile owns the real state).
static bool eggScanWanted() {
  return raceActive && !eggSleeping;
}

///////////////////////////////////////////
// SCAN CALLBACK (Bluefruit task context — copy bytes, resume, return)
///////////////////////////////////////////

// True when the reporting advertiser is our egg. nRF ble_gap_addr_t
// stores the address LSB-first, the #define is human-ordered (MSB
// first) — compare reversed. All-zeros define = accept anyone (the
// payload magic already filtered).
static bool sensoreggMacAccepted(const uint8_t* peerAddrLsbFirst) {
  bool filterActive = false;
  for (int i = 0; i < 6; i++) {
    if (kSensorEggMac[i] != 0x00) {
      filterActive = true;
      break;
    }
  }
  if (!filterActive) return true;
  for (int i = 0; i < 6; i++) {
    if (peerAddrLsbFirst[i] != kSensorEggMac[5 - i]) return false;
  }
  return true;
}

static void sensoreggScanCallback(ble_gap_evt_adv_report_t* report) {
  // NO Serial, NO SD, NO display, NO delay() here — BLE task context.
  uint8_t buf[BLE_GAP_ADV_SET_DATA_SIZE_MAX];
  uint8_t len = Bluefruit.Scanner.parseReportByType(
      report, BLE_GAP_AD_TYPE_MANUFACTURER_SPECIFIC_DATA, buf, sizeof(buf));

  if (len >= sensoregg_protocol::kPayloadLen &&
      sensoregg_protocol::matchesMagic(buf, len) &&
      sensoreggMacAccepted(report->peer_addr.addr)) {
    const uint8_t w = eggWriteIdx;
    // Capture up to the largest known layout; the parser applies the
    // per-version length gate. (The old fixed-14 copy silently truncated
    // v2 frames — bytes 14-15 never reached the parser.)
    const uint8_t copyLen =
        len < sensoregg_protocol::kPayloadLenMax
            ? len
            : (uint8_t)sensoregg_protocol::kPayloadLenMax;
    memcpy(eggBuf[w], buf, copyLen);
    eggLen[w] = copyLen;
    eggAtMs[w] = millis();
    eggReady[w] = true;
    eggWriteIdx = w ^ 1;
  }

  // MANDATORY: without resume() the scanner halts after the first report
  // — symptom is exactly one reading then permanent silence,
  // indistinguishable from a dead egg. Skipped while the scan is not
  // wanted (sleeping, or race over): this deferred callback may run AFTER
  // a Scanner.stop(), and resume() restarts the scan unconditionally —
  // resurrecting the scanner the stop just killed.
  if (eggScanWanted()) {
    Bluefruit.Scanner.resume();
  }
}

///////////////////////////////////////////
// LIFECYCLE
///////////////////////////////////////////
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

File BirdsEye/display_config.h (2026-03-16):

#ifndef _DOVES_DISPLAYCONFIG_H
#define _DOVES_DISPLAYCONFIG_H
  #ifndef I2C_DISPLAY_ADDRESS
    #define I2C_DISPLAY_ADDRESS 0x3C
  #endif

  #ifndef SCREEN_WIDTH
    #define SCREEN_WIDTH 128
  #endif

  #ifndef SCREEN_HEIGHT
    #define SCREEN_HEIGHT 64
  #endif

  #include <Adafruit_GFX.h>

  #ifdef USE_1306_DISPLAY
    #include <Adafruit_SSD1306.h>
    #define DISPLAY_TEXT_WHITE SSD1306_WHITE
    #define DISPLAY_TEXT_BLACK SSD1306_BLACK
    #define OLED_RESET -1 // reccomended to use reset pin, not required
    Adafruit_SSD1306 display(SCREEN_WIDTH, SCREEN_HEIGHT, &Wire, OLED_RESET);
  #else
    #include <Adafruit_SH110X.h>
    #define DISPLAY_TEXT_WHITE SH110X_WHITE
    #define DISPLAY_TEXT_BLACK SH110X_BLACK
    #define OLED_RESET -1
    Adafruit_SH1106G display = Adafruit_SH1106G(SCREEN_WIDTH, SCREEN_HEIGHT, &Wire, OLED_RESET);
  #endif

  // Display sleep/wake macros (~10uA sleep vs 10-30mA active)
  // Framebuffer stays in controller RAM — no re-render needed on wake
  #ifdef USE_1306_DISPLAY
    #define DISPLAY_SLEEP() display.ssd1306_command(SSD1306_DISPLAYOFF)
    #define DISPLAY_WAKE()  display.ssd1306_command(SSD1306_DISPLAYON)
  #else
    #define DISPLAY_SLEEP() display.oled_command(SH110X_DISPLAYOFF)
    #define DISPLAY_WAKE()  display.oled_command(SH110X_DISPLAYON)
  #endif
#endif

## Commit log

2023-06-21 Added super basic error handling, error pages, and can now read track data from SD card
    [BirdsEye.ino, gps_config.h]
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2025-12-30 Fix SD card corruption and EMI issues from ignition system
    Critical fixes for electromagnetic interference causing SD card init
    failures and data corruption when datalogger runs with engine:
    - Made tachLastReported volatile to fix race condition between ISR
    and main loop during SD writes
    - Reduced SPI speed from 25MHz to 4MHz for better noise immunity
    - Added retry logic (3 attempts) to SD card initialization
    - Added error checking on all SD card writes with user notification
    - Reduced flush interval from 10s to 2s to minimize data loss
    - Removed O_NONBLOCK flag that doesn't work properly on SD cards
    These changes make the system more resilient to EMI from ignition
    coil, but hardware fil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
    [BirdsEye.ino]
2025-12-30 Prevent interrupt storm from noisy tach inductive pickup
    The tachometer uses a crude capacitive/inductive pickup that generates
    hundreds of errant pulses per ignition event. Previously, the ISR ran
    on EVERY interrupt and checked timing in software, which still caused
    massive interrupt overhead that disrupted SPI communication.
    Now using an interrupt gate pattern:
    - After accepting a valid pulse, set tachInterruptShouldProcess = false
    - ISR checks this flag FIRST and returns immediately if false
    - TACH_LOOP() re-enables processing after tachMinPulseGapUs (2000us)
    This reduces interrupt overhead by ~99% during engine operation:
    - Before: ISR runs hundreds of times per ignition event
    - After: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
    [BirdsEye.ino]
2025-12-30 Fix race condition in TACH_LOOP interrupt re-enable
    The interrupts() call was happening before tachInterruptShouldProcess
    was set to true, creating a window where valid pulses could be rejected.
    Before:
    noInterrupts()
    read elapsed time
    interrupts() <- Race window starts here!
    if (elapsed >= threshold)
    set flag = true <- Race window ends here
    If a tach interrupt fired in the race window, it would be rejected
    even though we had already determined enough time had passed.
    After:
    noInterrupts()
    read elapsed time
    if (elapsed >= threshold)
    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
    [BirdsEye.ino]
2025-12-30 Fix interrupt re-enable logic in TACH_LOOP
    Interrupts must only be re-enabled when the flag is set to true,
    not on every loop iteration. Previous code was calling interrupts()
    unconditionally after checking elapsed time, even when the flag
    remained false.
    Correct flow:
    1. ISR disables interrupt processing and calls noInterrupts()
    2. Interrupts remain disabled during entire dead-time window
    3. TACH_LOOP only re-enables when elapsed >= tachMinPulseGapUs
    4. Flag and interrupts() are set atomically in same conditional
    This completely gates the interrupt storm - no interrupts fire
    at all during the 2000us window after each valid pulse.
    Also removed unnecessary noInterrupts()/interrupts() pair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
    [BirdsEye.ino]
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2026-01-01 Implement custom CSV logging format with .dove extension
    Replace NMEA pass-through logging with custom CSV format for better
    data efficiency and easier parsing in analysis tools.
    Features:
    - Filter to GPGGA packets only (25x smaller files, ~25Hz logging)
    - Custom .dove file extension for brand identity
    - CSV format with self-documenting header row
    - Unix timestamp for universal compatibility
    - Racing-grade precision: 8 decimals for lat/lng
    - Fields: timestamp,sats,hdop,lat,lng,speed_mph,alt_m,rpm,egt,
    water_temp,reserved1,reserved2
    - Placeholders for future sensors (EGT, water temp)
    - Reserved columns for expansion
    Data precision:
    - Timestamp: Unix seconds (integer)
    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
    [BirdsEye.ino]
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2026-01-03 Add millisecond precision to Unix timestamps in CSV logs
    - Added getGpsUnixTimestampMillis() function that returns timestamps in milliseconds
    - Updated CSV logging to use millisecond timestamps instead of second precision
    - Changed format specifier from %lu to %llu to support 64-bit timestamps
    - Fixes issue where multiple GPS fixes per second had identical timestamps
    - GPS configured for 25Hz means 25 fixes/second, now each has unique timestamp
    [BirdsEye.ino]
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2026-01-20 Fix BLE code placement - move functions after SdFat include
    BLE functions that use File32, SD, and FILE_READ must be placed
    after the SdFat library is included. Moved all BLE functions to
    after the SD card setup section to fix compilation errors.
    Also added forward declaration for bleFileRequestCallback to
    ensure proper callback signature matching.
    [BirdsEye.ino]
2026-01-20 Optimize BLE transfer speed with tight loop during active transfer
    When a BLE transfer is in progress, skip GPS_LOOP(), displayLoop(),
    and other heavy processing to maximize throughput. This restores
    the ~45kbps transfer speed by running a tight loop that only handles:
    - BLUETOOTH_LOOP() for actual data transfer
    - TACH_LOOP() for RPM auto-exit detection
    - Minimal button check for emergency exit
    The original working code had a dedicated loop for BLE transfer.
    This change replicates that behavior during active transfers.
    [BirdsEye.ino]
2026-01-20 Add display update during BLE transfer to show progress percentage
    The display wasn't updating during transfers because the tight loop
    skipped displayLoop() for speed. Now calls displayPage_bluetooth()
    every 333ms (3Hz) during transfer to show progress without
    significantly impacting throughput.
    [BirdsEye.ino]
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2026-01-21 Add Replay feature for fast, memory-efficient session rebuild
    This feature allows users to select a past datalog from the SD card and
    rebuild session analytics (lap times, max speed, max RPM) without loading
    the full log into RAM.
    Key features:
    - New "Replay" option in main menu (Race / Replay / Download)
    - File picker for .dove and .nmea session files
    - Automatic track detection using GPS point comparison (20 mile threshold)
    - Manual track selection fallback if auto-detection fails
    - Streaming file parsers for bounded memory usage:
    - DOVE CSV parser (timestamp, lat, lng, speed, rpm)
    - NMEA parser (GGA and RMC sentences)
    - Full integration with DovesLapTimer for lap detection and stats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
    [BirdsEye.ino]
2026-01-21 Fix compilation errors: move File declarations after SdFat include
    - Move File replayFile and File-dependent function prototypes to after
    SdFat.h include so the File type is defined
    - Remove DEG_TO_RAD constant definition since Arduino already provides it
    [BirdsEye.ino]
2026-01-21 Fix file opening to use .open() method consistently
    Use file.open() instead of SD.open() to match the pattern used
    throughout the rest of the codebase. This fixes potential issues
    with file handle behavior during replay processing.
    [BirdsEye.ino]
2026-01-21 Optimize replay file reading with block-based I/O
    Performance improvements:
    - Add 512-byte block buffer for SD reads (one sector at a time)
    - Rewrite readReplayLine to use block buffer instead of char-by-char
    - Increase lines processed per iteration from 50 to 200
    - Reduce display update frequency from 200ms to 500ms
    - Reset block buffer before starting replay to avoid stale data
    This should significantly speed up replay processing by reducing
    the number of SPI transactions from one per character to one per
    512-byte block.
    [BirdsEye.ino]
2026-01-21 Revert block I/O, fix replay UI and button controls
    Reverts:
    - Remove block-based I/O (caused memory issues and was slower)
    - Back to character-by-character reading with 50 lines/iteration
    UI improvements:
    - Results page now shows best lap number: "Best: 45.123 (L3)"
    - Results page shows optimal lap with sector numbers if track has
    sectors: "Opt: 44.567 (3,8,9)"
    - Shortened "Max Speed" to "Max Spd" to fit more info
    Button control fixes:
    - Results page: Left -> Lap list, Right -> Exit page
    - Lap list (replay): Left/Right -> back to Results, Middle -> cycle pages
    - Added dedicated Exit confirmation page with Back/Exit options
    - Middle button no longer used for page navigation on results
    [BirdsEye.ino]
2026-01-21 Fix replay file handle checking with isOpen()
    - Use replayFile.isOpen() instead of boolean conversion for proper
    SdFat file state checking
    - Move isDove determination outside the loop (optimization)
    - Add debug message when file becomes invalid during processing
    - This should fix the issue where processing stops mid-file
    [BirdsEye.ino]
2026-01-21 Fix memory issues causing replay to stop mid-file
    Major memory savings:
    - replayFiles: 50*64=3200 → 20*32=640 bytes (saves 2560 bytes)
    - replayLineBuffer: 256 → 128 bytes (saves 128 bytes)
    - parseDoveLine: removed 256-byte stack allocation (was copying line)
    - parseNmeaSentence: removed 256-byte stack allocation (was copying line)
    Total savings: ~2700 bytes static + 256 bytes stack per parse call
    The parsers now modify the line buffer in-place using strtok, which is
    safe since we don't need the original line after parsing. This prevents
    stack overflow that was occurring after ~22-26k samples.
    NMEA lines are max 82 chars by spec, DOVE CSV lines ~100 chars, so
    128-byte buffer is suffici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
    [BirdsEye.ino]
2026-01-21 Add defensive file handle cleanup for SD card stability
    - Close any stale replayFile and file handles before building file list
    - Add warning if dataFile is open during replay (potential conflict)
    - Add small delay before SD operations to let card settle
    - Add debug logging when closing file handles
    [BirdsEye.ino]
2026-01-21 Add debug output for replay file listing issue
    - Log when root directory is opened
    - Log how many files were scanned before openNextFile returns null
    - Close trackDir and trackFile handles defensively before scanning
    - Increase settle delay from 10ms to 50ms
    [BirdsEye.ino]
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2026-01-31 Fix critical bugs: interrupt deadlock, buffer overflow, GPS null safety
    Phase 1 critical fixes:
    1. INTERRUPT DEADLOCK FIX (root cause of page-freeze bug)
    - Removed noInterrupts() call from TACH_COUNT_PULSE ISR
    - ISR was disabling ALL system interrupts, and if main loop was
    delayed (e.g., during SD write), interrupts() never got called
    - Now uses purely volatile flag gating - no system-wide interrupt disable
    - Added detailed EMI/hardware shielding recommendations in comments
    2. BUFFER OVERFLOW FIX
    - Fixed char filepath[13] -> filepath[50] at location selection
    - makeFullTrackPath creates paths up to 27 bytes, was overflowing
    - Added FILEPATH_MAX constant for consis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
    [BirdsEye.ino]
2026-01-31 Memory safety and SD race condition prevention
    Phase 2 improvements:
    1. STRNCPY BUFFER OVERFLOW FIX
    - Fixed strncpy at location loading: was using sizeof(source) instead
    of sizeof(destination), could overflow 13-byte buffer with 25-byte source
    - Added explicit null-termination to ensure string safety
    2. STANDARDIZED FILEPATH BUFFER SIZES
    - Added FILEPATH_MAX constant (50 bytes) for consistent sizing
    - Updated all filepath[] declarations to use FILEPATH_MAX
    - Single point of change if path requirements ever increase
    3. SD CARD ACCESS STATE MANAGEMENT
    - Added SDAccessMode enum to track which subsystem owns SD access
    - Added acquireSDAccess()/releaseSDAccess() funct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
    [BirdsEye.ino]
2026-01-31 Button hardening: multi-sample debouncing and EMI recommendations
    Phase 3 improvements for phantom button press prevention:
    1. MULTI-SAMPLE BUTTON VERIFICATION
    - New readButtonMultiSample() function takes 3 samples with 500μs delays
    - ALL samples must show LOW (pressed) to register a button press
    - Single EMI spike causing one false LOW reading is rejected
    - Total sampling window: ~1ms (negligible latency)
    2. IMPROVED DEBOUNCE TIMING
    - Reduced antiBounceIntv from 500ms to 150ms
    - Allows ~6 button presses per second (was only 2/sec)
    - Much more responsive menu navigation
    - Multi-sample verification handles noise rejection instead of long timeout
    3. HARDWARE EMI REC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
    [BirdsEye.ino]
2026-01-31 Fix GPS data logging corruption and final polish
    Phase 4 - Data integrity and final cleanup:
    1. GPS DATA TORN READ FIX (Root cause of CSV corruption)
    - On 32-bit ARM, reading 64-bit doubles is NOT atomic
    - GPS library could update gps->latitudeDegrees mid-read
    - Result: half old value + half new value = "C"²ëB" garbage
    - Fix: Snapshot all GPS values with interrupts disabled
    - Applied to both CSV logging AND lap timer updates
    2. GPS DATA VALIDATION
    - Added range checks before logging:
    * Latitude: -90 to 90
    * Longitude: -180 to 180
    * Altitude: -1000m to 50000m
    * HDOP: 0 to 99.9
    * Speed: 0 to 500 mph
    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
    [BirdsEye.ino]
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2026-01-31 Fix Arduino IDE enum preprocessor issue
    Arduino's preprocessor generates function prototypes before processing
    enum definitions, causing "SDAccessMode not declared" errors.
    Fix: Changed from enum to #define constants with int parameters.
    Functionally identical, but compatible with Arduino's quirky preprocessor.
    https://claude.ai/code/session_019xucVnNpeYDjhLXySPXbyA
    [BirdsEye.ino]
2026-01-31 Fix button rapid-fire: add edge detection
    Problem: With 150ms debounce, buttons were firing repeatedly while held
    because the code only checked if button was LOW, not if it had been released.
    Fix: Added edge detection via wasReleased flag in ButtonState.
    - Button must transition from released→pressed to register
    - Holding button down no longer causes repeated triggers
    - Increased debounce to 200ms for stability
    Before: Press and hold = fires every 150ms
    After: Press and hold = fires once, must release to fire again
    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
    [BirdsEye.ino]
2026-01-31 Fix CSV data corruption: %llu not supported on Arduino
    Root cause identified: Arduino's snprintf on NRF52840 doesn't support
    %llu format specifier for 64-bit integers. This caused the literal
    "lu,0,," garbage appearing in CSV output.
    - Manual 64-bit to string conversion for timestamp (avoids %llu)
    - Strengthened GPS validation (require satellites > 0, lat/lng != 0)
    - Added NaN/Inf checks on all GPS values
    - Added string validation after dtostrf to catch garbage characters
    - Fixed indentation in error handling block
    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
    [BirdsEye.ino]
2026-01-31 Fix missing closing brace in GPS_LOOP
    Added missing } to close the GPGGA if block.
    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
    [BirdsEye.ino]
2026-02-15 Fix session save bug and add logging status indicator
    Move sdDataLogInitComplete=true inside the success branch so it
    is not set when file open fails. Previously it was set regardless
    of success/failure, which could prevent subsequent sessions from
    creating log files within the same power cycle.
    Add REC/... indicator to the speed page so the rider can see at a
    glance whether data is actively being written to SD or still
    waiting for GPS conditions.
    https://claude.ai/code/session_01HUoAKgmX8WKdk6zNVFS8bh
    [BirdsEye.ino]
2026-02-15 Fix BLE file listing truncated at ~5 files due to heap fragmentation
    bleSendFileList() was building the entire file list as an Arduino String
    via repeated += concatenation. On the NRF52840 with BLE/GPS/display all
    competing for heap, String::concat() silently fails when allocation
    fails - no error, just stops adding entries. This caused the webapp to
    consistently show only ~5 files even when more existed on the SD card.
    Fix: stream each file entry directly over BLE using a fixed stack buffer
    (snprintf into char[]) instead of accumulating into a heap-allocated
    String. Also adds graceful BUSY response if root directory can't be opened.
    Additionally:
    - Add seconds to log filenames (HHMM -> HH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
    [BirdsEye.ino]
2026-02-15 Remove REC indicator from speed page, improve info page SD status
    Speed page is for riding - removed the REC/... overlay that was
    cluttering it. The info page already shows logging status.
    Info page SD status now covers all states:
    - "Bad Init" - SD card failed to initialize
    - "Logging" - actively writing data
    - "Waiting GPS" - logging enabled but waiting for GPS fix/date
    - "Ready" - SD card is good, no active logging session
    Previously the idle state (not logging, SD fine) showed blank.
    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
    [BirdsEye.ino]
2026-02-16 Fix logging rate dropping to 2-5Hz instead of 25Hz
    GPGGAOn10 was throttling GPGGA messages to every 10th nav packet,
    reducing actual log rate to ~2.5Hz at 25Hz nav rate. Commented out the
    throttle so GPGGA comes every packet. Also added GPGGAOn1 config option
    for explicit every-packet control.
    Relaxed validation filters: removed HDOP upper bound (any positive HDOP
    now logs - value is in CSV for post-filtering), changed lat/lng zero
    check to only reject when BOTH are zero (no fix computed) rather than
    either individually.
    https://claude.ai/code/session_01KEQUwERjKctpKFDwmAn1rW
    [BirdsEye.ino, gps_config.h]
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2026-02-21 Fix jagged GPS data: drain serial buffer instead of reading 1 char/loop
    The previous code read only one GPS serial character per loop() iteration.
    At 25Hz nav rate, the GPS sends ~50 NMEA sentences/sec (~4000 chars/sec).
    During display updates (SPI, ~30ms) and SD writes/flushes (up to 100ms),
    the nRF52840's 256-byte serial buffer overflowed, corrupting mid-sentence
    NMEA data. Dropped GPRMC sentences caused stale speed values; dropped
    GPGGA sentences created position gaps - both producing jagged traces and
    broken G-force calculations.
    Fix: wrap gps->read() in a while(GPS_SERIAL.available()) loop to drain all
    pending characters each GPS_LOOP() call, with a 512-char safety cap.
    Also removed u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
    [BirdsEye.ino]
2026-02-21 Increase SD flush interval from 2s to 10s to reduce main loop blocking
    The SdFat flush() call blocks while writing cached data to the SD card,
    which stalls the main loop and can cause missed GPS packets at 25Hz.
    Increasing the interval to 10 seconds reduces this impact while still
    protecting against data loss on power cut.
    https://claude.ai/code/session_013yTdhvxdj7XTHsgmMzC2Az
    [BirdsEye.ino]
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2026-02-22 Add project.h header to fix Arduino prototype generation errors
    Arduino's preprocessor auto-generates function prototypes from .ino
    files and inserts them at the top of the main sketch -- before struct
    definitions. This caused "ButtonState was not declared" errors for
    functions like resetButton() and checkButton().
    Fix: move ButtonState, TrackLayout, ReplaySample structs and the
    debug macros into project.h, included at the very top of BirdsEye.ino
    so the types exist before any auto-generated prototypes.
    https://claude.ai/code/session_01GKDFfDrsphh5uMLi3nybr8
    [BirdsEye.ino, project.h]
2026-02-22 Fix GPS frame rate counting all NMEA sentences instead of only GGA
    The gpsFrameCounter was incrementing for every parsed NMEA sentence
    (both GPRMC and GPGGA), doubling the reported Hz on the debug page.
    Now only counts GPGGA/GNGGA sentences, which represent the actual
    GPS position fix rate.
    https://claude.ai/code/session_01913fsyzwT2h35Afdh3NtX6
    [gps_functions.ino]
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2026-02-22 Replace Adafruit NMEA GPS with SparkFun UBX PVT binary protocol
    Switch from Adafruit_GPS NMEA text parsing to SparkFun u-blox GNSS v3
    library using UBX binary PVT messages. This eliminates ASCII string
    parsing overhead and provides a cleaner configuration API via VALSET
    commands instead of raw hex byte arrays.
    - BirdsEye.ino: Replace Adafruit_GPS pointer with SFE_UBLOX_GNSS_SERIAL
    stack object, add GpsData cache struct for PVT data
    - gps_config.h: Gut all PROGMEM byte arrays, replace with 3 constants
    - gps_functions.ino: Rewrite GPS_SETUP() with SparkFun begin/VALSET API
    (auto baud detection, 25Hz nav, GPS-only, automotive model, autoPVT);
    rewrite GPS_LOOP() from char-by-char NMEA to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
    [BirdsEye.ino, display_pages.ino, gps_config.h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]
2026-02-23 Add heading and horizontal accuracy to CSV, remove unused temp columns
    Replace the placeholder exhaust_temp_c/water_temp_c columns (always 0,0)
    with heading_deg (from UBX headMot) and h_acc_m (from UBX hAcc). This
    gives the data viewer the heading data needed to orient the kart icon
    and lets post-processing filter on GPS accuracy.
    New CSV format:
    timestamp,sats,hdop,lat,lng,speed_mph,altitude_m,heading_deg,h_acc_m,rpm
    [BirdsEye.ino, gps_functions.ino, replay.ino]
2026-02-23 Fix intermittent button lockup and improve stability in EMI environments
    Add hardware watchdog, I2C bus recovery, eliminate heap-fragmenting String
    usage, remove blocking delays from BLE callbacks, fix SD thread safety,
    and reduce stack usage in JSON parsing.
    [BirdsEye.ino, bluetooth.ino, display_pages.ino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]
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2026-03-03 switched to sense board, Added accel data to logs, fixed tach bug, and other cleanup
    [BirdsEye.ino, accelerometer.ino, gps_functions.ino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]
2026-03-03 Fix analogRead killing I2C SDA, add tach median filter and accel rate-limiting
    - Fix critical bug: analogRead(A4) permanently disables digital input
    buffer on pin 4 (SDA), killing OLED I2C. Use micros() for random
    seed instead — all analog pins on XIAO are dual-purpose critical GPIO.
    - Add median-of-3 filter to tachometer before EMA to reject single-pulse
    noise spikes from ignition ringing that slip past 3ms debounce.
    - Discard first tach period after engine-stopped timeout (garbage value).
    - Rate-limit accelerometer reads to 50 Hz (was ~250 Hz every loop).
    - Re-comment HAS_DEBUG for production use.
    [BirdsEye.ino, accelerometer.ino, tachometer.ino]
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2026-03-07 Reduce SPI and UART speeds for better EMI hardening
    GPS UART: 115200 → 57600 baud (43% utilization at 25 Hz PVT, doubles bit width)
    SD SPI: 4 MHz → 1 MHz (still 50x headroom for logging, 5x for BLE transfers)
    [BirdsEye.ino, gps_config.h, gps_functions.ino]
2026-03-11 Implement "Just Drive" overhaul with ENABLE_NEW_UI feature flag
    All new behavior gated behind #define ENABLE_NEW_UI. Legacy flow
    preserved unchanged when not defined. Both modes compile clean.
    Core changes:
    - CourseManager integration: auto track detection via haversine
    proximity matching against in-RAM track manifest (1000 entries)
    - DOVEX logging: 8KB reserved header with crash-safe GPS data,
    column labels for Excel friendliness, instant replay from header
    - Auto-race: enters race mode at 10+ mph or 500+ RPM from menu
    - Auto-idle: ends session after 60s below 2 mph
    - Active timer abstraction: unified helper functions for display
    pages to read from DovesLapTimer or WaypointLapTimer t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
    [BirdsEye.ino, bluetooth.ino, display_pages.ino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]
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
